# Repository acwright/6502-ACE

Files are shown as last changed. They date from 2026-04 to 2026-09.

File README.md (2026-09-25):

6502-ACE
========

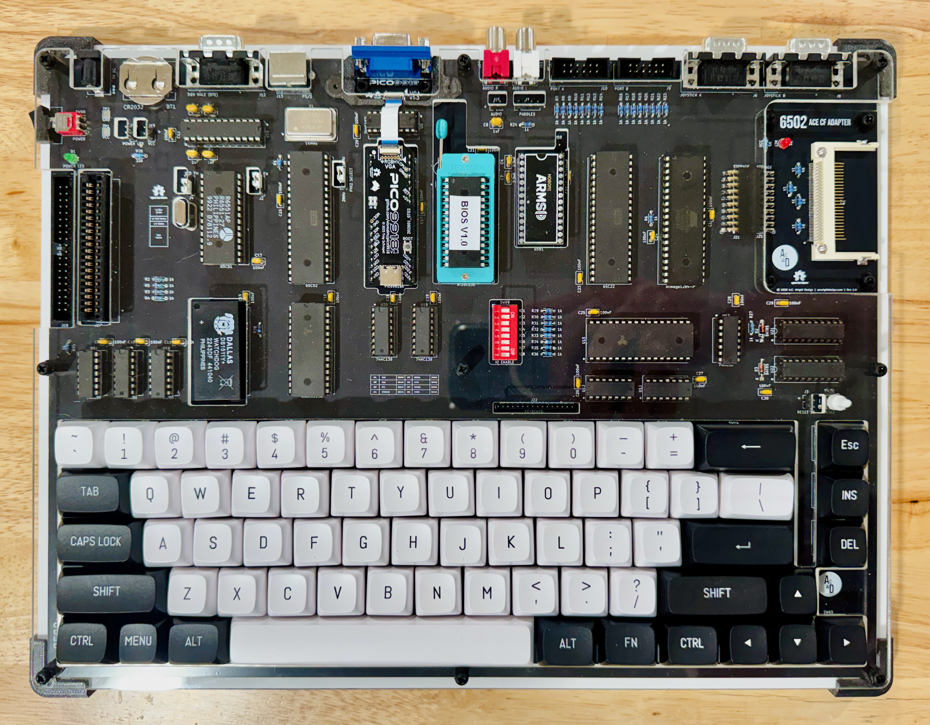
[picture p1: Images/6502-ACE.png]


An **AC6502** retro-style 8-bit computer based on the **65C02** microprocessor.

> 📖 **Guide:** [AC6502 Documentation](https://acwright.github.io/6502-DOCS/) — the user's and programmer's guide for the whole family.
> Start with [Your ACE](https://acwright.github.io/6502-DOCS/your-ace), the tour of this board.

---

## Table of Contents

- [Overview](#overview)
- [Architecture](#architecture)
- [Systems](#systems)
- [Software](#software)
- [Hardware](#hardware)
  - [ACE Board](#ace-board)
    - [Revision History](#revision-history)
  - [ACE CF Adapter](#ace-cf-adapter)
  - [ACE RAM Patch](#ace-ram-patch)
- [Firmware](#firmware)
  - [AB Controller](#ab-controller)
- [CAD](#cad)
- [Production](#production)
- [Schematics](#schematics)
- [Checking the schematics](#checking-the-schematics)
- [Libraries](#libraries)
- [Bill of Materials](#bill-of-materials)
  - [ACE Board](#ace-board-1)
  - [ACE CF Adapter](#ace-cf-adapter-1)
  - [ACE RAM Patch](#ace-ram-patch-1)
- [License](#license)

---

## Overview

The AC6502 ecosystem is a family of open-source, 65C02-based computers sharing a common architecture, memory map, and [BIOS](https://github.com/acwright/6502-BIOS). Each computer in the family is purpose-built for a different use case but runs the same software and firmware.

The **ACE** (All-in-one Computer Experience) is a complete, self-contained 65C02 computer on a single PCB. It integrates everything found across the COB's modular cards — CPU, memory, video, audio, storage, serial, GPIO, RTC, and keyboard controller — onto one board, delivering the full experience without a backplane or expansion cards.

## Architecture

All AC6502 computers share:

- **CPU**: 65C02 (or accurate emulation)
- **Memory**: 32KB RAM + 32KB ROM, with optional banked RAM expansion
- **Memory Map**: Standardized across the ecosystem — zero page, stack, I/O space ($8000–$9FFF), system ROM, and interrupt vectors at $FFFA–$FFFF
- **Bus**: 16-bit address bus, 8-bit bidirectional data bus, standard 65C02 control signals (RW, PHI2, RESET, IRQ, NMI, RDY, SYNC)
- **BIOS**: A common [BIOS](https://github.com/acwright/6502-BIOS) provides the kernel, monitor, and BASIC interpreter across all systems

## Systems

| Project | Description |
|---|---|
| [6502-ACE](https://github.com/acwright/6502-ACE) | All-in-one Computer Experience — A single board computer (YOU ARE HERE) |
| [6502-COB](https://github.com/acwright/6502-COB) | Computer On a Backplane — Modular desktop computer with expandable card slots |
| [6502-DEV](https://github.com/acwright/6502-DEV) | Development Environment Vehicle — Emulation-based dev system |
| [6502-KIM](https://github.com/acwright/6502-KIM) | Keypad Input Monitor - KIM-1 inspired minimal computer |
| [6502-VCS](https://github.com/acwright/6502-VCS) | Video Computer System — Cartridge-based retro gaming console |

## Software

| Project | Description |
|---|---|
| [6502-BIOS](https://github.com/acwright/6502-BIOS) | The shared BIOS (kernel, monitor, BASIC) for all AC6502 computers |
| [6502-EMULATOR](https://github.com/acwright/6502-EMULATOR) | Emulator for the whole family — desktop app, browser build, and a command line for scripted runs |
| [6502-PRG](https://github.com/acwright/6502-PRG) | Template project for writing assembly language programs |
| [6502-CRT](https://github.com/acwright/6502-CRT) | Template project for writing assembly language cartridges |
| [6502-ASM](https://github.com/acwright/6502-ASM) | Assembly language example programs and demos |
| [6502-BAS](https://github.com/acwright/6502-BAS) | BASIC program listings |
| [6502-WOZMON](https://github.com/acwright/6502-WOZMON) | Wozmon as a standalone ROM |
| [6502-NOP](https://github.com/acwright/6502-NOP) | An all-NOP ROM, for probing a board during bring-up |
| [6502-DOCS](https://github.com/acwright/6502-DOCS) | The documentation site — the guide, the printable reference cards, branding and label artwork |
| [cffs](https://github.com/acwright/cffs) | Builds CompactFlash disk images for the BIOS filesystem |
| [bastok](https://github.com/acwright/bastok) | Tokenizes BASIC listings into `.prg` images, and back |
| [bin2woz](https://github.com/acwright/bin2woz) | Converts a binary into a Wozmon serial upload |

## Hardware

This repository contains KiCad 7.0+ PCB designs for the ACE board.

### ACE Board
`Hardware/ACE Board/`

The single integrated board hosting the W65C02S CPU and all peripherals. Provides:

- **CPU**: W65C02S running at 1 MHz
- **RAM**: 32KB SRAM (62256) + Optional 512K banked SRAM (AS6C4008)
- **ROM**: 32KB EEPROM (28C256)
- **Video**: Pico9918 (VGA 640×480)
- **Audio**: ARMSID SID chip emulator (3-voice synthesis, RCA output)
- **Storage**: Storage adapter socket
- **Serial**: 65C51 ACIA with MAX238 level shifter (RS-232 via DB9, 50–19200 baud). Male DB-9 wired
  as **DTE**, like a PC, so reaching a laptop needs a **null-modem** cable. `RTS`, `DTR` and `DSR`
  always reach the cable; the `CTS EN` and `DCD EN` jumpers (J2 and J4 on Rev 1.0, J1 and J3 on Rev 1.1) pick ground or the cable for
  those two inputs — **both default to ground**
- **GPIO**: 65C22 VIA (20 GPIO pins, 2× 16-bit timers, shift register)
- **RTC**: DS1511Y real-time clock with battery-backed NVRAM
- **Keyboard Controller**: ATmega1284P running AB Controller firmware
- **Input**: PS/2 keyboard connector and 8×8 keyboard matrix header
- **Joystick**: Two Atari 2600-compatible joystick ports (JOYSTICK A on VIA PORT A and JOYSTICK B on VIA PORT B — `J6` and `J8` on Rev 1.0, `J5` and `J7` on Rev 1.1), read as `JOY(2)` and `JOY(1)` respectively
- **Clock**: 16 MHz DIP-14 full can oscillator (X1); drives the ATmega1284 at 16 MHz and, through the 74HC163 divider (U5), the 65C02, VIA, ACIA and SID at 1 MHz. Rev 1.0 has a PHI2 SELECT jumper (J1) that offers 2 MHz; keep it on 1 MHz (pins 1 and 2), because at 2 MHz the SID, whose clock is always 1 MHz, answers only every other CPU cycle

**The serial handshake jumpers.** `CTS EN` and `DCD EN` (J2 and J4 on Rev 1.0, J1 and J3 on Rev 1.1) both default to **ground**, and
that is how the boards were built. Ground means the line is permanently asserted, so the ACIA can
always send and always receive. Moved to the cable, they do real work — measured on a real R6551 in
2026: `CTS` high stops the transmitter dead and `DCD` high stops the receiver, losing the byte that
arrives. A board jumpered to the cable and plugged into something that does not assert those lines
shows no banner and no echo at all, and looks broken when it is not.
- **Reset**: Manual reset button (SW17, just above <kbd>Esc</kbd>) connected to the ATmega1284, which also provides power-on reset to the 65C02
- **Power**: 5V DC via barrel jack

#### Revision History

**Rev 1.1**

- Fixes the gating of the `LOADL` and `LOADH` latch-enable signals for the 74HC573 latches (`U21`, `U22`) that drive the AS6C4008 banked SRAM. In Rev 1.0 the final two decode gates (`U13C`/`U13D`) were NANDs, which left the latches pulsing while idle and allowed spurious loads on reads, so the latches never reliably held a bank value.
- The fix replaces the final NAND stage with a NOR function: `LOADL = NOR(SEL_L, WB)` and `LOADH = NOR(SEH_L, WB)`, holding each latch enable low out of window and only pulsing on an in-window write. This makes banked RAM work correctly with no firmware change.
- Implemented with one 74HC02 quad NOR beside the 74HC00 `U12`. Rev 1.0's second 74HC00 in this path is gone, and its designator, `U13`, now belongs to the 74HC02. Every gate of both chips is in use — the same eight gates as the ACE RAM Patch Rev 1.1: `U12A` makes `/(A9·A8)`; `U13C` NORs it with `U17`'s `/(A0–A7)` to select the bank register; `U13D` makes IO1 from `IO1B` and `U12D` makes `B18` from `IO2B`; `U12B` and `U12C` combine the select with IO1 and with `B18`; and `U13A` and `U13B` NOR those with `WB` to make `LOADL` and `LOADH`.
- Fixes the bank register's address decode. `U12B` combined `/(A9·A8)` (`U12A`) and `/(A0–A7)` (`U17`) with a NAND, which ORs the two conditions, so each latch also loaded on every write to `$8300`–`$83FE` and `$80FF`, `$81FF`, `$82FF` (and the same in the `$8400` window). `U13C` now combines them with a NOR, so each latch loads only on a write to `$83FF` or `$87FF`.
- Runs at 1 MHz only. The PHI2 SELECT jumper (Rev 1.0's J1) is removed, and U5's 1 MHz output (Q3) drives PHI2 for the 65C02, VIA, ACIA and SID.
- Adds `D1` (BAT85) between the video card's `/INT` (U3 pin 16) and `IRQB`, cathode toward U3. The Pico9918 drives `/INT` high as well as low, and without the diode it held `IRQB` high against every other interrupt source.
- Adds `R5`, a 10kΩ pull-up on `RESB`. The AB Controller firmware now only ever pulls `RESB` low, so the DS1511Y and cards on `CART` and `BUS` can reset the machine too.
- `Tests/check-schematics.mjs` checks the address decoding of Rev 1.1, and of Rev 1.0 with the ACE RAM Patch Rev 1.1 fitted, in every bus state. See [Checking the schematics](#checking-the-schematics).
- Some pull-up resistors changed from 1kΩ to 10kΩ: `R1`–`R4` and `R26` (Rev 1.0's `R25`) are now 10kΩ.
- Added `C20` (10µF electrolytic) at the power input for bulk decoupling capacitance.
- Re-annotated. Removing J1 and U13, and adding D1 and R5, renumbered the parts after them: in Rev 1.0's terms, the connectors `J2`–`J22` are now `J1`–`J21`, the diodes `D1`–`D3` are `D2`–`D4`, the resistors `R5`–`R34` are `R6`–`R35`, and the capacitors `C20`–`C30` are `C21`–`C31`, with the new bulk capacitor at `C20`. The 74HC02 is `U13`.

**Rev 1.0**

- Initial release.

### ACE CF Adapter
`Hardware/ACE CF Adapter/`

A CompactFlash adapter board that connects to the Storage header on the ACE Board. Provides:

- **Interface**: 8-bit IDE (True IDE) mode
- **Storage**: CompactFlash socket. The BIOS filesystem divides the card into 256 disk banks of 1 MB each, so 256 MB is the usable capacity regardless of the card fitted

### ACE RAM Patch
`Hardware/ACE RAM Patch/`

A patch board for Rev 1.0 of the ACE Board that corrects the extended RAM (banked SRAM) decoding, with the same logic as Rev 1.1. U12 and U13 come off the ACE, chips and sockets, and the patch is soldered underneath in their place. Provides:

- **Fix**: `LOADL` and `LOADH` go high only on a write to the bank register, `$83FF` or `$87FF`, while PHI2 is high. Rev 1.0 pulsed both latches whenever the bus was idle, and the first patch (Rev 1.0) fixed that but still loaded a latch on any write to `$8300`–`$83FE` and `$80FF`–`$82FF` (and the same in the `$8400` window)
- **Interface**: two DIP-14 footprints of pin headers, J1 into U12's holes and J2 into U13's, soldered on both boards. The patch mounts front side up under the ACE, so its layout is not mirrored; U13's pin 1 is 23.00 mm from U12's pin 1 along the row
- **Layout**: U1, J1, J2 and U2 in one row, 92.6 × 13.1 mm. J1 and J2 are on the front, facing the ACE; U1 (74HC00) and U2 (74HC02) are on the back, hanging below, so trim their leads flush on the front. The patch hangs about 8.5 mm below the ACE: the header, the board, and the chips
- **Rev 1.1**: replaces the Rev 1.0 patch, which plugged into U13 alone

## Firmware

This repository contains [PlatformIO](https://platformio.org/)-based firmware for the ACE board.

### AB Controller
`Firmware/AB Controller/`

Firmware for the ATmega1284P keyboard controller on the ACE board. Provides:

- Dual keyboard input: PS/2 and 8×8 matrix keyboard simultaneously
- PS/2 scancode to ASCII conversion
- Matrix keyboard scanning with hardware debouncing
- Modifier key support: Shift (symbols/punctuation) and Ctrl (control codes)
- Buffered output via 65C22 VIA with CA1/CB1 data-ready strobes
- Independent enable/disable for PS/2 and matrix inputs, releasing PORT A / PORT B so the 6502 can read the joysticks that share them
- 6502 reset control: drives `RESB` on PC7, holding the CPU in reset for ~250 ms at power-on, and debounces the reset button on PC0
- Optional jiffy clock: pulses `NMIB` from the DS1511Y SQW input; compiled out unless `ENABLE_SQW` is defined

See [Firmware/AB Controller/README.md](./Firmware/AB%20Controller/README.md) for setup and usage instructions.

## CAD
`CAD/`

3D-printable enclosure bases and laser-cut top panels for the ACE system.

## Production
`Production/`

JLCPCB-ready Gerber files and BOM/CPL for PCB fabrication and assembly.

## Schematics
`Schematics/`

PDF schematics for the ACE board.

## Checking the schematics
`Tests/check-schematics.mjs`

The banked RAM's latch enables were wrong in Rev 1.0, and wrong again in a different way in the first RAM Patch, and both times the gates looked right on paper. This script checks the logic instead of reading it. It asks KiCad for each board's netlist, builds the glue logic from the gates it finds there, and drives every address, as a read and as a write, with PHI2 high and low and with a cartridge in and out. That is 524,288 bus states per board. For each one it compares every chip select, read and write strobe, and bank latch enable against the memory map, and checks that exactly one chip drives the data bus on a read and exactly one takes a write. A net that nothing drives counts as a failure, so a missing wire fails too.

It checks two boards: Rev 1.1, and Rev 1.0 with the ACE RAM Patch Rev 1.1 fitted. The patch's headers name the sockets they plug into (`74HC00 (U12)`), and the script pulls those chips and joins each header pin to its socket's net. For Rev 1.1 it also checks that the CPU, VIA, ACIA and SID all run from U5's 1 MHz output, that the video card's `/INT` reaches `IRQB` only through a diode, and that `RESB` has a pull-up.

Run it after any change to either schematic:

```sh
node Tests/check-schematics.mjs
```

It needs Node.js and KiCad's `kicad-cli`, which it finds on the `PATH`, at the macOS default location, or through a `KICAD_CLI` environment variable. It takes about 15 seconds, prints `ok` or `FAIL` for each check with example bus states for any failure, and exits non-zero on a failure.

## Libraries
`Libraries/`

Shared KiCad symbol and footprint libraries used across all AC6502 hardware projects.

## Bill of Materials

### ACE Board

Rev 1.1's designators. Rev 1.0's are in `Production/ACE Board/Rev 1.0/bom.csv`.

| Reference | Qty | Value | Description | DigiKey | Mouser | Other |
|---|-----|---|---|---|---|---|
| BT1 | 1 | CR2032 | Battery Holder | [BAT-HLD-001-THM-ND](https://www.digikey.com/en/products/filter?keywords=BAT-HLD-001-THM-ND) | [712-BAT-HLD-001-THM](https://www.mouser.com/ProductDetail/712-BAT-HLD-001-THM) | |
| C1, C9–C19, C21–C31 | 23 | 100nF | Disc Capacitor | [478-5732-ND](https://www.digikey.com/en/products/filter?keywords=478-5732-ND) | | [AMAZON](https://www.amazon.com/PANMILED-Multilayer-Monolithic-Capacitors-Assortment/dp/B0CYQ1Z4G5) |
| C2, C3, C5, C6, C8 | 5 | 1µF | Disc Capacitor | [478-7667-ND](https://www.digikey.com/en/products/filter?keywords=478-7667-ND) | | [AMAZON](https://www.amazon.com/PANMILED-Multilayer-Monolithic-Capacitors-Assortment/dp/B0CYQ1Z4G5) |
| C4, C7 | 2 | 2.2nF | Disc Capacitor | [478-SR151C222KAATR1CT-ND](https://www.digikey.com/en/products/filter?keywords=478-SR151C222KAATR1CT-ND) | | [AMAZON](https://www.amazon.com/PANMILED-Multilayer-Monolithic-Capacitors-Assortment/dp/B0CYQ1Z4G5) |
| C20 | 1 | 10uF | Electrolytic Capacitor 16v | [P966-ND](https://www.digikey.com/en/products/filter?keywords=P966-ND) | | [AMAZON](https://www.amazon.com/Tnisesm-Electrolytic-Capacitor-Assortment-Capacitors/dp/B0G5X62C69) |
| D2 | 1 | LED | 3.0mm Power LED | [732-5008-ND](https://www.digikey.com/en/products/filter?keywords=732-5008-ND) | | [AMAZON](https://www.amazon.com/300-Pcs-LED-Diode-Assortment/dp/B0F38LJDJB) |
| D1, D3, D4 | 3 | BAT85 | Schottky Diode | [BAT85SCT-ND](https://www.digikey.com/en/products/filter?keywords=BAT85SCT-ND) | [78-BAT85S](https://www.mouser.com/ProductDetail/78-BAT85S) | [AMAZON](https://www.amazon.com/gp/product/B0CKSNPVH8) |
| J1 | 1 | CTS EN | Pin Header 1×3 2.54mm | | | [AMAZON](https://www.amazon.com/Straight-Breakaway-Connector-Breadboard-Electronic/dp/B0FRZW75VS) |
| J2 | 1 | RESET SW | Pin Header 1×2 2.54mm | | | [AMAZON](https://www.amazon.com/Straight-Breakaway-Connector-Breadboard-Electronic/dp/B0FRZW75VS) |
| J3 | 1 | DCD EN | Pin Header 1×3 2.54mm | | | [AMAZON](https://www.amazon.com/Straight-Breakaway-Connector-Breadboard-Electronic/dp/B0FRZW75VS) |
| J4 | 1 | VDD | Pin Header 1×2 2.54mm | | | [AMAZON](https://www.amazon.com/Straight-Breakaway-Connector-Breadboard-Electronic/dp/B0FRZW75VS) |
| J5 | 1 | JOYSTICK A | DB-9 Male | [609-1481-ND](https://www.digikey.com/en/products/filter?keywords=609-1481-ND) | [649-D09P33E4GX00LF](https://www.mouser.com/ProductDetail/649-D09P33E4GX00LF) | |
| J6 | 1 | PADDLES | Pin Header 1×4 2.54mm | | | [AMAZON](https://www.amazon.com/Straight-Breakaway-Connector-Breadboard-Electronic/dp/B0FRZW75VS) |
| J7 | 1 | JOYSTICK B | DB-9 Male | [609-1481-ND](https://www.digikey.com/en/products/filter?keywords=609-1481-ND) | [649-D09P33E4GX00LF](https://www.mouser.com/ProductDetail/649-D09P33E4GX00LF) | |
| J8 | 1 | PORT B | Box Header 2×6 2.54mm | [2057-BHR-12-VUA-ND](https://www.digikey.com/en/products/filter?keywords=2057-BHR-12-VUA-ND) | | [AMAZON](https://www.amazon.com/uxcell-2-54mm-2x6-Pin-Straight-Connector/dp/B07DJYVZV2) |
| J9 | 1 | PORT A | Box Header 2×6 2.54mm | [2057-BHR-12-VUA-ND](https://www.digikey.com/en/products/filter?keywords=2057-BHR-12-VUA-ND) | | [AMAZON](https://www.amazon.com/uxcell-2-54mm-2x6-Pin-Straight-Connector/dp/B07DJYVZV2) |
| J10 | 1 | AUDIO L | RCA Jack | [PJRAN1X1U02X-ND](https://www.digikey.com/en/products/filter?keywords=PJRAN1X1U02X-ND) | [502-PJRAN1X1U02X](https://www.mouser.com/ProductDetail/502-PJRAN1X1U02X) | |
| J11 | 1 | DB9 MALE (DTE) | DB-9 Male | [609-1481-ND](https://www.digikey.com/en/products/filter?keywords=609-1481-ND) | [649-D09P33E4GX00LF](https://www.mouser.com/ProductDetail/649-D09P33E4GX00LF) | |
| J12 | 1 | PS/2 | 6-pin Mini-DIN | | [806-KMDGX-6S-BS](https://www.mouser.com/ProductDetail/806-KMDGX-6S-BS) | [AMAZON](https://www.amazon.com/dp/B08GS3QL7T) |
| J13 | 1 | KEYBOARD | Pin Header 1×16 2.00mm | | | [AMAZON](https://www.amazon.com/Straight-Breakaway-Connector-Breadboard-Electronic/dp/B0FRZW75VS) |
| J14 | 1 | AUDIO R | RCA Jack | [PJRAN1X1U03X-ND](https://www.digikey.com/en/products/filter?keywords=PJRAN1X1U03X-ND) | [502-PJRAN1X1U03X](https://www.mouser.com/ProductDetail/502-PJRAN1X1U03X) | |
| J15 | 1 | AUDIO | Pin Header 1×2 2.54mm | | | [AMAZON](https://www.amazon.com/Straight-Breakaway-Connector-Breadboard-Electronic/dp/B0FRZW75VS) |
| J16 | 1 | 5V DC | DC Barrel Jack | [2073-DCJ200-10-A-K1-K-ND](https://www.digikey.com/en/products/filter?keywords=2073-DCJ200-10-A-K1-K-ND) | [640-DCJ200-10-A-K1-K](https://www.mouser.com/ProductDetail/640-DCJ200-10-A-K1-K) | |
| J17 | 1 | CART | Card Edge 2×20 2.54mm | [A31723-ND](https://www.digikey.com/en/products/filter?keywords=A31723-ND) | [571-5-5530843-4](https://www.mouser.com/ProductDetail/571-5-5530843-4) | |
| J18 | 1 | BUS | Box Header 2×20 2.54mm | | | [AMAZON](https://www.amazon.com/Female-Headers-Connector-Header-Raspberry/dp/B07DNHS2SJ) |
| J19 | 1 | VCC | Pin Header 1×2 2.54mm | | | [AMAZON](https://www.amazon.com/Straight-Breakaway-Connector-Breadboard-Electronic/dp/B0FRZW75VS) |
| J20 | 1 | POWER LED | Pin Header 1×2 2.54mm | | | [AMAZON](https://www.amazon.com/Straight-Breakaway-Connector-Breadboard-Electronic/dp/B0FRZW75VS) |
| J21 | 1 | STORAGE | Pin Socket 2×10 2.54mm Horiz | [S5563-ND](https://www.digikey.com/en/products/filter?keywords=S5563-ND) | | |
| R1–R5, R26 | 6 | 10kΩ | 1/8W Resistor | [RNF18FTD10K0CT-ND](https://www.digikey.com/en/products/filter?keywords=RNF18FTD10K0CT-ND) | | [AMAZON](https://www.amazon.com/ALLECIN-8W-Metal-Film-Resistor/dp/B0C77TM3NR) |
| R6–R24, R27–R35 | 28 | 1kΩ | 1/8W Resistor | [RNF18FTD1K00CT-ND](https://www.digikey.com/en/products/filter?keywords=RNF18FTD1K00CT-ND) | | [AMAZON](https://www.amazon.com/ALLECIN-8W-Metal-Film-Resistor/dp/B0C77TM3NR) |
| R25 | 1 | 330Ω | 1/8W Resistor | | | [AMAZON](https://www.amazon.com/ALLECIN-8W-Metal-Film-Resistor/dp/B0C77TM3NR) |
| SW1–SW13, SW15, SW18–SW29, SW31, SW33–SW41, SW43, SW44, SW46–SW49, SW51–SW58, SW61, SW64–SW66 | 54 | Various | Cherry MX Switch 1.00u | [CH196-ND](https://www.digikey.com/en/products/filter?keywords=CH196-ND) | | [AMAZON](https://www.amazon.com/dp/B0FYR5TV3X) |
| SW59, SW60, SW63, SW67, SW68 | 5 | CTRL / ALT / FN | Cherry MX Switch 1.25u | [CH196-ND](https://www.digikey.com/en/products/filter?keywords=CH196-ND) | | [AMAZON](https://www.amazon.com/dp/B0FYR5TV3X) |
| SW16, SW30 | 2 | TAB / Backslash | Cherry MX Switch 1.50u | [CH196-ND](https://www.digikey.com/en/products/filter?keywords=CH196-ND) | | [AMAZON](https://www.amazon.com/dp/B0FYR5TV3X) |
| SW32 | 1 | CAPS LOCK | Cherry MX Switch 1.75u | [CH196-ND](https://www.digikey.com/en/products/filter?keywords=CH196-ND) | | [AMAZON](https://www.amazon.com/dp/B0FYR5TV3X) |
| SW14 | 1 | BACKSPACE | Cherry MX Switch 2.00u | [CH196-ND](https://www.digikey.com/en/products/filter?keywords=CH196-ND) | | [AMAZON](https://www.amazon.com/dp/B0FYR5TV3X) |
| SW42, SW45, SW50 | 3 | SHIFT / ENTER | Cherry MX Switch 2.25u | [CH196-ND](https://www.digikey.com/en/products/filter?keywords=CH196-ND) | | [AMAZON](https://www.amazon.com/dp/B0FYR5TV3X) |
| SW62 | 1 | SPACE | Cherry MX Switch 6.25u | [CH196-ND](https://www.digikey.com/en/products/filter?keywords=CH196-ND) | | [AMAZON](https://www.amazon.com/dp/B0FYR5TV3X) |
| SW17 | 1 | RESET | Tact Push Button 6mm | | | [AMAZON](https://www.amazon.com/QTEATAK-Momentary-Tactile-Button-Switch/dp/B07VSNN9S2) |
| SW69 | 1 | POWER | SPDT Switch | [EG4326-ND](https://www.digikey.com/en/products/filter?keywords=EG4326-ND) | [612-400MSP1R6BLKM6QE](https://www.mouser.com/ProductDetail/612-400MSP1R6BLKM6QE) | |
| SW70 | 1 | IO ENABLE | 8× DIP Switch SPST | | | [AMAZON](https://www.amazon.com/Yohii-2-54mm-Positions-Double-Assorted/dp/B07DSBX4BK/) |
| U1 | 1 | W65C02S | 65C02 CPU | | [955-W65C02S6TPG-14](https://www.mouser.com/ProductDetail/955-W65C02S6TPG-14) | |
| U2 | 1 | W65C22 | 65C22 VIA | | [955-W65C22N6TPG-14](https://www.mouser.com/ProductDetail/955-W65C22N6TPG-14) | |
| U3 | 1 | Pico9918A | VDP (VGA) | | | [TINDIE](https://www.tindie.com/products/visrealm/pico9918-pro/) |
| U4 | 1 | 65C51 | ACIA | | | [JAMECO](https://www.jameco.com/z/R6551AP-Rockwell-IC-6551-Asynchronous-Communication-Interface-Adapter-DIP-28-pin_43318.html) |
| U5 | 1 | 74HC163 | 4-bit Counter | [296-8246-5-ND](https://www.digikey.com/en/products/filter?keywords=296-8246-5-ND) | [595-SN74HC163N](https://www.mouser.com/ProductDetail/595-SN74HC163N) | |
| U6 | 1 | ATmega1284-P | Keyboard Controller MCU | [ATMEGA1284-PU-ND](https://www.digikey.com/en/products/filter?keywords=ATMEGA1284-PU-ND) | [556-ATMEGA1284-PU](https://www.mouser.com/ProductDetail/556-ATMEGA1284-PU) | |
| U7 | 1 | AS6C62256 | 32KB SRAM | [1450-1033-ND](https://www.digikey.com/en/products/filter?keywords=1450-1033-ND) | [913-AS6C62256-55PCN](https://www.mouser.com/ProductDetail/913-AS6C62256-55PCN) | |
| U8 | 1 | AT28C256 | 32KB EEPROM | [AT28C256-15PU-ND](https://www.digikey.com/en/products/filter?keywords=AT28C256-15PU-ND) | [556-AT28C25615PU](https://www.mouser.com/ProductDetail/556-AT28C25615PU) | |
| U9 | 1 | 6581 | SID Chip | | | [LINK](https://retrocomp.cz/produkt?id=2) |
| U10 | 1 | MAX238xNG+ | RS-232 Transceiver | [MAX238CNG+-ND](https://www.digikey.com/en/products/filter?keywords=MAX238CNG+-ND) | [700-MAX238CNG](https://www.mouser.com/ProductDetail/700-MAX238CNG) | |
| U11, U12, U14, U16 | 4 | 74HC00 | Quad NAND | [296-1563-5-ND](https://www.digikey.com/en/products/filter?keywords=296-1563-5-ND) | [595-SN74HC00N](https://www.mouser.com/ProductDetail/595-SN74HC00N) | |
| U13 | 1 | 74HC02 | Quad NOR | [296-1565-5-ND](https://www.digikey.com/en/products/filter?keywords=296-1565-5-ND) | [595-SN74HC02N](https://www.mouser.com/ProductDetail/595-SN74HC02N) | |
| U15 | 1 | AS6C4008 | 512KB SRAM | [1450-1027-ND](https://www.digikey.com/en/products/filter?keywords=1450-1027-ND) | [913-AS6C4008-55PCN](https://www.mouser.com/ProductDetail/913-AS6C4008-55PCN) | |
| U17 | 1 | 74HC30 | 8-input NAND | [296-9196-5-ND](https://www.digikey.com/en/products/filter?keywords=296-9196-5-ND) | [595-CD74HC30E](https://www.mouser.com/ProductDetail/595-CD74HC30E) | |
| U18 | 1 | DS1511Y | RTC + NVRAM | [DS1511Y+-ND](https://www.digikey.com/en/products/filter?keywords=DS1511Y+-ND) | [700-DS1511Y](https://www.mouser.com/ProductDetail/700-DS1511Y) | |
| U19, U20 | 2 | 74HC138 | 3-to-8 Decoder | [296-1575-5-ND](https://www.digikey.com/en/products/filter?keywords=296-1575-5-ND) | [595-SN74HC138N](https://www.mouser.com/ProductDetail/595-SN74HC138N) | |
| U21, U22 | 2 | 74HC573 | Octal Latch | [296-12815-5-ND](https://www.digikey.com/en/products/filter?keywords=296-12815-5-ND) | [595-CD74HC573EE4](https://www.mouser.com/ProductDetail/595-CD74HC573EE4) | |
| X1 | 1 | 16MHz | DIP-14 Oscillator | [X947-ND](https://www.digikey.com/en/products/filter?keywords=X947-ND) | [815-ACO-16-EK](https://www.mouser.com/ProductDetail/815-ACO-16-EK) | |
| Y1 | 1 | 1.8432MHz | Crystal | [3155-1.8432M20P2/49U-ND](https://www.digikey.com/en/products/filter?keywords=3155-1.8432M20P2%2F49U-ND) | [815-AB-1.8432-B2](https://www.mouser.com/ProductDetail/815-AB-1.8432-B2) | |

### ACE CF Adapter

| Reference | Qty | Value | Description | DigiKey | Mouser | Other |
|---|-----|---|---|---|---|---|
| D1 | 1 | ACT LED | 3.0mm LED | [732-5008-ND](https://www.digikey.com/en/products/filter?keywords=732-5008-ND) | | [AMAZON](https://www.amazon.com/300-Pcs-LED-Diode-Assortment/dp/B0F38LJDJB) |
| J1 | 1 | STORAGE | Pin Header 2×10 2.54mm Horiz | | | [AMAZON](https://www.amazon.com/dp/B00W8TSWXS) |
| J2 | 1 | Compact Flash | CF Socket | [4827-101D-TAAB-R01-ND](https://www.digikey.com/en/products/filter?keywords=4827-101D-TAAB-R01-ND) | | |
| R1–R4 | 4 | 1kΩ | 1/8W Resistor | [RNF18FTD1K00CT-ND](https://www.digikey.com/en/products/filter?keywords=RNF18FTD1K00CT-ND) | | [AMAZON](https://www.amazon.com/ALLECIN-8W-Metal-Film-Resistor/dp/B0C77TM3NR) |
| R5 | 1 | 330Ω | 1/8W Resistor | | | [AMAZON](https://www.amazon.com/ALLECIN-8W-Metal-Film-Resistor/dp/B0C77TM3NR) |

### ACE RAM Patch

| Reference | Qty | Value | Description | DigiKey | Mouser | Other |
|---|-----|---|---|---|---|---|
| J1 | 1 | 74HC00 (U12) | Pin Header 1×7 2.54mm ×2, soldered between the boards | | | |
| J2 | 1 | 74HC00 (U13) | Pin Header 1×7 2.54mm ×2, soldered between the boards | | | |
| U1 | 1 | 74HC00 | Quad NAND | [296-1563-5-ND](https://www.digikey.com/en/products/filter?keywords=296-1563-5-ND) | [595-SN74HC00N](https://www.mouser.com/ProductDetail/595-SN74HC00N) | |
| U2 | 1 | 74HC02 | Quad NOR | [296-1565-5-ND](https://www.digikey.com/en/products/filter?keywords=296-1565-5-ND) | [595-SN74HC02N](https://www.mouser.com/ProductDetail/595-SN74HC02N) | |

## License

Hardware designs are released under the [CERN Open Hardware Licence Version 2 – Permissive](https://ohwr.org/cern_ohl_p_v2.txt).  
Firmware is released under the [MIT License](./Firmware/AB%20Controller/LICENSE).

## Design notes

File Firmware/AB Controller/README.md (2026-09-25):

# AB Controller

## Overview

The AB Controller is firmware for the ATMega1284P microcontroller that provides dual keyboard input support for 6502-based computer systems. It can simultaneously handle both PS/2 keyboard input and custom keyboard matrix input, converting keypresses to ASCII codes and outputting them through a 6522 VIA (Versatile Interface Adapter) interface.

## Features

- **Dual Input Support**: Handles both PS/2 keyboards and 8x8 keyboard matrix simultaneously
- **ASCII Conversion**: Converts PS/2 scancodes and matrix keypresses to ASCII characters
- **Always Uppercase Letters**: Letters are always output as uppercase ASCII regardless of modifiers
- **Modifier Keys**: Shift (symbols/numbers only) and Ctrl (control codes)
- **Buffered Input**: Uses circular buffers to prevent data loss during rapid typing
- **Debounced Matrix Scanning**: Hardware debouncing for reliable matrix keyboard operation
- **Enable/Disable Control**: Independent enable signals for PS/2 and matrix inputs
- **Shared Joystick Ports**: Releases PORT A / PORT B when disabled so the 6502 can read the two Atari 2600-compatible joysticks that share those ports
- **6502 Reset Control**: Drives the 6502 RESB line, providing power-on reset and a debounced reset button
- **Jiffy Clock (optional)**: Can generate periodic 6502 NMIs from a DS1511Y RTC square-wave input. Disabled by default; enabled at build time via the `ENABLE_SQW` define

## Hardware Connections

### ATMega1284P Pin Assignments

#### VIA PORT A (Pins 24-31)
Used for row scanning (matrix mode) or ASCII output (PS/2 mode):
- PA0 (Pin 24) - VIA_PA0 / Row 0 / Data Bit 0
- PA1 (Pin 25) - VIA_PA1 / Row 1 / Data Bit 1
- PA2 (Pin 26) - VIA_PA2 / Row 2 / Data Bit 2
- PA3 (Pin 27) - VIA_PA3 / Row 3 / Data Bit 3
- PA4 (Pin 28) - VIA_PA4 / Row 4 / Data Bit 4
- PA5 (Pin 29) - VIA_PA5 / Row 5 / Data Bit 5
- PA6 (Pin 30) - VIA_PA6 / Row 6 / Data Bit 6
- PA7 (Pin 31) - VIA_PA7 / Row 7 / Data Bit 7

#### VIA PORT B (Pins 0-7)
Used for column scanning (matrix mode) or ASCII output (matrix output):
- PB0 (Pin 0) - VIA_PB0 / Column 0 / Data Bit 0
- PB1 (Pin 1) - VIA_PB1 / Column 1 / Data Bit 1
- PB2 (Pin 2) - VIA_PB2 / Column 2 / Data Bit 2
- PB3 (Pin 3) - VIA_PB3 / Column 3 / Data Bit 3
- PB4 (Pin 4) - VIA_PB4 / Column 4 / Data Bit 4
- PB5 (Pin 5) - VIA_PB5 / Column 5 / Data Bit 5
- PB6 (Pin 6) - VIA_PB6 / Column 6 / Data Bit 6
- PB7 (Pin 7) - VIA_PB7 / Column 7 / Data Bit 7

#### Control Signals
- Pin 8 (VIA_CA1) - PS/2 Data Ready strobe (output)
- Pin 9 (VIA_CA2) - PS/2 Enable (input, active low)
- Pin 10 (PS2CLK) - PS/2 Clock input
- Pin 11 (PS2DATA) - PS/2 Data input
- Pin 12 (VIA_CB1) - Matrix Data Ready strobe (output)
- Pin 13 (VIA_CB2) - Matrix Enable (input, active low)

#### 6502 System Control
- PC0 (Pin 16) - RESET_BTN / Reset button (input, N.O., active low, internal pull-up)
- PC7 (Pin 23) - RESB / 6502 reset output (active low)
- PD6 (Pin 14) - RTC_SQW / DS1511Y square-wave input (jiffy clock source)
- PD7 (Pin 15) - NMIB / 6502 non-maskable interrupt output (active low)

#### Clock
- XTAL1 - 16 MHz full-can oscillator module (external clock source)

### PS/2 Keyboard Interface

Connect a PS/2 keyboard to:
- **CLK**: Pin 10 (PS2CLK)
- **DATA**: Pin 11 (PS2DATA)
- **VCC**: +5V
- **GND**: Ground

### Keyboard Matrix Interface

The firmware supports an 8x8 keyboard matrix (64 keys maximum):
- **Rows**: Connected to PA0-PA7 (Pins 24-31)
- **Columns**: Connected to PB0-PB7 (Pins 0-7)

Each key connects a row to a column when pressed. The matrix is scanned with rows driven low and columns read with pull-ups.

### Joystick Interface

PORT A and PORT B are shared between this encoder and two Atari 2600-compatible
joysticks. Unlike COB's Keyboard Encoder Helper and VCS's Input Board, which
reach a stick through a helper board, the ACE Board carries its own DB-9s —
`J6` JOYSTICK A and `J8` JOYSTICK B — with the 1kΩ pull-ups fitted on board
(`R6`–`R13` on PORT A, `R14`–`R21` on PORT B). The same port lines are also
brought out on the `J9` PORT B / `J10` PORT A 2×6 box headers. Those are Rev 1.0's
designators, which this section uses throughout; on Rev 1.1 the joysticks are `J5`
and `J7`, the box headers `J8` PORT B and `J9` PORT A, and the pull-ups `R7`–`R14`
and `R15`–`R22`.

The BIOS reads the two sticks through those same ports:

| BIOS routine | BASIC | VIA port | ACE connector | Encoder released by |
|---|---|---|---|---|
| `ReadJoystick1` (`$A048`) | `JOY(1)` | PORT B | `J8` JOYSTICK B | `CB2` high — matrix encoder off |
| `ReadJoystick2` (`$A04B`) | `JOY(2)` | PORT A | `J6` JOYSTICK A | `CA2` high — PS/2 encoder off |

> Note the naming trap: `J6` *JOYSTICK A* is PORT A, which is `JOY(2)`, and `J8`
> *JOYSTICK B* is PORT B, which is `JOY(1)`.

Each read returns the port raw, as a bitmask:

```
Bit:  7   6   5   4   3   2   1   0
      R   L   D   U   Y   X   B   A
```

The ports are **active low** — every line is pulled high and grounded by the
stick's switch — so a held button reads `0` and an untouched stick reads `$FF`.

Both DB-9s are wired the same way:

| DB-9 pin | Function | `J6` (PORT A) | `J8` (PORT B) |
|---|---|---|---|
| 1 | Up | PA4 | PB4 |
| 2 | Down | PA5 | PB5 |
| 3 | Left | PA6 | PB6 |
| 4 | Right | PA7 | PB7 |
| 5 | Y | PA3 | PB3 |
| 6 | A (fire) | PA0 | PB0 |
| 7 | B | PA1 | PB1 |
| 8 | GND | GND | GND |
| 9 | X | PA2 | PB2 |

Pins 1–4, 6 and 8 match a standard Atari 2600 stick. Pins 5, 7 and 9 carry the
extra Y, B and X buttons rather than the 2600's paddle pots and +5V, so a
2600 stick works with A/fire only, and nothing on the connector sources power.

This is the firmware's obligation in the joystick path: when `CA2` or `CB2`
goes high, it releases the corresponding port within 100 µs so the 6502 can
read the stick directly — the same arrangement a C64 has with a CIA port.
`disablePS2()` releases PORT A and `disableMatrix()` releases PORT B, both by
returning the pins to `INPUT_PULLUP` rather than bare `INPUT`, so an untouched
stick reads `$FF` even on a board relying on the pull-up alone.

The BIOS reads a stick as `KBDisable` → settle → read the port directly →
`KBEnable`. Nothing is transmitted over the shared lines, so there is nothing
for one stick to corrupt on the other's behalf — **both sticks read correctly
even when held at the same time.** An earlier design had the encoder push
joystick state to the 6502 as control bytes over the keyboard channel instead;
that could not report a held button on the port it was reporting over, and was
abandoned. See the BIOS commit that made the change,
[`d0cec53`](https://github.com/acwright/6502-BIOS/commit/d0cec53e557c0937f50ea427d2a50a2d57b4f720),
for the full account.

**Measured release latency: to be measured later.** This is the figure the
BIOS's `KBDisable` settle wait is sized against. Cycle-counting the compiled
firmware puts the worst-case code path at ~17 µs against a 100 µs budget, but
that excludes a PS/2 interrupt landing in the window and says nothing about how
long the bus takes to charge through a pull-up, so the published number comes
from a scope. See [PLAN.md](../../PLAN.md).

## Keyboard Matrix Layout

```
       PB0    PB1    PB2    PB3    PB4    PB5    PB6    PB7
PA0:    `      1      2      3      4      5      6      7
PA1:    8      9      0      -      =      BS     ESC    TAB
PA2:    Q      W      E      R      T      Y      U      I
PA3:    O      P      [      ]      \      INS    CAPS   A
PA4:    S      D      F      G      H      J      K      L
PA5:    ;      '    ENTER   DEL   SHIFT    Z      X      C
PA6:    V      B      N      M      ,      .      /      UP
PA7:  CTRL   MENU    ALT   SPACE   FN    LEFT   DOWN  RIGHT
```

**Special Keys:**
- BS = Backspace (0x08)
- ESC = Escape (0x1B)
- TAB = Tab (0x09)
- INS = Insert (0x1A)
- DEL = Delete (0x7F)
- ENTER = Enter (0x0D)
- Arrow keys: UP (0x1E), LEFT (0x1C), DOWN (0x1F), RIGHT (0x1D)

**Ignored Keys:**
- Caps Lock, Menu/GUI, Alt, Fn — produce no output and track no state

## Operation Modes

### PS/2 Mode
When VIA_CA2 (Pin 9) is pulled LOW:
- PS/2 keyboard is enabled
- Scancodes are converted to ASCII
- Output appears on PORT A (PA0-PA7)
- VIA_CA1 pulses low when data is ready

### Matrix Mode
When VIA_CB2 (Pin 13) is pulled LOW:
- Matrix keyboard is enabled
- Matrix is scanned every 10ms
- Keys are debounced (stable for 2 scans)
- Output appears on PORT B (PB0-PB7)
- VIA_CB1 pulses low when data is ready

### Dual Mode
Both keyboards can operate simultaneously if both enable signals are active.

### Joystick Reads
When an enable signal goes HIGH the firmware releases that port so the joystick
sharing it can be read by the 6502 — see [Joystick Interface](#joystick-interface).

## 6502 System Control

In addition to keyboard input, the controller manages reset and interrupt timing
for the host 6502.

### Reset Control (RESB)

The controller drives the 6502 RESB line on PC7 (active low):

- **Power-on reset**: At startup RESB is asserted immediately and held low for
  ~250 ms (`POR_HOLD_MS`) so the supply rails and 16 MHz oscillator stabilize
  before the 6502 begins executing.
- **Reset button**: A normally-open, active-low button on PC0 (internal pull-up)
  is polled and debounced (`RESET_DEBOUNCE_MS`, ~20 ms). While the button is
  held, RESB is asserted; releasing it brings the 6502 out of reset.

PC7 drives RESB open-drain. To assert reset, the firmware makes PC7 an output
and drives it low. To release reset, it makes PC7 an input with the ATmega's
internal pull-up on, and never drives it high. RESB is shared with the DS1511Y's
open-drain RST output and with the CART and BUS connectors, and each of those
must be able to pull RESB low while the controller is not asserting reset. The
internal pull-up raises RESB on its own; Rev 1.1 adds a 10 kΩ pull-up on the
board as well.

### Jiffy Clock (NMIB)

> **Disabled by default.** SQW-driven NMI behavior is only compiled in when the
> `ENABLE_SQW` define is enabled (see [Enabling the Jiffy Clock](#enabling-the-jiffy-clock)).
> When it is disabled, NMIB (PD7) is configured as a high-impedance input and is
> held high by the physical pull-up resistor on the PCB, so the 6502 never
> receives an NMI from this board.

When enabled, a DS1511Y RTC drives a square wave into PD6 (RTC_SQW). A pin-change
interrupt counts the rising edges and, every `JIFFY_DIVIDER` edges (default 1),
pulses the 6502 NMIB line on PD7 low for ~5 µs. The NMI is generated directly in
the ISR so its timing is independent of keyboard-scanning load. PD7 drives NMIB
open-drain, like RESB: a pulse switches PD7 to an output driving low and back to
an input, and the PCB's pull-up raises the line. PD7 never drives NMIB high, so a
card on the CART or BUS connector can still raise its own NMI between pulses. Set the DS1511Y
SQW output rate (and `JIFFY_DIVIDER`) to obtain the desired jiffy tick frequency.

To protect the 6502 BIOS boot window from a power-up SQW burst (the DS1511Y
powers up with SQW in an undefined, battery-backed state that can default to
32.768 kHz), the interrupt is not armed immediately. Arming is deferred until
`SQW_BOOT_GRACE_MS` (~500 ms) after RESB is released, and is re-deferred each
time the reset button asserts reset.

#### Enabling the Jiffy Clock

The jiffy clock is off unless you opt in at build time. In
[src/main.cpp](src/main.cpp), uncomment the define near the top of the file:

```c
#define ENABLE_SQW
```

Then rebuild and re-flash the firmware. Leaving it commented out keeps NMIB as a
high-impedance input and compiles out all SQW-related code.

## ASCII Character Mapping

### Modifier Priority

1. **Ctrl** — If held, produce control code. Shift is ignored.
2. **Shift** — If held (no Ctrl), produce shifted symbol. Letters unaffected.
3. **Base** — No modifier: produce base ASCII (letters always uppercase).

### Control Characters (Ctrl+Key)

- Ctrl+2 = 0x00 (NUL)
- Ctrl+A-Z = 0x01-0x1A
- Ctrl+[ = 0x1B (ESC)
- Ctrl+\ = 0x1C (FS)
- Ctrl+] = 0x1D (GS)
- Ctrl+6 = 0x1E (RS)
- Ctrl+- = 0x1F (US)

### Shifted Symbols

Shift only affects number and symbol keys (not letters):

| Base | Shifted | | Base | Shifted |
|---|---|-|---|---|
| 1 → ! | 2 → @ | | 3 → # | 4 → $ |
| 5 → % | 6 → ^ | | 7 → & | 8 → * |
| 9 → ( | 0 → ) | | - → _ | = → + |
| [ → { | ] → } | | \ → \| | ; → : |
| ' → " | , → < | | . → > | / → ? |
| ` → ~ | | | | |

### Printable Characters

Letters are always uppercase (A-Z). Numbers, symbols, space, and navigation keys follow standard ASCII.

## Build Instructions

### Prerequisites

1. **Install PlatformIO**
   ```bash
   # Using pip
   pip install platformio
   
   # Or install PlatformIO IDE extension for VS Code
   ```

2. **Install MiniPro Programmer Software** (for uploading)
   ```bash
   # macOS (using Homebrew)
   brew install minipro
   
   # Linux
   sudo apt-get install minipro
   
   # Or build from source: https://gitlab.com/DavidGriffith/minipro
   ```

### Building the Firmware

1. **Navigate to the project directory:**
   ```bash
   cd "Firmware/AB Controller"
   ```

2. **Build the firmware:**
   ```bash
   # Build for ATMega1284P (default)
   pio run -e atmega1284p
   
   # Or build for ATMega1284
   pio run -e atmega1284
   ```

3. **Build output:**
   The compiled firmware will be located at:
   ```
   .pio/build/atmega1284p/firmware.hex
   ```

### Uploading the Firmware

The project uses a MiniPro TL866 programmer for uploading.

1. **Connect the MiniPro programmer** to your ATMega1284P chip

2. **Upload firmware and fuses:**
   ```bash
   # Upload to ATMega1284P
   pio run -e atmega1284p -t upload
   
   # Or upload to ATMega1284
   pio run -e atmega1284 -t upload
   ```

3. **Manual upload (if needed):**
   ```bash
   # Flash the program
   minipro -p "ATMEGA1284P@DIP40" -c code -w .pio/build/atmega1284p/firmware.hex
   
   # Flash the fuses
   minipro -p "ATMEGA1284P@DIP40" -c config -w fuses.cfg --fuses
   ```

## Fuse Configuration

The `fuses.cfg` file contains the ATMega1284P fuse settings:

```properties
lfuse = 0xe0   # Low fuse
hfuse = 0xff   # High fuse  
efuse = 0xff   # Extended fuse
lock = 0xff    # Lock bits (unprogrammed, not written)
```

**Fuse Settings:**
- **Low Fuse (0xE0)**: External clock source (16 MHz full-can oscillator on
  XTAL1), slowly-rising-power start-up, no clock divide (CKDIV8 off), clock
  output disabled
- **High Fuse (0xFF)**: Default settings
- **Extended Fuse (0xFF)**: Default settings
- **Lock Bits (0xFF)**: No memory lock protection

> **Note**: The low fuse selects the *external clock* source, which is required
> for a full-can oscillator module driving XTAL1. Do not use a crystal-oscillator
> fuse setting with this hardware. The sibling boards — COB's `KEH Controller`
> and VCS's `IB Controller` — carry an HC49-U crystal across XTAL1/XTAL2 instead
> and therefore use the low power crystal setting (`lfuse = 0xFF`); the two are
> not interchangeable.

> **Note**: Lock bits are left unprogrammed on all of these boards. The upload
> command writes fuses only (`--fuses`, no `--lock`), so the `lock` line above is
> recorded for reference and never programmed.

⚠️ **Warning**: Incorrect fuse settings can brick your microcontroller. Verify fuse values are appropriate for your hardware configuration before programming.

## Dependencies

The firmware requires the following library (automatically installed by PlatformIO):

- **CircularBuffer** (v1.4.0+) by Roberto Lo Giacco
  - Provides interrupt-safe circular buffers for keyboard data

## Project Structure

```
AB Controller/
├── platformio.ini          # PlatformIO configuration
├── fuses.cfg              # AVR fuse configuration
├── src/
│   └── main.cpp           # Main firmware source code
├── include/               # Header files (if any)
├── lib/                   # Local libraries
└── test/                  # Unit tests
```

## Troubleshooting

### Build Issues

**Problem**: PlatformIO not found
```bash
# Solution: Install or update PlatformIO
pip install -U platformio
```

**Problem**: Library dependency errors
```bash
# Solution: Clean and rebuild
pio run -t clean
pio run
```

### Upload Issues

**Problem**: MiniPro not found
```bash
# Solution: Ensure minipro is installed and in PATH
which minipro
```

**Problem**: Chip not detected
- Check that the chip is properly seated in the programmer
- Verify you're using the correct chip model (ATMEGA1284P vs ATMEGA1284)
- Check for proper power supply to the programmer

### Runtime Issues

**Problem**: No keyboard response
- Verify enable signals (CA2/CB2) are at correct logic levels
- Check PS/2 clock and data connections
- Verify matrix keyboard connections
- Ensure VIA interface connections are correct

**Problem**: `JOY(1)`/`JOY(2)` return keystrokes or a stuck value
- Confirm the BIOS is v1.5 or later — older BIOS reads the port before the
  encoder has released it (see [Joystick Interface](#joystick-interface))
- Verify the on-board 1kΩ pull-ups are fitted (`R6`–`R13` for PORT A / `J6`,
  `R14`–`R21` for PORT B / `J8` on Rev 1.0; `R7`–`R14` / `J5` and `R15`–`R22` / `J7`
  on Rev 1.1)

**Problem**: Incorrect characters output
- Check for proper pull-up resistors on PS/2 lines
- Verify keyboard matrix wiring matches the defined layout
- Test with a known-good PS/2 keyboard

## License

See the main repository LICENSE file for licensing information.

## Contributing

This firmware is part of the 6502 computer project. Contributions and improvements are welcome through the main repository.

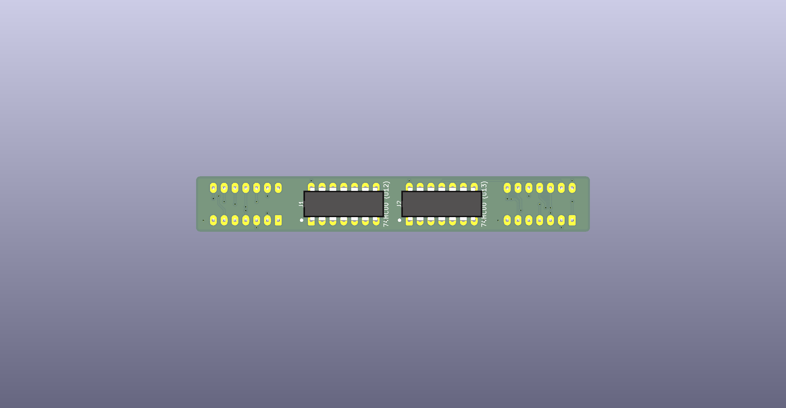
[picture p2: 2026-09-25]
CAD/Images/ACE RAM Patch/Rev 1.1/Front.png

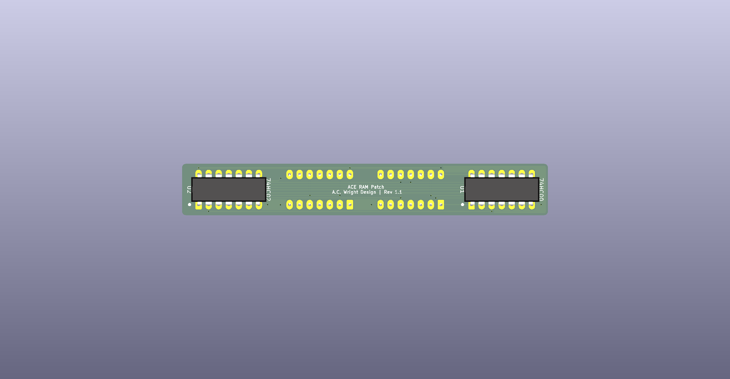
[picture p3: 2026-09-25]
CAD/Images/ACE RAM Patch/Rev 1.1/Back.png

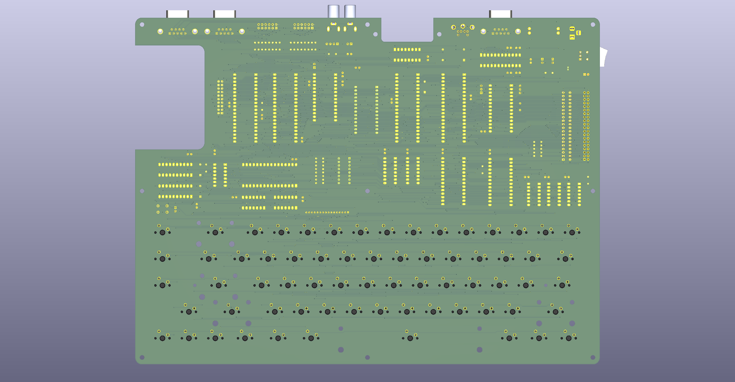
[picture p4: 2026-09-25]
CAD/Images/ACE Board/Rev 1.1/Back.png

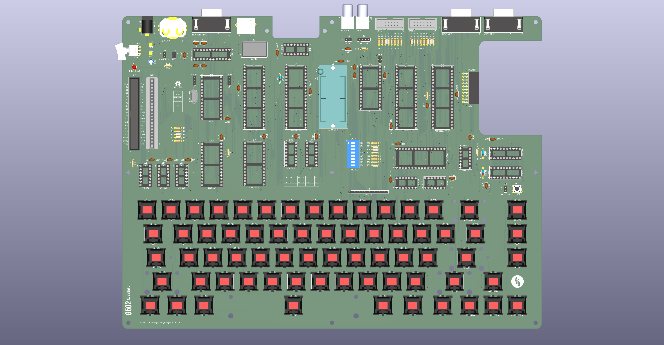
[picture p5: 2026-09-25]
CAD/Images/ACE Board/Rev 1.1/Front.png

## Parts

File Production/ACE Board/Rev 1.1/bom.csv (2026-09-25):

Designator | Footprint | Quantity | Value | LCSC Part #
BT1 | BAT_BAT-HLD-001-THM | 1 | CR2032 | BAT-HLD-001-THM
C1, C10, C11, C12, C13, C14, C15, C16, C17, C18, C19, C21, C22, C23, C24, C25, C26, C27, C28, C29, C30, C31, C9 | C_Disc_D5.0mm_W2.5mm_P2.50mm | 23 | 100nF
C2, C3, C5, C6, C8 | C_Disc_D5.0mm_W2.5mm_P2.50mm | 5 | 1uF
C20 | CP_Radial_D4.0mm_P1.50mm | 1 | 10uF
C4, C7 | C_Disc_D5.0mm_W2.5mm_P2.50mm | 2 | 2.2nF
D1, D3, D4 | D_DO-35_SOD27_P7.62mm_Horizontal | 3 | BAT85
D2 | LED_D3.0mm | 1 | POWER LED
J1 | PinHeader_1x03_P2.54mm_Vertical | 1 | CTS EN
J10 | SWITCHCRAFT_PJRAN1X1U0XX | 1 | AUDIO L
J11 | DSUB-9_Pins_Horizontal_P2.77x2.84mm_EdgePinOffset7.70mm_Housed_MountingHolesOffset9.12mm | 1 | DB9 MALE (DTE) | D09P33E4GX00LF
J12 | KMDGX-6S-BS | 1 | PS/2
J13 | PinHeader_1x16_P2.00mm_Vertical | 1 | KEYBOARD
J14 | SWITCHCRAFT_PJRAN1X1U0XX | 1 | AUDIO R
J15 | PinHeader_1x02_P2.54mm_Vertical | 1 | AUDIO
J16 | BarrelJack_Horizontal | 1 | 5V DC
J17 | RHDR40W82P485X254_2X20_5740X93 | 1 | CART
J18 | 6502 Bus Connector | 1 | BUS
J19 | PinHeader_1x02_P2.54mm_Vertical | 1 | VCC
J2 | PinHeader_1x02_P2.54mm_Vertical | 1 | RESET SW
J20 | PinHeader_1x02_P2.54mm_Vertical | 1 | POWER LED
J21 | PinSocket_2x10_P2.54mm_Horizontal | 1 | STORAGE | PPPC102LJBN-RC
J3 | PinHeader_1x03_P2.54mm_Vertical | 1 | DCD EN
J4 | PinHeader_1x02_P2.54mm_Vertical | 1 | VDD
J5 | DSUB-9_Pins_Horizontal_P2.77x2.84mm_EdgePinOffset7.70mm_Housed_MountingHolesOffset9.12mm | 1 | JOYSTICK A | D09P33E4GX00LF
J6 | PinHeader_1x04_P2.54mm_Vertical | 1 | PADDLES
J7 | DSUB-9_Pins_Horizontal_P2.77x2.84mm_EdgePinOffset7.70mm_Housed_MountingHolesOffset9.12mm | 1 | JOYSTICK B | D09P33E4GX00LF
J8 | 6502 GPIO Connector | 1 | PORT B
J9 | 6502 GPIO Connector | 1 | PORT A
R1, R2, R26, R3, R4, R5 | R_Axial_DIN0204_L3.6mm_D1.6mm_P5.08mm_Horizontal | 6 | 10k
R10, R11, R12, R13, R14, R15, R16, R17, R18, R19, R20, R21, R22, R23, R24, R27, R28, R29, R30, R31, R32, R33, R34, R35, R6, R7, R8, R9 | R_Axial_DIN0204_L3.6mm_D1.6mm_P5.08mm_Horizontal | 28 | 1k
R25 | R_Axial_DIN0204_L3.6mm_D1.6mm_P5.08mm_Horizontal | 1 | 330
SW1 | SW_Cherry_MX_1.00u_PCB | 1 | `
SW10 | SW_Cherry_MX_1.00u_PCB | 1 | 9
SW11 | SW_Cherry_MX_1.00u_PCB | 1 | 0
SW12 | SW_Cherry_MX_1.00u_PCB | 1 | -
SW13 | SW_Cherry_MX_1.00u_PCB | 1 | =
SW14 | SW_Cherry_MX_2.00u_PCB | 1 | BACKSPACE
SW15 | SW_Cherry_MX_1.00u_PCB | 1 | ESCAPE
SW16 | SW_Cherry_MX_1.50u_PCB | 1 | TAB
SW17 | SW_PUSH_6mm | 1 | RESET
SW18 | SW_Cherry_MX_1.00u_PCB | 1 | Q
SW19 | SW_Cherry_MX_1.00u_PCB | 1 | W
SW2 | SW_Cherry_MX_1.00u_PCB | 1 | 1
SW20 | SW_Cherry_MX_1.00u_PCB | 1 | E
SW21 | SW_Cherry_MX_1.00u_PCB | 1 | R
SW22 | SW_Cherry_MX_1.00u_PCB | 1 | T
SW23 | SW_Cherry_MX_1.00u_PCB | 1 | Y
SW24 | SW_Cherry_MX_1.00u_PCB | 1 | U
SW25 | SW_Cherry_MX_1.00u_PCB | 1 | I
SW26 | SW_Cherry_MX_1.00u_PCB | 1 | O
SW27 | SW_Cherry_MX_1.00u_PCB | 1 | P
SW28 | SW_Cherry_MX_1.00u_PCB | 1 | [
SW29 | SW_Cherry_MX_1.00u_PCB | 1 | ]
SW3 | SW_Cherry_MX_1.00u_PCB | 1 | 2
SW30 | SW_Cherry_MX_1.50u_PCB | 1 | \
SW31 | SW_Cherry_MX_1.00u_PCB | 1 | INSERT
SW32 | SW_Cherry_MX_1.75u_PCB | 1 | CAPS LOCK
SW33 | SW_Cherry_MX_1.00u_PCB | 1 | A
SW34 | SW_Cherry_MX_1.00u_PCB | 1 | S
SW35 | SW_Cherry_MX_1.00u_PCB | 1 | D
SW36 | SW_Cherry_MX_1.00u_PCB | 1 | F
SW37 | SW_Cherry_MX_1.00u_PCB | 1 | G
SW38 | SW_Cherry_MX_1.00u_PCB | 1 | H
SW39 | SW_Cherry_MX_1.00u_PCB | 1 | J
SW4 | SW_Cherry_MX_1.00u_PCB | 1 | 3
SW40 | SW_Cherry_MX_1.00u_PCB | 1 | K
SW41 | SW_Cherry_MX_1.00u_PCB | 1 | L
SW42, SW50 | SW_Cherry_MX_2.25u_PCB | 2 | SHIFT
SW43 | SW_Cherry_MX_1.00u_PCB | 1 | ;
SW44 | SW_Cherry_MX_1.00u_PCB | 1 | '
SW45 | SW_Cherry_MX_2.25u_PCB | 1 | ENTER
SW46 | SW_Cherry_MX_1.00u_PCB | 1 | DELETE
SW47 | SW_Cherry_MX_1.00u_PCB | 1 | Z
SW48 | SW_Cherry_MX_1.00u_PCB | 1 | X
SW49 | SW_Cherry_MX_1.00u_PCB | 1 | C
SW5 | SW_Cherry_MX_1.00u_PCB | 1 | 4
SW51 | SW_Cherry_MX_1.00u_PCB | 1 | V
SW52 | SW_Cherry_MX_1.00u_PCB | 1 | B
SW53 | SW_Cherry_MX_1.00u_PCB | 1 | N
SW54 | SW_Cherry_MX_1.00u_PCB | 1 | M
SW55 | SW_Cherry_MX_1.00u_PCB | 1 | ,
SW56 | SW_Cherry_MX_1.00u_PCB | 1 | .
SW57 | SW_Cherry_MX_1.00u_PCB | 1 | /
SW58 | SW_Cherry_MX_1.00u_PCB | 1 | UP ARROW
SW59, SW67 | SW_Cherry_MX_1.25u_PCB | 2 | CTRL
SW6 | SW_Cherry_MX_1.00u_PCB | 1 | 5
SW60, SW68 | SW_Cherry_MX_1.25u_PCB | 2 | ALT
SW61 | SW_Cherry_MX_1.00u_PCB | 1 | MENU
SW62 | SW_Cherry_MX_6.25u_PCB | 1 | SPACE
SW63 | SW_Cherry_MX_1.25u_PCB | 1 | FN
SW64 | SW_Cherry_MX_1.00u_PCB | 1 | LEFT ARROW
SW65 | SW_Cherry_MX_1.00u_PCB | 1 | DOWN ARROW
SW66 | SW_Cherry_MX_1.00u_PCB | 1 | RIGHT ARROW
SW69 | SW_400MSP1R6BLKM6QE | 1 | POWER
SW7 | SW_Cherry_MX_1.00u_PCB | 1 | 6
SW70 | SW_DIP_SPSTx08_Slide_9.78x22.5mm_W7.62mm_P2.54mm | 1 | IO ENABLE
SW8 | SW_Cherry_MX_1.00u_PCB | 1 | 7
SW9 | SW_Cherry_MX_1.00u_PCB | 1 | 8
U1 | DIP-40_W15.24mm_Socket_LongPads | 1 | 65C02
U10 | DIP-24_W7.62mm_Socket_LongPads | 1 | MAX238xNG+
U11, U12, U14, U16 | DIP-14_W7.62mm_Socket_LongPads | 4 | 74HC00
U13 | DIP-14_W7.62mm_Socket_LongPads | 1 | 74HC02
U15 | DIP-32_W15.24mm_Socket_LongPads | 1 | AS6C4008
U17 | DIP-14_W7.62mm_Socket_LongPads | 1 | 74HC30
U18 | DIP-28_W15.24mm_Socket_LongPads | 1 | DS1511Y
U19, U20 | DIP-16_W7.62mm_Socket_LongPads | 2 | 74HC138
U2 | DIP-40_W15.24mm_Socket_LongPads | 1 | 65C22
U21, U22 | DIP-20_W7.62mm_Socket_LongPads | 2 | 74HC573
U3 | DIP-40_W15.24mm_Socket_LongPads | 1 | Pico9918A
U4 | DIP-28_W15.24mm_Socket_LongPads | 1 | 65C51
U5 | DIP-16_W7.62mm_Socket_LongPads | 1 | 74HC163
U6 | DIP-40_W15.24mm_Socket_LongPads | 1 | ATmega1284-P
U7 | DIP-28_W15.24mm_Socket_LongPads | 1 | AS6C62256
U8 | DIP_Socket-28_W11.9mm_W12.7mm_W15.24mm_W17.78mm_W18.5mm_3M_228-1277-00-0602J | 1 | AT28C256
U9 | DIP-28_W15.24mm_Socket_LongPads | 1 | 6581
X1 | Oscillator_DIP-14 | 1 | 16MHz
Y1 | Crystal_HC49-U_Vertical | 1 | 1.8432 Mhz

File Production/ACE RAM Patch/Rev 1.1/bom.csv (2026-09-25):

Designator | Footprint | Quantity | Value | LCSC Part #
J1 | DIP-14_W7.62mm_LongPads | 1 | 74HC00 (U12)
J2 | DIP-14_W7.62mm_LongPads | 1 | 74HC00 (U13)
U1 | DIP-14_W7.62mm_LongPads | 1 | 74HC00
U2 | DIP-14_W7.62mm_LongPads | 1 | 74HC02

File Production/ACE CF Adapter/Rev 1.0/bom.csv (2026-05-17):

Designator | Footprint | Quantity | Value | LCSC Part #
D1 | LED_D3.0mm | 1 | ACT
J1 | PinHeader_2x10_P2.54mm_Horizontal | 1 | STORAGE
R1, R2, R3, R4 | R_Axial_DIN0204_L3.6mm_D1.6mm_P5.08mm_Horizontal | 4 | 1k
R5 | R_Axial_DIN0204_L3.6mm_D1.6mm_P5.08mm_Horizontal | 1 | 330

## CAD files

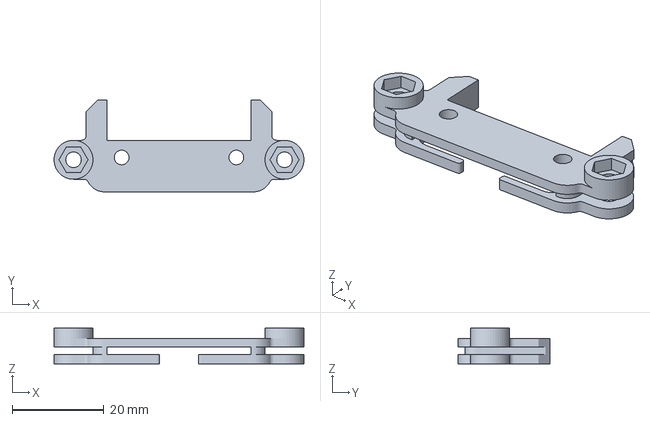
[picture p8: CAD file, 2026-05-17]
CAD/Bases/VGA Adapter.3mf
54.5 x 20.0 x 7.76 mm

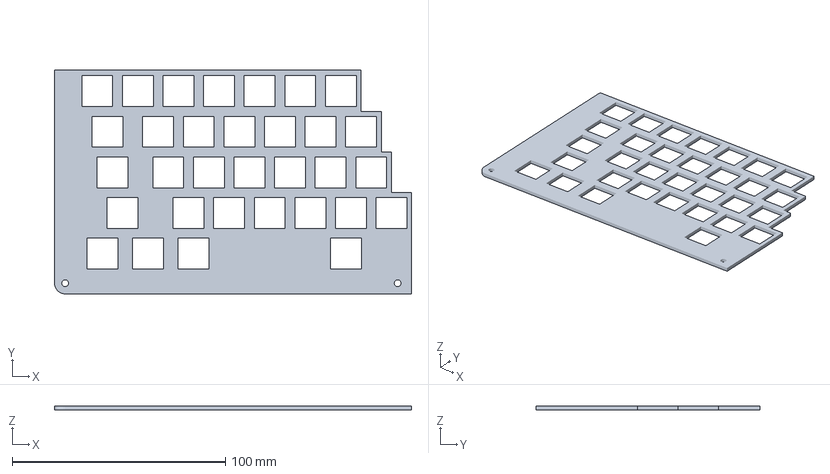
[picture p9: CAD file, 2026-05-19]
CAD/Jigs/Keyboard Helper Jig Left.3mf
167.5 x 105.0 x 2.00 mm

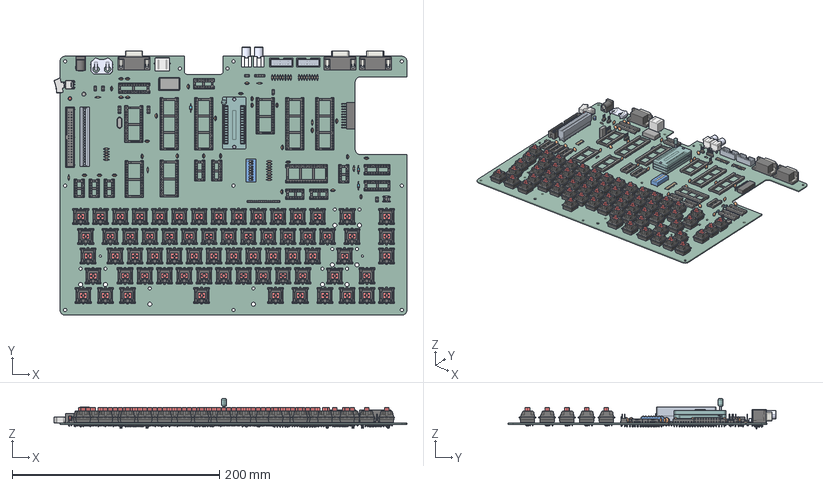
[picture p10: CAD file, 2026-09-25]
CAD/Models/ACE Board/Rev 1.1/ACE Board.step
340.8 x 259.0 x 29.0 mm
C_Disc_D50mm_W25mm_P250mm x 30
DSUB-9_Pins_Horizontal_P2.77x2.84mm_EdgePinOffset7.70mm_Housed_ MountingHolesOffset9.12mm x 3
R_Axial_DIN0204_L36mm_D16mm_P508mm_Horizontal x 35
P:\E-Switch Secure\3D_MODELS_STP_FORMAT\400MSPxR6xxxM6xE.stp
PinHeader_1x02_P254mm_Vertical x 5
SW_PUSH_6mm
DIP_28_W1524mm_Socket x 4
228-1277-00-0602J
PinHeader_1x03_P254mm_Vertical x 2
PinHeader_1x04_P254mm_Vertical
DIP_20_W762mm_Socket x 2
DIP_14_W762mm_Socket x 6
Oscillator_DIP-14
DIP_24_W762mm_Socket
DIP_40_W1524mm_Socket x 4
6120xx21621_PIN x 40
SW_DIP_SPSTx08_Slide_978x225mm_W762mm_P254mm
C-5-5530843-4
PJRAN1X1U04X-edit x 2
Crystal_HC49-U_Vertical
DIP_32_W1524mm_Socket
KMDGX-6S-BS
D_DO-35_SOD27_P7.62mm_Horizontal x 3
PinHeader_1x16_P200mm_Vertical
PinSocket_2x10_P2.54mm_Horizontal
LED_D3.0mm
DIP_16_W762mm_Socket x 3
BarrelJack_Horizontal
CP_Radial_D40mm_P150mm
BAT-HLD-001-THM
ACE Board_PCB

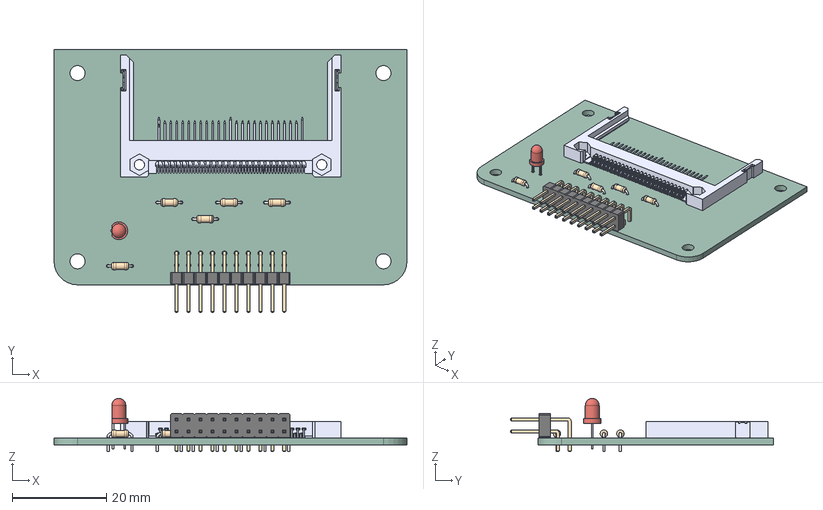
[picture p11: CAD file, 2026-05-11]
CAD/Models/ACE CF Adapter/Rev 1.0/ACE CF Adapter.step
75.0 x 55.9 x 11.3 mm
LED_D3.0mm
101D-TAAB-R01
R_Axial_DIN0204_L3.6mm_D1.6mm_P5.08mm_Horizontal x 5
PinHeader_2x10_P2.54mm_Horizontal
ACE CF Adapter_PCB

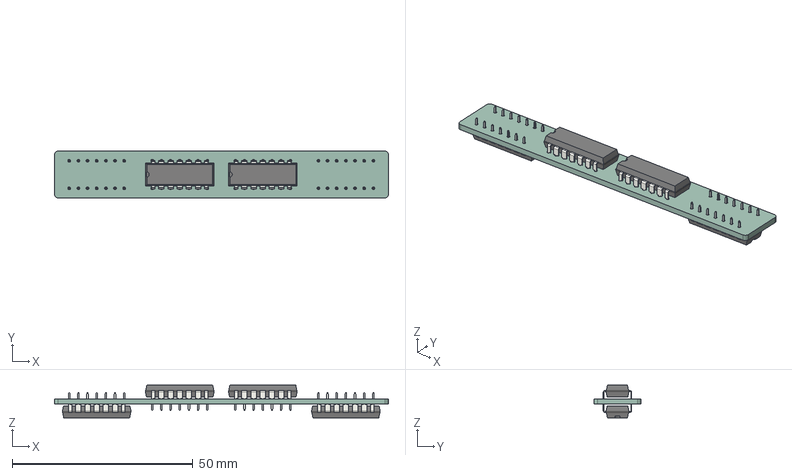
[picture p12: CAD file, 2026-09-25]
CAD/Models/ACE RAM Patch/Rev 1.1/ACE RAM Patch.step
92.5 x 13.0 x 9.04 mm
DIP-14_W7.62mm x 4
ACE RAM Patch_PCB

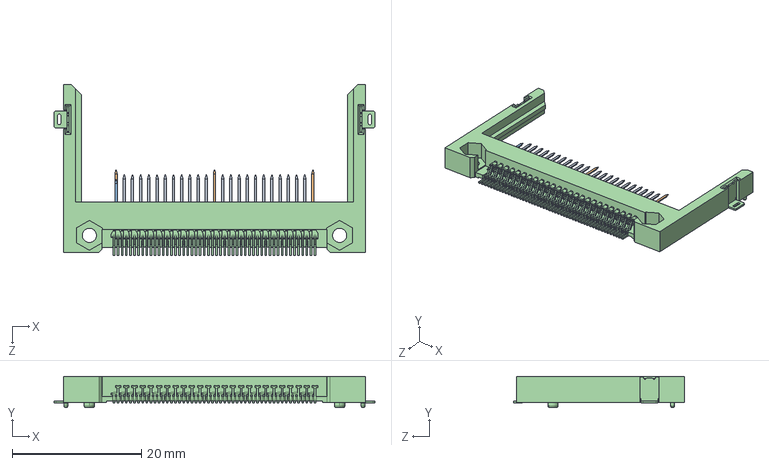
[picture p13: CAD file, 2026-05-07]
Models/101D-TAAB-R01.step
49.7 x 4.80 x 26.5 mm

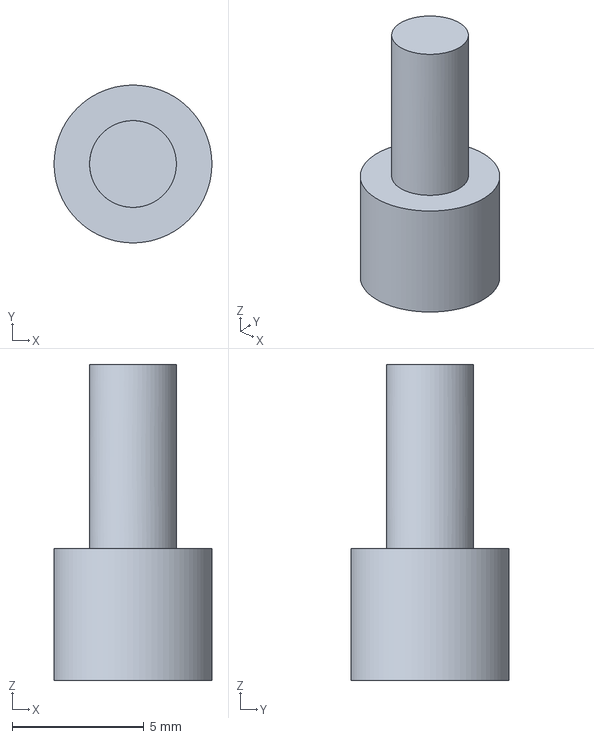
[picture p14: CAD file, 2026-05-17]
CAD/Bases/Reset Button.3mf
6.00 x 6.00 x 12.0 mm

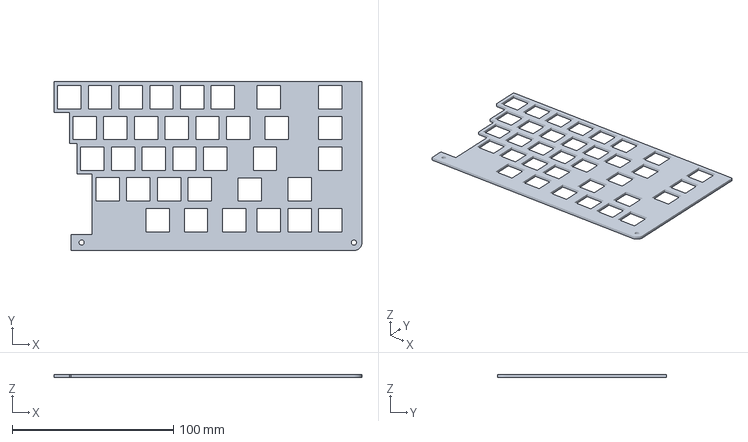
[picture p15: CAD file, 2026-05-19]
CAD/Jigs/Keyboard Helper Jig Right.3mf
191.1 x 105.0 x 2.00 mm

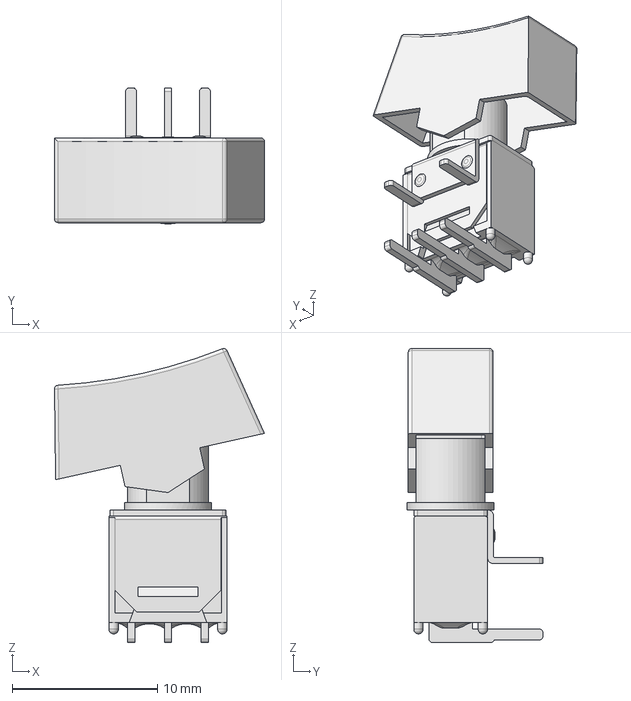
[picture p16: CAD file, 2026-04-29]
Models/400MSP1R6BLKM6QE.step
14.5 x 9.35 x 20.2 mm

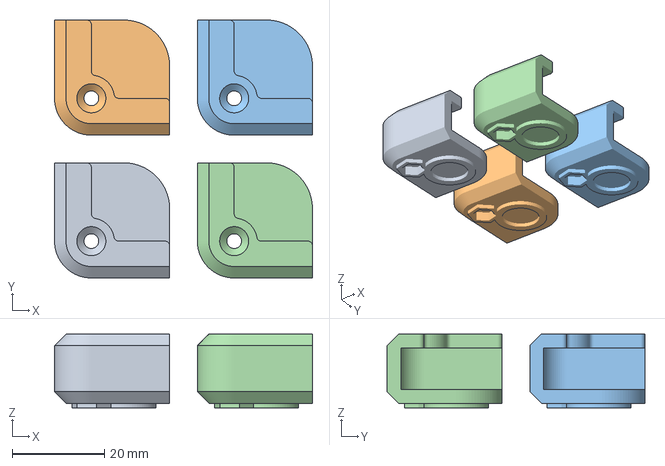
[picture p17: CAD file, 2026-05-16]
CAD/Bases/Corner.3mf
56.0 x 56.0 x 16.0 mm

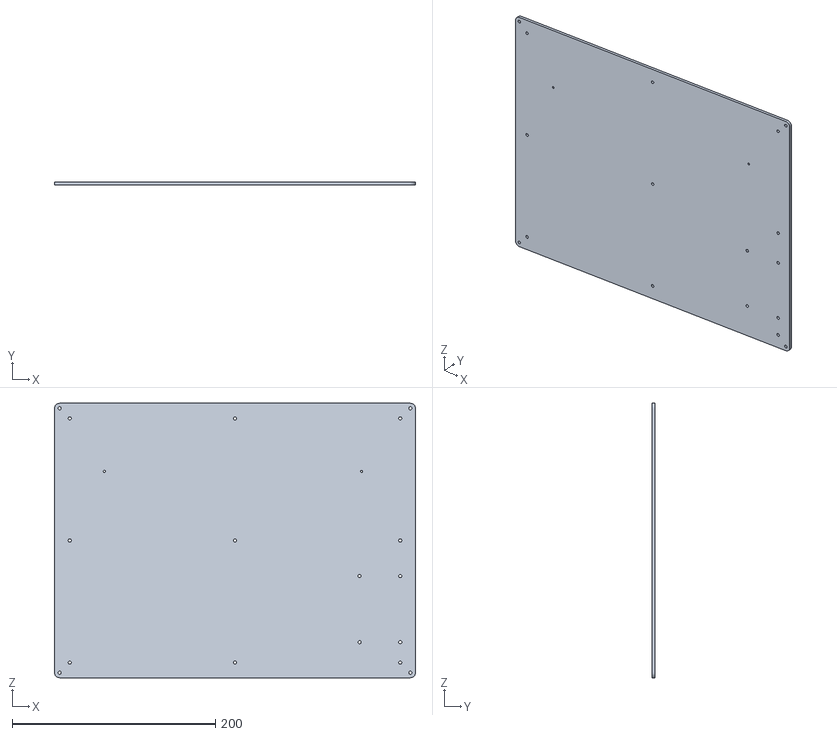
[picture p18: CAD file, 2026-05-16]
CAD/Bases/Plate.stl
355.0 x 3.00 x 270.0

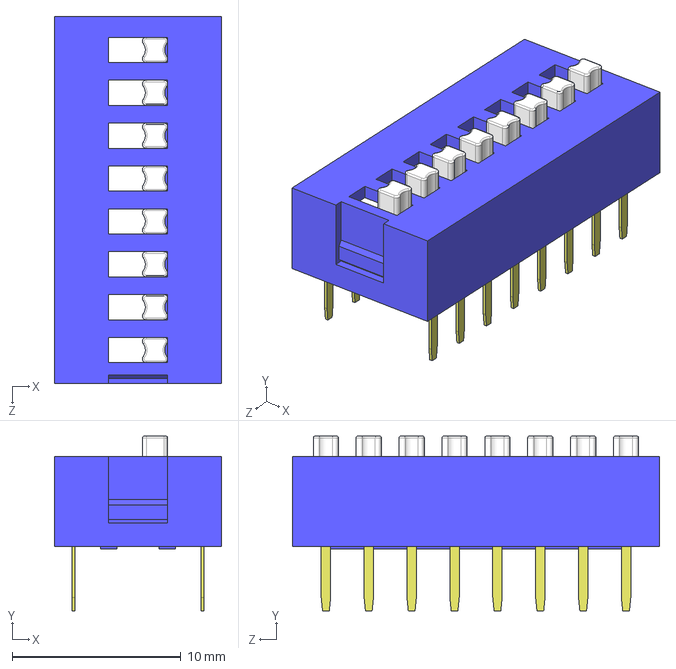
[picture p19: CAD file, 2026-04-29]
Models/DS01C-254-L-08BE.step
9.90 x 10.4 x 21.7 mm

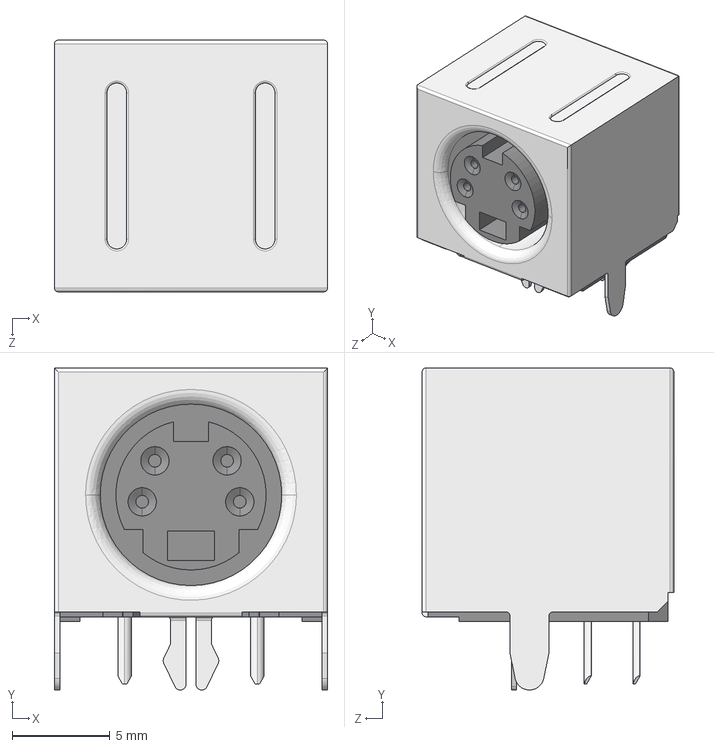
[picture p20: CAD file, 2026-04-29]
Models/KMDGX-6S-BS.step
14.0 x 16.5 x 12.9 mm

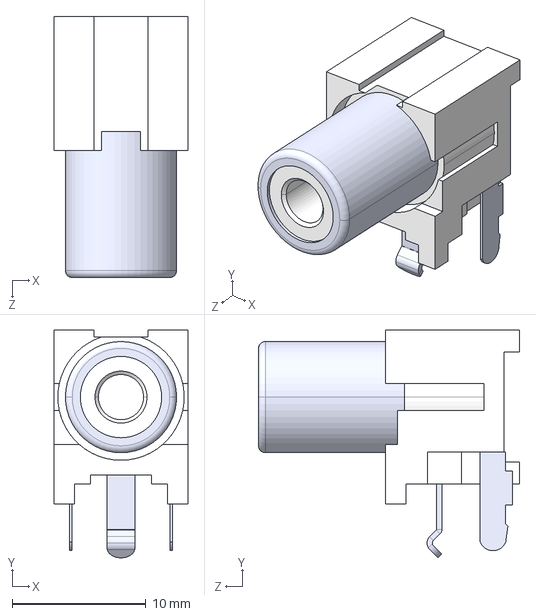
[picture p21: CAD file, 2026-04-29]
Models/PJRAN1X1U0XX.step
10.0 x 17.0 x 19.5 mm

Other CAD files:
Models/CherryMX.step
Models/228-1277-00-0602J.step
Models/5-5530843-4.step
Models/BAT-HLD-001-THM.step
CAD/Bases/Corner.stl
CAD/Bases/Reset Button.stl
CAD/Bases/VGA Adapter.stl
CAD/Jigs/Keyboard Helper Jig Left.stl
CAD/Jigs/Keyboard Helper Jig Right.stl
CAD/Models/ACE Board/Rev 1.0/ACE Board.step
CAD/Models/ACE RAM Patch/Rev 1.0/ACE RAM Patch.step
Models/0702461201.step
Models/61204021621.step

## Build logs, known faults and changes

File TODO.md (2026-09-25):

# TODO

## Rev 1.1: shared lines that a push-pull output can hold high

The 65C02's `IRQB`, `NMIB` and `RESB` lines are each shared by several devices,
and each device may only pull its line low. A device that also drives its line
high fights every other device on that line. When one of the others pulls low,
the line settles at a voltage the 65C02 still reads as high, so the signal never
arrives.

### 1. Pico9918 `/INT` to `IRQB`: add a diode (required)

**In the Rev 1.1 schematic, 2026-09-24:** D1, a BAT85, from U3 pin 16 to
`IRQB`, cathode on U3. `Tests/check-schematics.mjs` fails if `/INT` ever
reaches `IRQB` another way. On the Rev 1.1 PCB too, beside U3 (2026-09-24).

**Change:** fit a Schottky diode (BAT85) between U3 pin 16 (`/INT`) and the
`IRQB` net, with the cathode toward U3 and the anode on `IRQB`.

**Why:** the Pico9918 drives `/INT` push-pull at 5 V, both high and low. On the
v1.3 and the PRO v2.0, the RP2040/RP2350's GPIO 22 feeds a 74AHC126 buffer (U9 on
the card), and the buffer's output enable is tied to the card's `RST` input. The
buffer therefore drives `/INT` whenever the 6502 is out of reset, and no firmware
can make it open-drain. The stock firmware and PICOVDP both hold `/INT` high when
no interrupt is pending.

The VIA (U2, W65C22N), the ACIA (U4, R6551) and the clock (U18, DS1511Y) all pull
`IRQB` low with open-drain outputs, so each one fights the Pico9918's buffer.
With a pico9918 PRO fitted, `IRQB` measured 3.8 V while the VIA was asserting.
That is above the W65C02S's input-high threshold of 0.7 × VDD (about 3.5 V), so
the 65C02 never took the interrupt and the VIA's flag was never cleared. The
keyboard and serial input were both dead, even with video disabled by the DIP
switch. A pico9918 v1.3 has the same circuit and happened to work, so the v1.3
was only ever working by luck.

**Tested:** on Rev 1.0, 2026-09-24. A socket stack under the PRO with pin 16
routed through a BAT85 fixed the keyboard and serial input on BIOS 1.6 and
BIOS 2.0.

**What the diode costs:** the Pico9918 can still pull `IRQB` low, to about
0.4 V through the diode, which is well below the 65C02's input-low threshold.
Neither BIOS 1.x nor BIOS 2.x uses the VDP's interrupt: BIOS 1.x leaves it
disabled, and BIOS 2.x's `WaitVBlank` polls the status register instead. A
program that does enable VDP interrupts would also need an IRQ handler that
reads the VDP's status register, because the Kernal's `Irq` does not.

### 2. ATmega `RESB` output: add a pull-up, and drive PC7 open-drain (decided)

**In the Rev 1.1 schematic, 2026-09-24:** R5, 10 k from `RESB` to VCC,
beside R1–R4. `Tests/check-schematics.mjs` fails if `RESB` loses its pull-up.
On the Rev 1.1 PCB too (2026-09-24).

**Board change:** add a 10 k pull-up from the `RESB` net to 5 V. No diode.
Rev 1.1 gets it on the board; the Rev 1.0 on the bench gets it as a bodge on
the underside.

**Firmware change (done 2026-09-24, `assertRESB` and `releaseRESB` in
`Firmware/AB Controller/src/main.cpp`):** in the AB Controller, drive PC7
(U6 pin 29) open-drain.
To assert reset, make PC7 an output and write it low. To release reset, make
PC7 an input with its internal pull-up on (`INPUT_PULLUP`). Nothing in the
firmware may write PC7 high while it is an output. This applies to power-on
(`setup()`) and to the reset button (`loop()`).

The internal pull-up (20–50 k) raises `RESB` on its own, so the new firmware
also works on a Rev 1.0 board without the bodge, and the firmware and the
resistor can go in in either order. The external 10 k is a stiffer pull-up than
the internal one, which is worth having on a reset line that runs out to the
`CART` and `BUS` connectors. It is recommended on Rev 1.1 and optional as a
bodge on Rev 1.0. (The ATmega is never programmed in circuit on this board.
During its own start-up, before `setup()` runs, `RESB` has no pull-up unless
the 10 k is fitted, but `setup()` then holds `RESB` low for 250 ms, so the 6502
still gets a clean reset either way.)

**Why:** today the firmware drives `RESB` push-pull. It sets PC7 as an output,
writes it low to hold the 6502 in reset, and writes it high to release it. The
DS1511Y's `RST` output (U18 pin 4) is open-drain on the same net, as is
anything on the `CART` and `BUS` connectors (J18 and J19 on Rev 1.0, J17 and
J18 on Rev 1.1) that pulls reset. While
the ATmega holds `RESB` high, none of them can reset the machine. The DS1511Y
asserts `RST` on a power failure and when its watchdog times out.

**Why the pull-up:** `RESB` has no pull-up today; the ATmega is the only thing
holding it high. Once PC7 only ever pulls low, something else has to raise the
line: the ATmega's internal pull-up, and on Rev 1.1 the 10 k as well.

**Why not a diode:** a diode on PC7 would also work, but the firmware change
does the same job with one part fewer.

### 3. ATmega `NMIB` output: firmware only, no board change

**Done 2026-09-24.** `NMIB` already has a pull-up (R2). In the default firmware
build, PD7 is left as an input and never drives `NMIB`. With `ENABLE_SQW`
defined, the firmware used to make PD7 an output and hold it high between
jiffy-clock pulses, which would stop a cartridge or bus card from ever raising
an NMI. The pulse is now open-drain: the jiffy ISR switches PD7 to an output
driven low to assert, and back to an input to release. PD7's output latch stays
low throughout.

The default build is byte-for-byte unchanged by this fix, so a board flashed
with the RESB change needs no reflash. The `ENABLE_SQW` build compiles, and its
disassembly shows the pulse as `sbi`/`cbi` on DDRD bit 7 with no write to PORTD,
but the jiffy clock has not been run on hardware.

### 4. Cards on the `CART` and `BUS` connectors

`CART` and `BUS` (J18 and J19 on Rev 1.0, J17 and J18 on Rev 1.1) carry
`IRQB`, `NMIB` and `RESB`. Anything plugged into them must
only pull those lines low. In particular, a video card built around a pico9918
has the same `/INT` problem as U3, and needs the same diode on the card.

## The ACE runs at 1 MHz only (decided 2026-09-24)

At 2 MHz, 6502-PICOVDP's Phase 14 found the SID and the CompactFlash card
missing on some boots, and serial input under BIOS 1.6 replaying old lines
(`docs/results/phase-14.md` in that repository, "Found on the way"). The first
two are explained below. The third is not, and a fault that cannot be found
cannot be patched on the Rev 1.0 boards, so the ACE runs at 1 MHz only.

- **Rev 1.1:** Rev 1.0's J1 (PHI2 SELECT) is gone from the schematic, and U5's 1 MHz
  output (Q3, pin 11) drives PHI2 for the 65C02, VIA, ACIA, SID and the
  `CART` and `BUS` connectors. Q2 is unconnected. `Tests/check-schematics.mjs`
  fails if any of the four chips is clocked from anything else.
- **Rev 1.0:** J1 stays on its 1 MHz pins, 1 and 2.

### 5. The SID at 2 MHz (explained)

The SID's clock (U9 pin 6) was always U5's 1 MHz output, not the jumper, and
its chip select (IO7B) is decoded from the address alone. At 2 MHz the SID's
clock is high for all of one CPU cycle and low for all of the next, so only
every other CPU cycle can reach it: a write in the other cycle is lost, and a
read there returns whatever the bus last held. The Kernal's `ProbeSID` makes its
three setup writes and its read of `SID_OSC3` 1,285 cycles apart, an odd number,
so at 2 MHz either the writes or the read miss. Which one depends on where reset
lands against the 1 MHz clock, which changes from boot to boot. A boot that
"found" the SID found it by accident: the read missed and returned `$98`, the
high byte of `SID_OSC3`'s address still on the bus, which is neither `$00` nor
`$FF`. Reproduced with the emulator's CPU and this clocking added to it: BIOS
1.6 and 2.0.2 both boot with `HW_PRESENT` `$FF` on one parity and `$BF` on the
other. It was never only the probe: at 2 MHz half of every program's SID
accesses miss.

**Still open:** at 1 MHz the SID (an ARMSID) was missed once in about a dozen
boots. The 2 MHz fault does not explain that.

### 6. The CompactFlash card at 2 MHz (explained)

`StWaitReadyPoll` waits for the card to leave `BSY` with a loop counted in CPU
cycles: about 851 ms after reset at 1 MHz and 425 ms at 2 MHz, the same in BIOS
1.6 and 2.0.2. The card's `/RESET` is `RESB`, so it starts initialising at the
same moment the 65C02 does. A card that needs between 425 and 851 ms is found at
1 MHz and missed at 2 MHz. The bus timing itself is within PIO mode 0 at both
speeds.

**At 1 MHz:** every boot in Phase 14 found the card, but the loop is still
counted in cycles, and on the boots missed at 2 MHz the card needed more than
425 ms, so the margin at 1 MHz is not known. A slower card could still be
missed. The BIOS fix, a probe that waits a fixed time, is written up in
6502-BIOS `TODO.md` item 1 for the next BIOS update. So is a fault in the SID
probe that item 5 turned up: an empty SID socket reads as a SID (item 2 there).

### 7. Serial input replayed old lines under BIOS 1.6 at 2 MHz (not explained, dropped)

After an XMODEM `LOAD`, or after a program had run, BASIC ran again lines typed
seconds or minutes before. The replayed bytes were the oldest in the input ring,
the ones just ahead of the write pointer, so a pointer jumped forward. The boot
text sent over serial was also garbled at 2 MHz. What was ruled out:

- **A race in BIOS 1.6's serial code:** `Irq`, `ReadBuffer`, `WriteBuffer`,
  `ScRts`, `ScRxPoll` and `SerialChrout` are the same in 1.6 and 2.0.2, and both
  keep the ring's pointers at `$00` and `$01`.
- **The ACIA holding the data bus after a read:** the nearest read of a pointer
  after any `lda SC_DATA` is at least 12 cycles later, and the cycles between are
  instruction fetches, which would crash the machine first.
- **The board's timing:** RAM `/OE` and `/WE` are qualified by PHI2, and every
  setup and hold time on the bus is measured from a PHI2 edge, so none of them
  change with the clock rate.
- **The test programs:** `bus.asm`, `probe.asm` and `graphics-1.asm` do not
  touch `$00` or `$01`.

Two things were left: the R6551AP runs at exactly its 500 ns minimum cycle time
at 2 MHz, and reseating it stopped the replays for a while. The runs also were
not matched (`graphics-1.asm` ran only under 1.6, and 1.6 at 1 MHz got 64
bus-test passes against 500 elsewhere), so "only under 1.6" is weaker evidence
than it looks. None of this matters at 1 MHz.

### 8. The emulator's 2 MHz setting (done)

6502-EMULATOR 3.5.0, released 2026-09-24, runs at 1 MHz only: the toolbar
button and the saved setting are gone, and `--freq 2` is refused. 6502-DOCS
pins 3.5.0 and no longer offers 2 MHz, in either edition (its ACCURACY A77).

## The bank register's address decode (third revision, 2026-09-24)

**The fault:** in Rev 1.0, in Rev 1.1 as drawn, and with the first ACE RAM Patch
fitted, U12B combined `/(A9·A8)` from U12A and `/(A0–A7)` from U17 with a NAND.
A NAND of two active-low signals is the OR of the two conditions, so each bank
latch loaded on 259 addresses instead of one: every write to `$8300`–`$83FF`,
`$80FF`, `$81FF` and `$82FF` for the low latch, and the same in the `$8400`
window for the high one. A write to the top 255 bytes of a bank's window
changed the bank. The BIOS's RAM probe uses offset 0, so it never noticed. The
first patch fixed a different fault in the same path (the latches pulsed
whenever the bus was idle) and took U12B's output as given.

**Rev 1.1 (done in the schematic):** the same eight gates as the patch, on two
chips, U12 (74HC00) and U13 (74HC02). Rev 1.0's second 74HC00 is gone; the
re-annotation gave its designator to the 74HC02, which was U23 until then. U13C
NORs U12A's `/(A9·A8)` with U17's output to select the bank register. U13D makes
IO1 from IO1B, so that inverter no longer needs a NAND, and U12D makes B18. U12B
and U12C combine the select with IO1 and B18, and U13A and U13B NOR those with WB.
Every gate of both chips is in use. The removed 74HC00 had no decoupling capacitor
of its own on the PCB (C28, C27 before the re-annotation, sits by the 74HC02), so
none goes with it.

**ACE RAM Patch Rev 1.1 (done):** a correct latch needs A8, A9 and U17's
output, and none of them reach U13's footprint. The new patch therefore connects
to both, J1 to U12's holes and J2 to U13's, and replaces both 74HC00s with the
same logic as the Rev 1.1 board (a 74HC00 and a 74HC02). It mounts underneath
the ACE, front side up, on pin headers soldered into U12's and U13's holes once
their chips and sockets are off; U1 and U2 are on its back, hanging below. On the
Rev 1.0 board U13's pin 1 is 23.00 mm from U12's along the row, and on the patch
all 28 header pins land on U12's and U13's pads to 0.0000 mm.

**The check:** `Tests/check-schematics.mjs` evaluates both boards' decode from
their netlists, in all 524,288 bus states, against the memory map (README,
"Checking the schematics"). It fails on the Rev 1.0 board alone, on Rev 1.0
with the first patch, and on Rev 1.1 as it was, and passes on both boards now.

**Still to do:**

- ~~Lay out the patch's PCB.~~ Done 2026-09-24: U1, J1, J2 and U2 in one row,
  92.6 × 13.1 mm, routed, with no DRC errors, nothing unconnected and no
  schematic parity issues. `Production/ACE RAM Patch/Rev 1.1` is generated.
- Order the patch.
- ~~Update the Rev 1.1 PCB from the schematic.~~ Done 2026-09-24. The PCB took
  the re-annotation with every placed part where it was, lost the PHI2 SELECT
  jumper and the second 74HC00, and gained D1 and R5; the 74HC02 (U13) sits
  where that 74HC00 was, beside U12. DRC with schematic parity reports no errors
  and nothing unconnected. `Production/ACE Board/Rev 1.1` is regenerated, and its
  gerbers and drill files match the PCB shape for shape.
- On the bench board: remove the hand bodge, take U12 and U13 off (chips and
  sockets), and solder the new patch underneath on pin headers.
- Then check the high window. Phase 14's boots read `HW_PRESENT` as `$FD` even at
  1 MHz, which means the Kernal's probe did not find the `$8400` window (bit 1).
  With the new patch fitted and SW70 switch 2 on, a boot should read `$FF`.

## README: the video card and BIOS 2.0

The README still describes a Pico9918 running TMS9918A firmware and BIOS 1.x.
Everything it needs is now proven (6502-PICOVDP `docs/results/phase-14.md`,
"For 6502-ACE"):

- **Software table:** add [6502-PICOVDP](https://github.com/acwright/6502-PICOVDP),
  "Firmware for the ACE's video card, on a PICO9918 PRO v2.0". The BIOS is the
  Kernal, BASIC and Wozmon; BIOS 2.x has no Monitor.
- **Specs line and BOM U3:** PICO9918 PRO v2.0 (RP2354A) running 6502-PICOVDP,
  with one 0.1″ header pin soldered into its `MDE1` pad; RP2040 PICO9918 boards
  (v1.x) cannot run it. The silkscreen and `Production/…/bom.csv` still read
  `Pico9918A`, and stay that way until a new revision.
- **A Firmware section, video card first:**
  - Flash the PRO with `picovdp-v1.0.0.uf2` from
    https://github.com/acwright/6502-PICOVDP/releases/tag/v1.0.0 (SHA-256
    `0b74cd9875cbffc46de7ec48a9bb6e0d4a76a3e796d2563615e17e6bed94afd5`): hold BOOT,
    connect USB-C, `picotool load -v -x -f picovdp-v1.0.0.uf2`. The release
    build has no USB of its own, so every update needs BOOT again. It may be
    flashed in the ACE's socket with the ACE switched off; that is how the
    tested card was flashed.
  - Optionally, back up the stock firmware first, from BOOTSEL:
    `picotool save -a stock.bin`. To restore it, `picotool load -v -x stock.bin`.
    The backup was made; the restore is picotool's ordinary load and has not
    been tried on a PRO.
  - Burn BIOS 2.0 to U8. The ACE tested ran `v2.0.2` (SHA-256 `7a71252d…`).
  - The first boot shows the AC6502 logo, then `AC6502 BIOS v2.0`,
    `BASIC v2.0 30718 BYTES FREE` and `RAM RTC CF SER VIA SID VDP`, at
    power-on and after the reset button (SW17). `VDP` missing from that line
    means the card isn't running 6502-PICOVDP.
  - The builder's check for the `MDE1` pin, from BASIC 2.0:
    `POKE 39939,4:POKE 39939,142:PRINT PEEK(39939):POKE 39939,0:POKE 39939,142`
    prints 172.
- **The /INT diode** (item 1 above) belongs in the assembly notes as well.

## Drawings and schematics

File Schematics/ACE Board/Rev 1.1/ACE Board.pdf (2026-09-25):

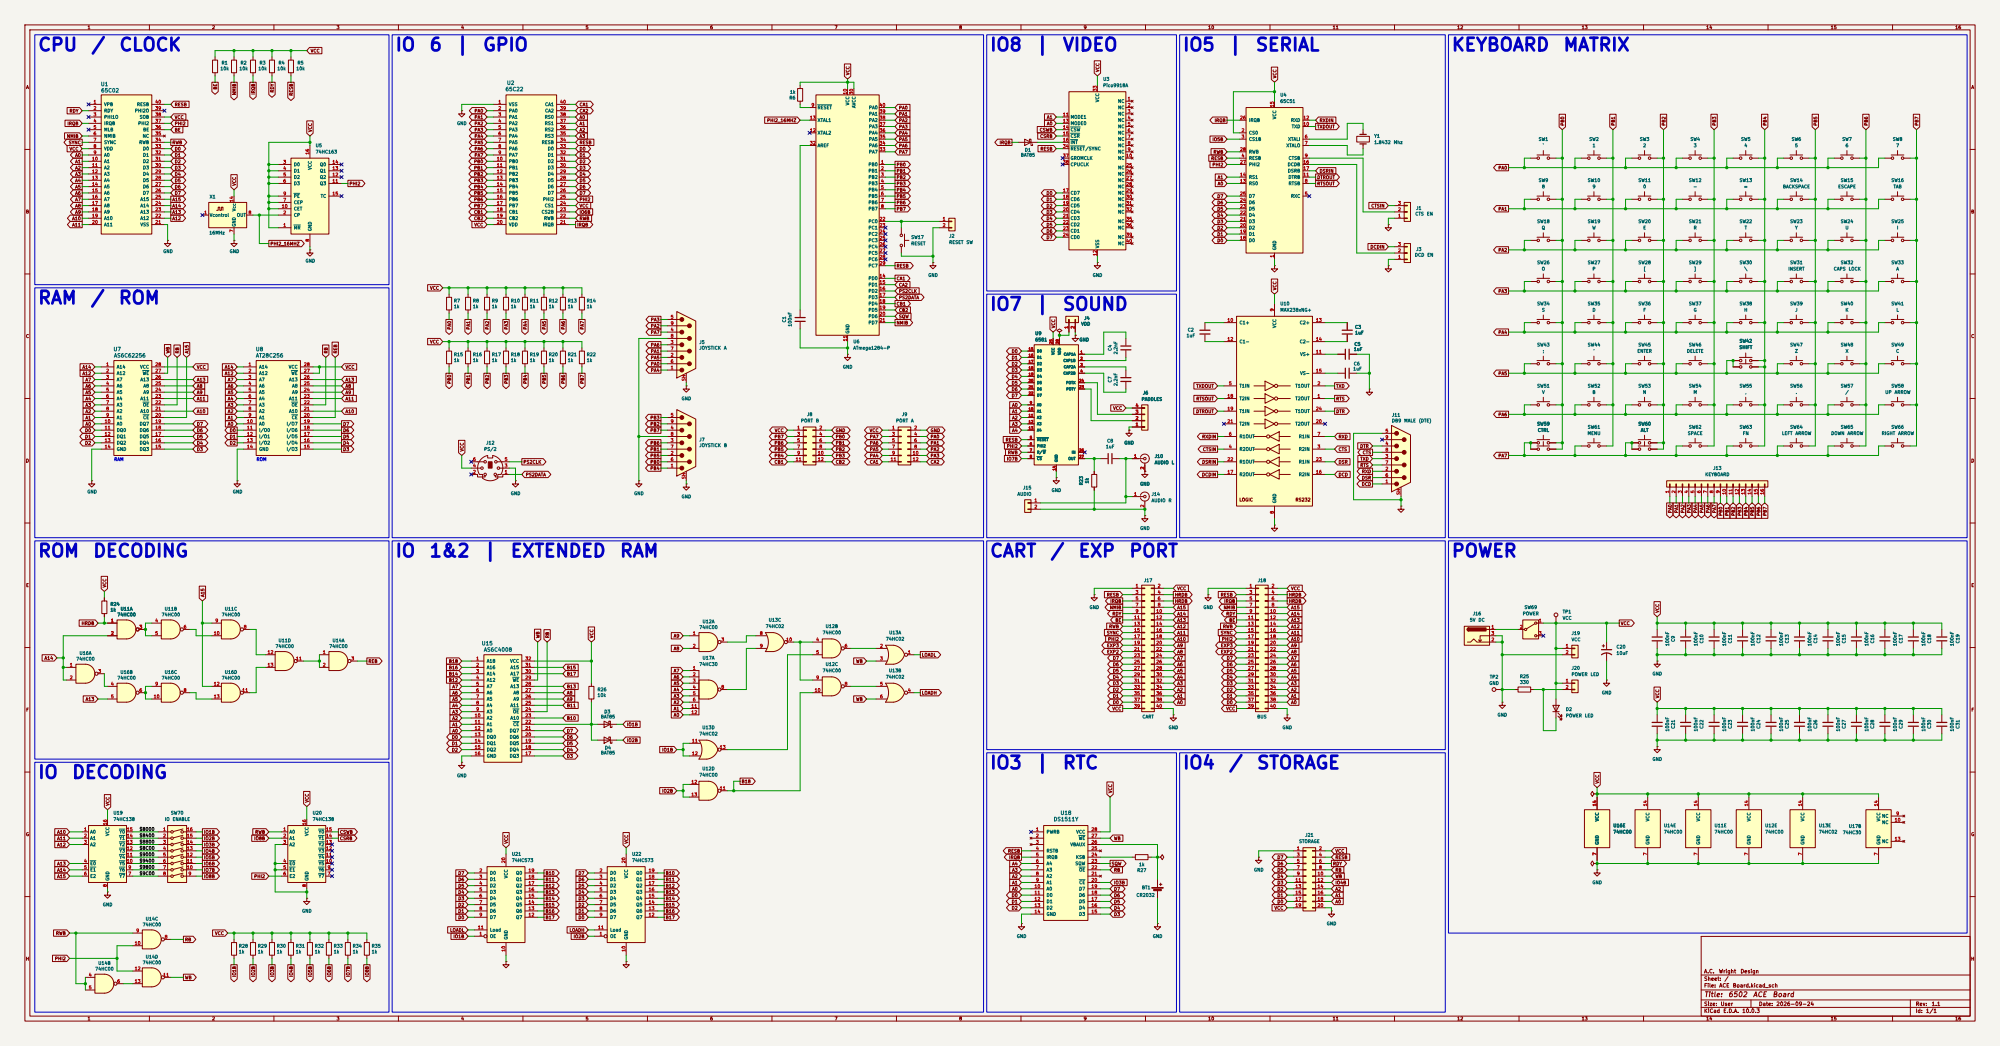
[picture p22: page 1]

Size: User | Rev: 1.1
KiCad E.D.A. 10.0.3 | Id: 1/1

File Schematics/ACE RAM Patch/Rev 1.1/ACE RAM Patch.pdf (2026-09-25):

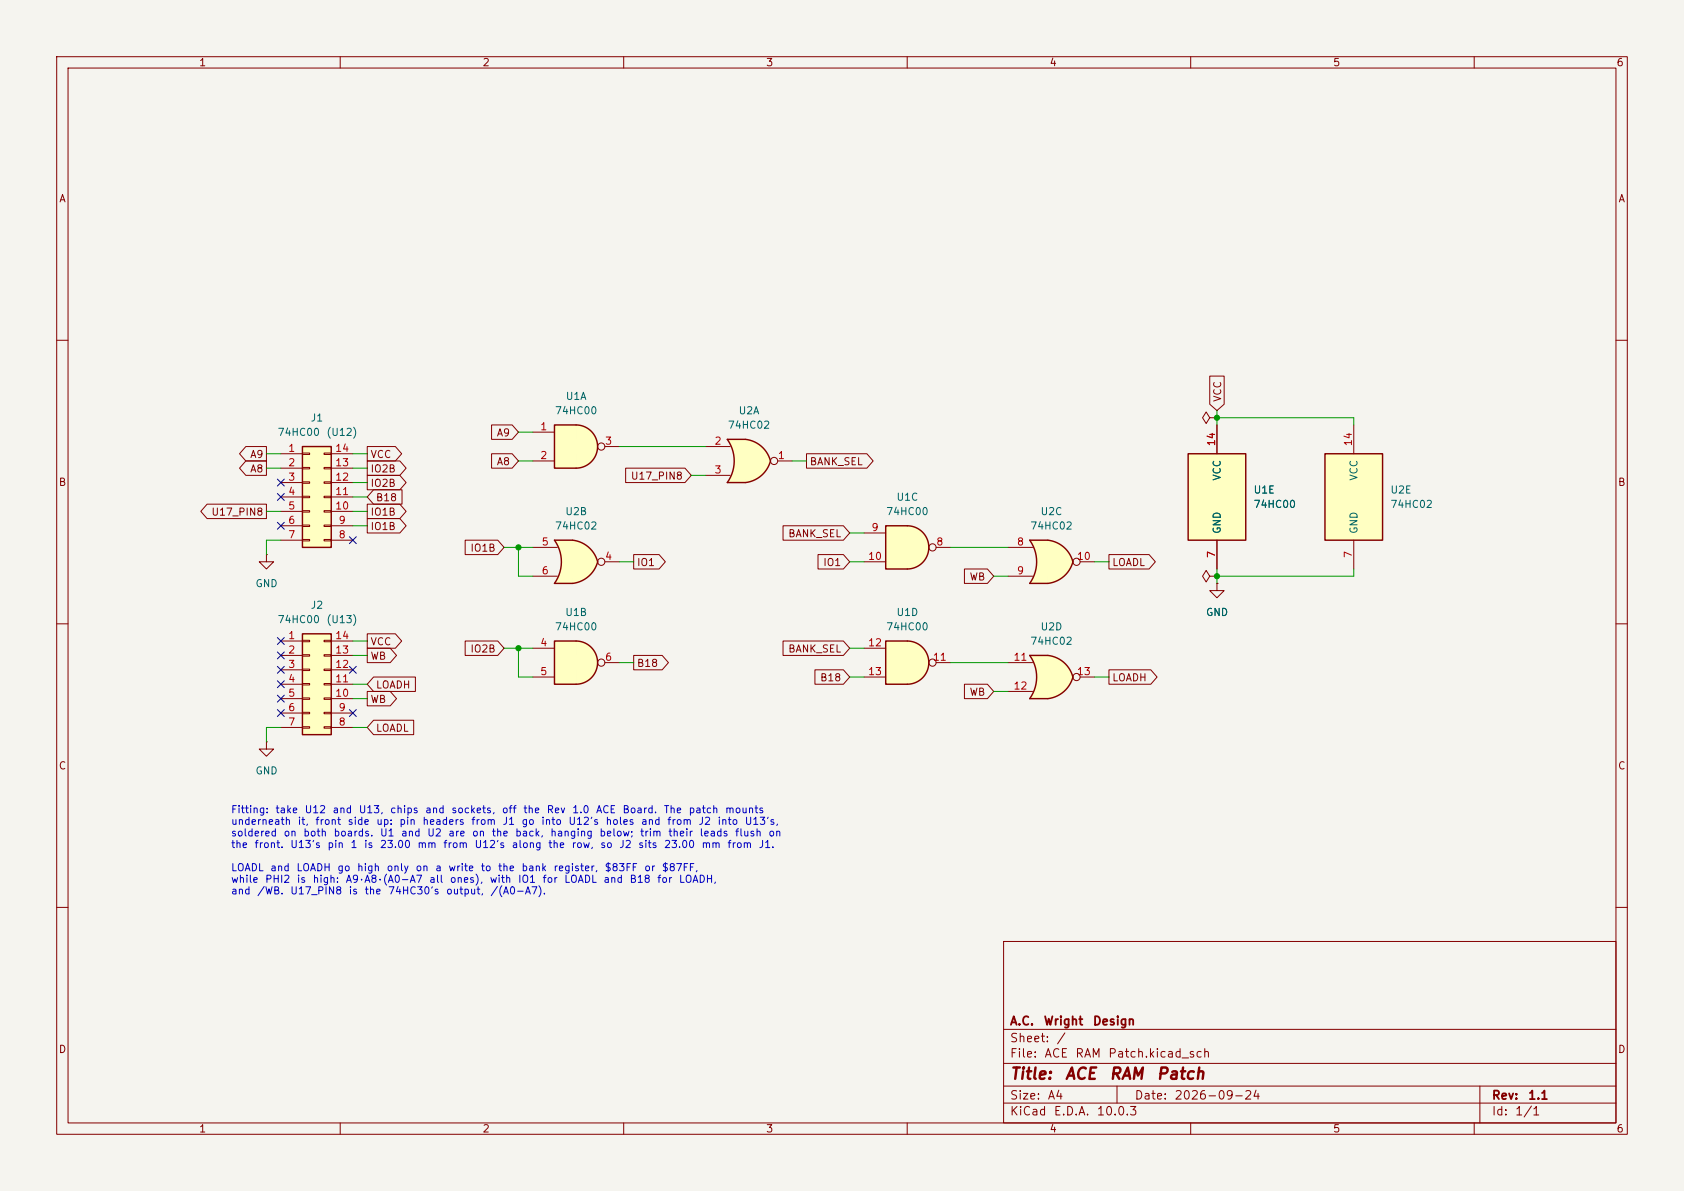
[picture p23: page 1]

Fitting: take U12 and U13, chips and sockets, off the Rev 1.0 ACE Board. The patch mounts underneath it, front side up: pin headers from J1 go into U12's holes and from J2 into U13's, soldered on both boards. U1 and U2 are on the back, hanging below; trim their leads flush on

A.C. Wright Design
Sheet: /
File: ACE RAM Patch.kicad_sch
Title: ACE RAM Patch

Size: A4 | Rev: 1.1
KiCad E.D.A. 10.0.3 | Id: 1/1

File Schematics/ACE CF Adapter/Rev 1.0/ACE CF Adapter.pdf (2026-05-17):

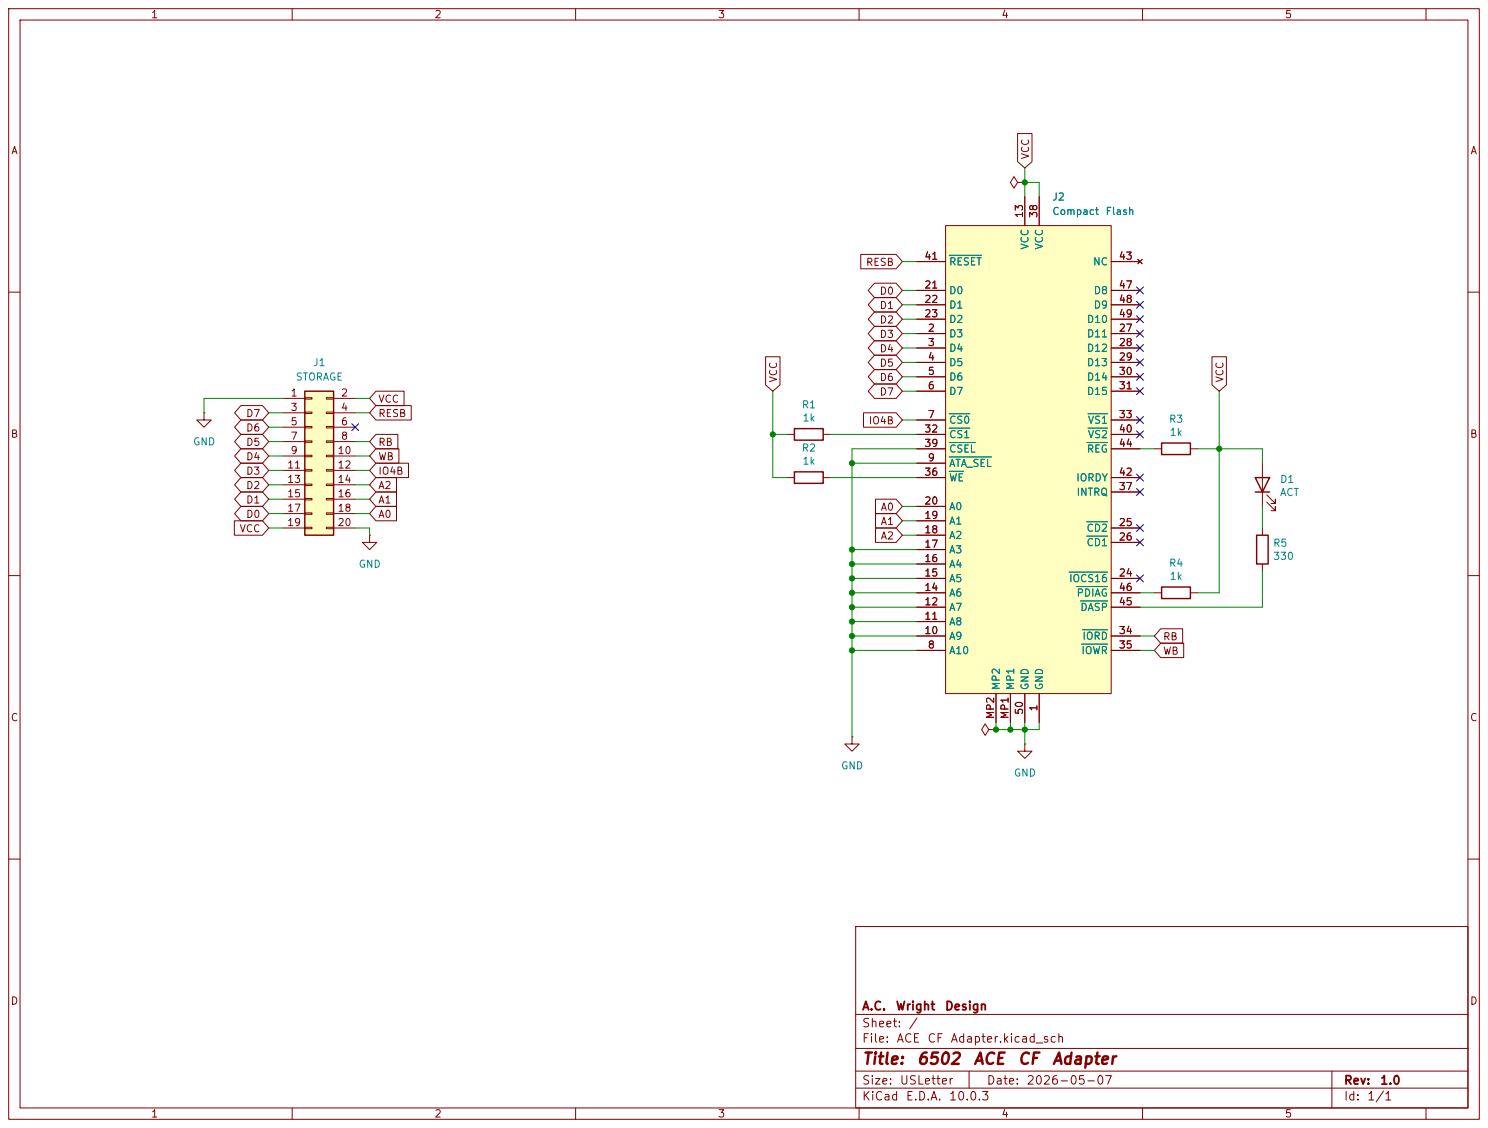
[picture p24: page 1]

A.C. Wright Design
Sheet: /
File: ACE CF Adapter.kicad_sch
Title: 6502 ACE CF Adapter

Size: USLetter | Rev: 1.0
KiCad E.D.A. 10.0.3 | Id: 1/1

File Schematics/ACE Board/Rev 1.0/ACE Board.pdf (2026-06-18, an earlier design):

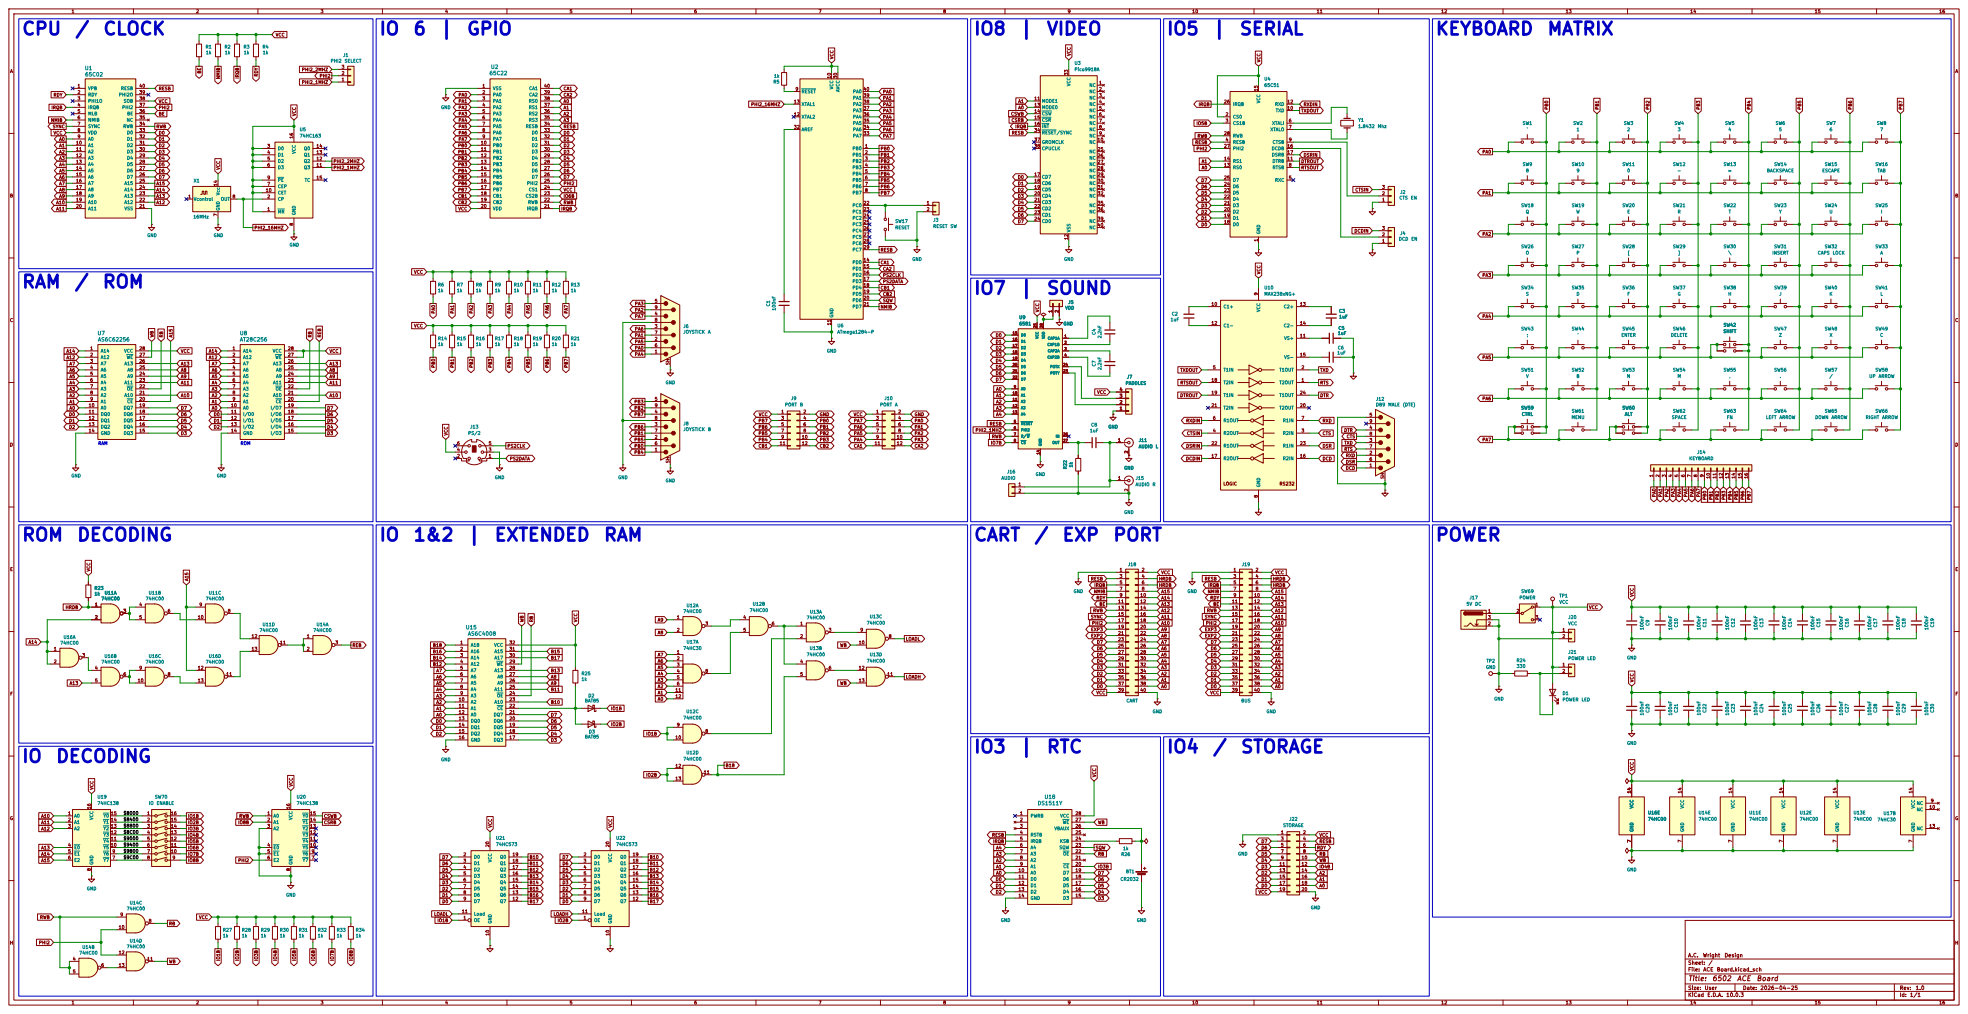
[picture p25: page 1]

Size: User | Rev: 1.0
KiCad E.D.A. 10.0.3 | Id: 1/1

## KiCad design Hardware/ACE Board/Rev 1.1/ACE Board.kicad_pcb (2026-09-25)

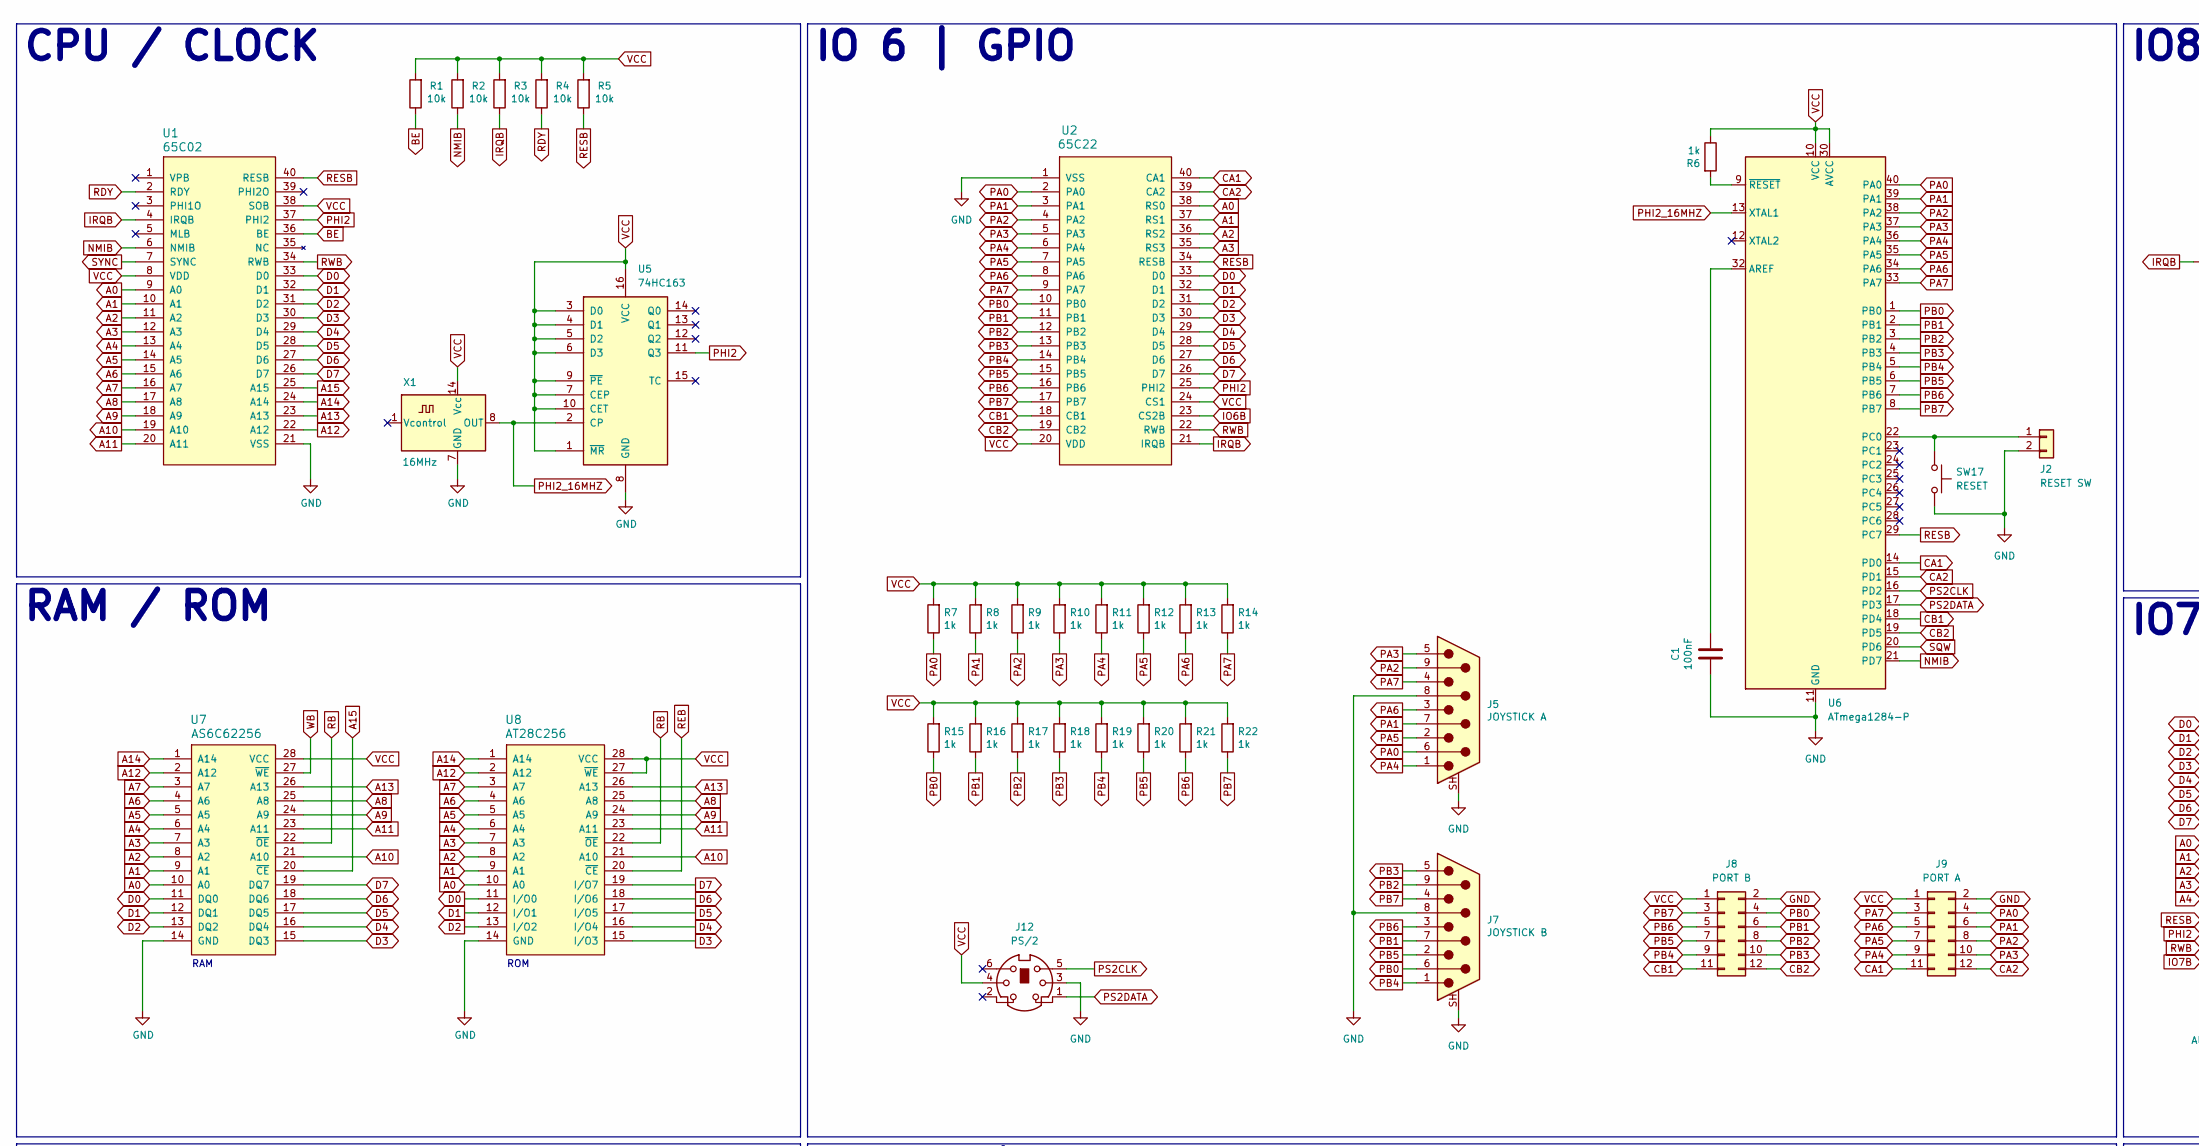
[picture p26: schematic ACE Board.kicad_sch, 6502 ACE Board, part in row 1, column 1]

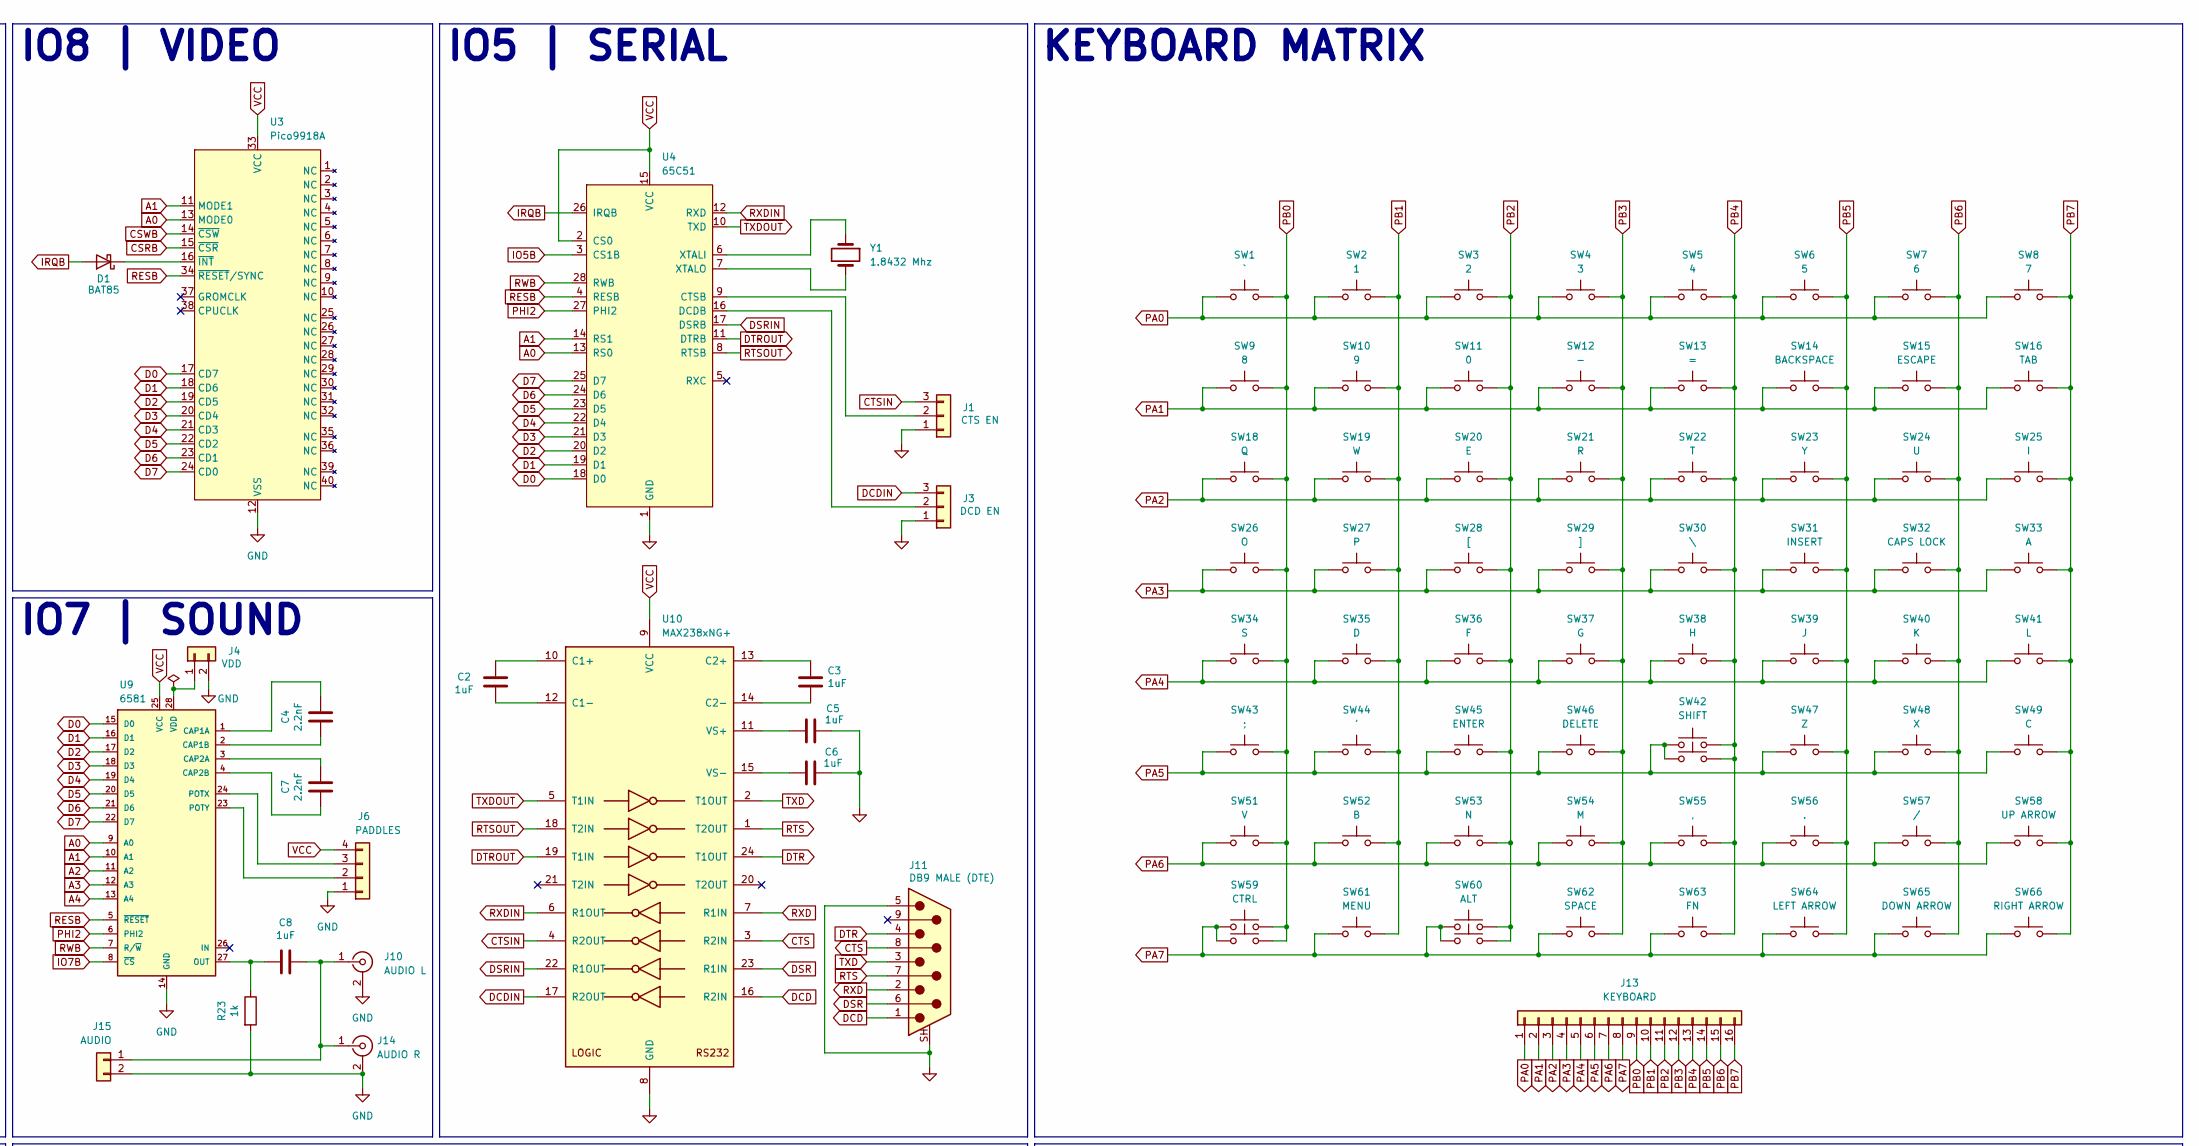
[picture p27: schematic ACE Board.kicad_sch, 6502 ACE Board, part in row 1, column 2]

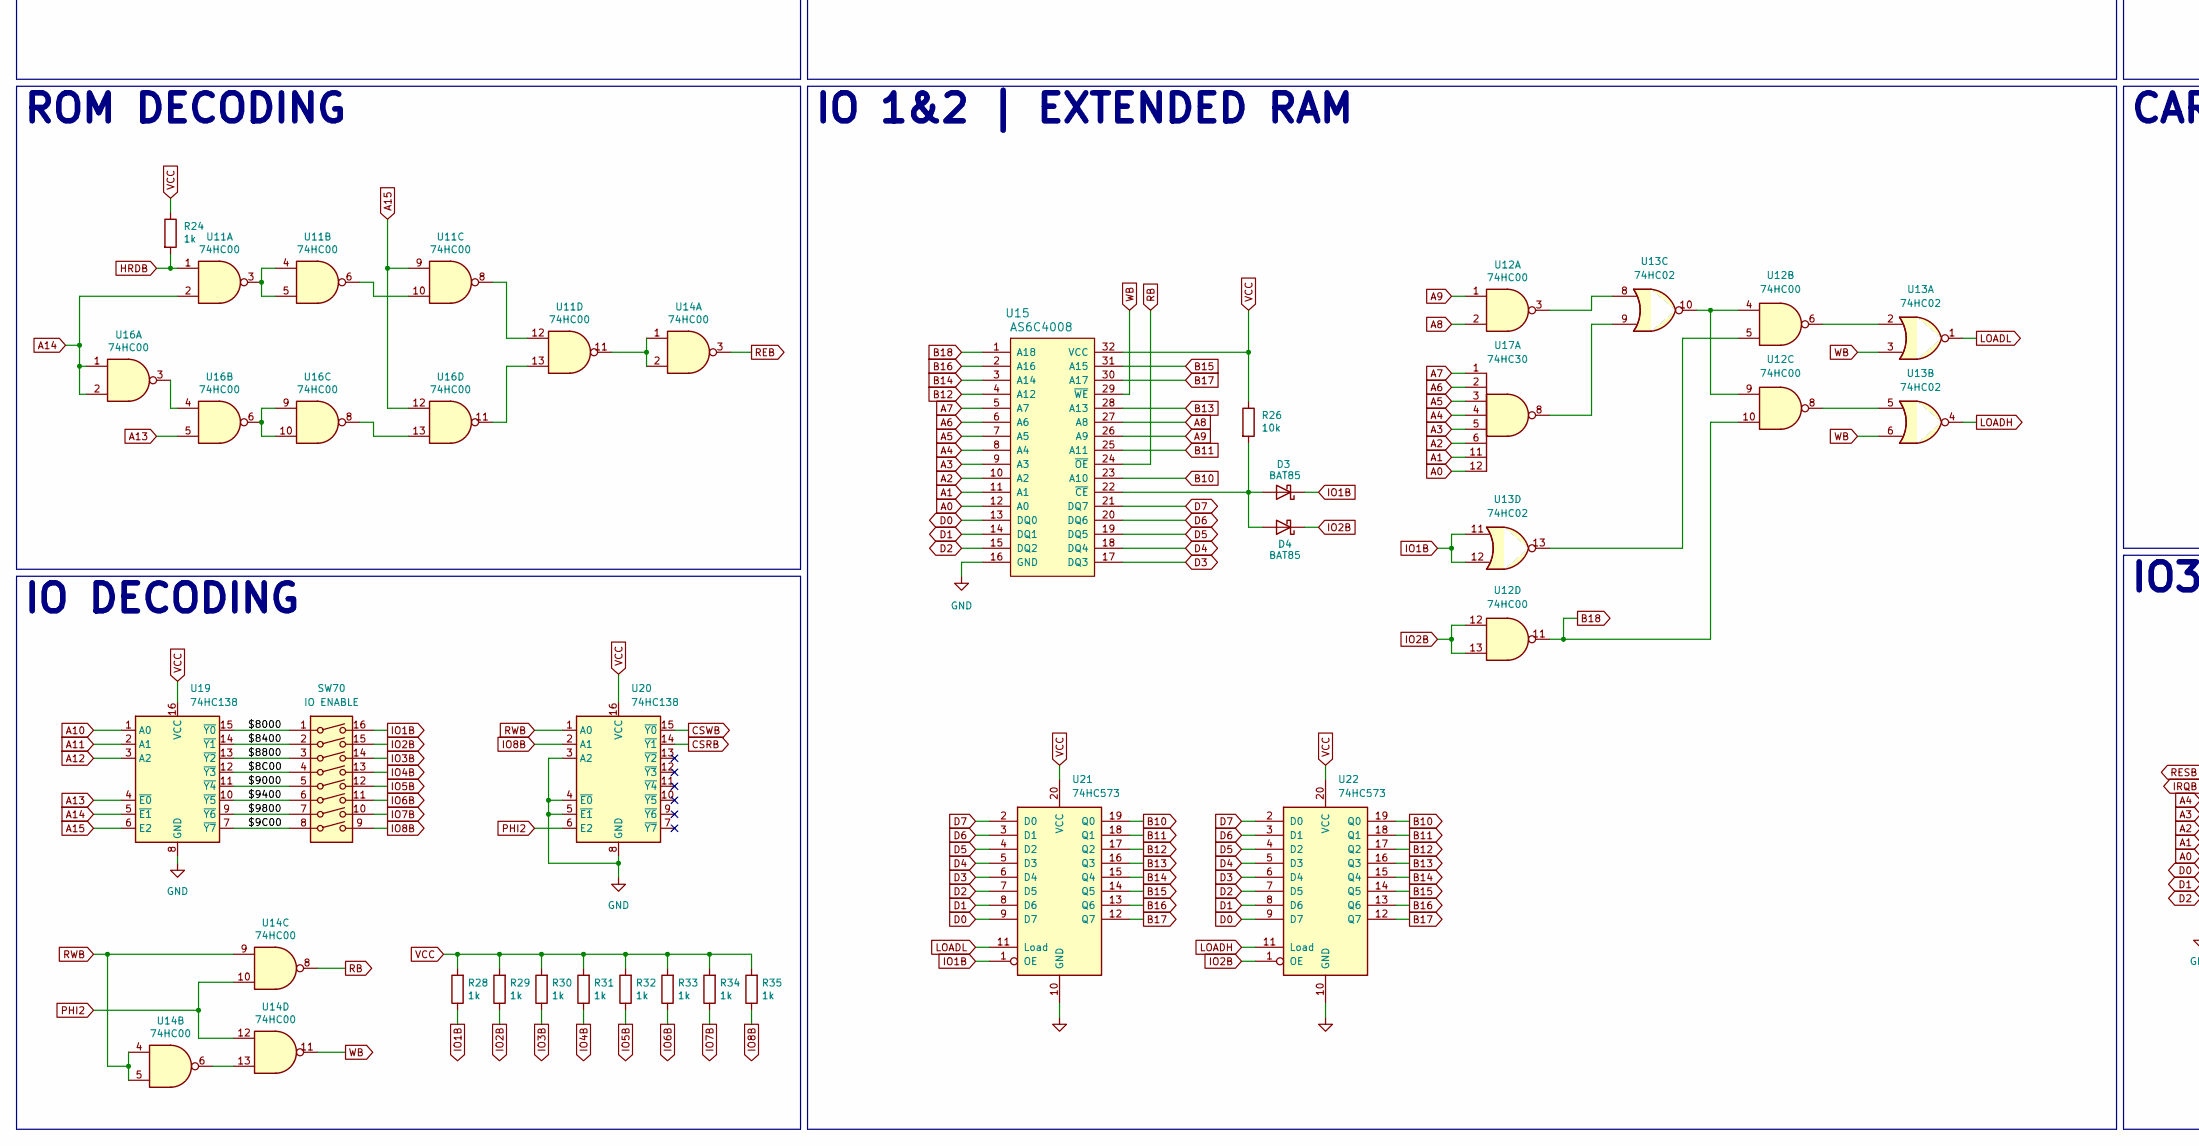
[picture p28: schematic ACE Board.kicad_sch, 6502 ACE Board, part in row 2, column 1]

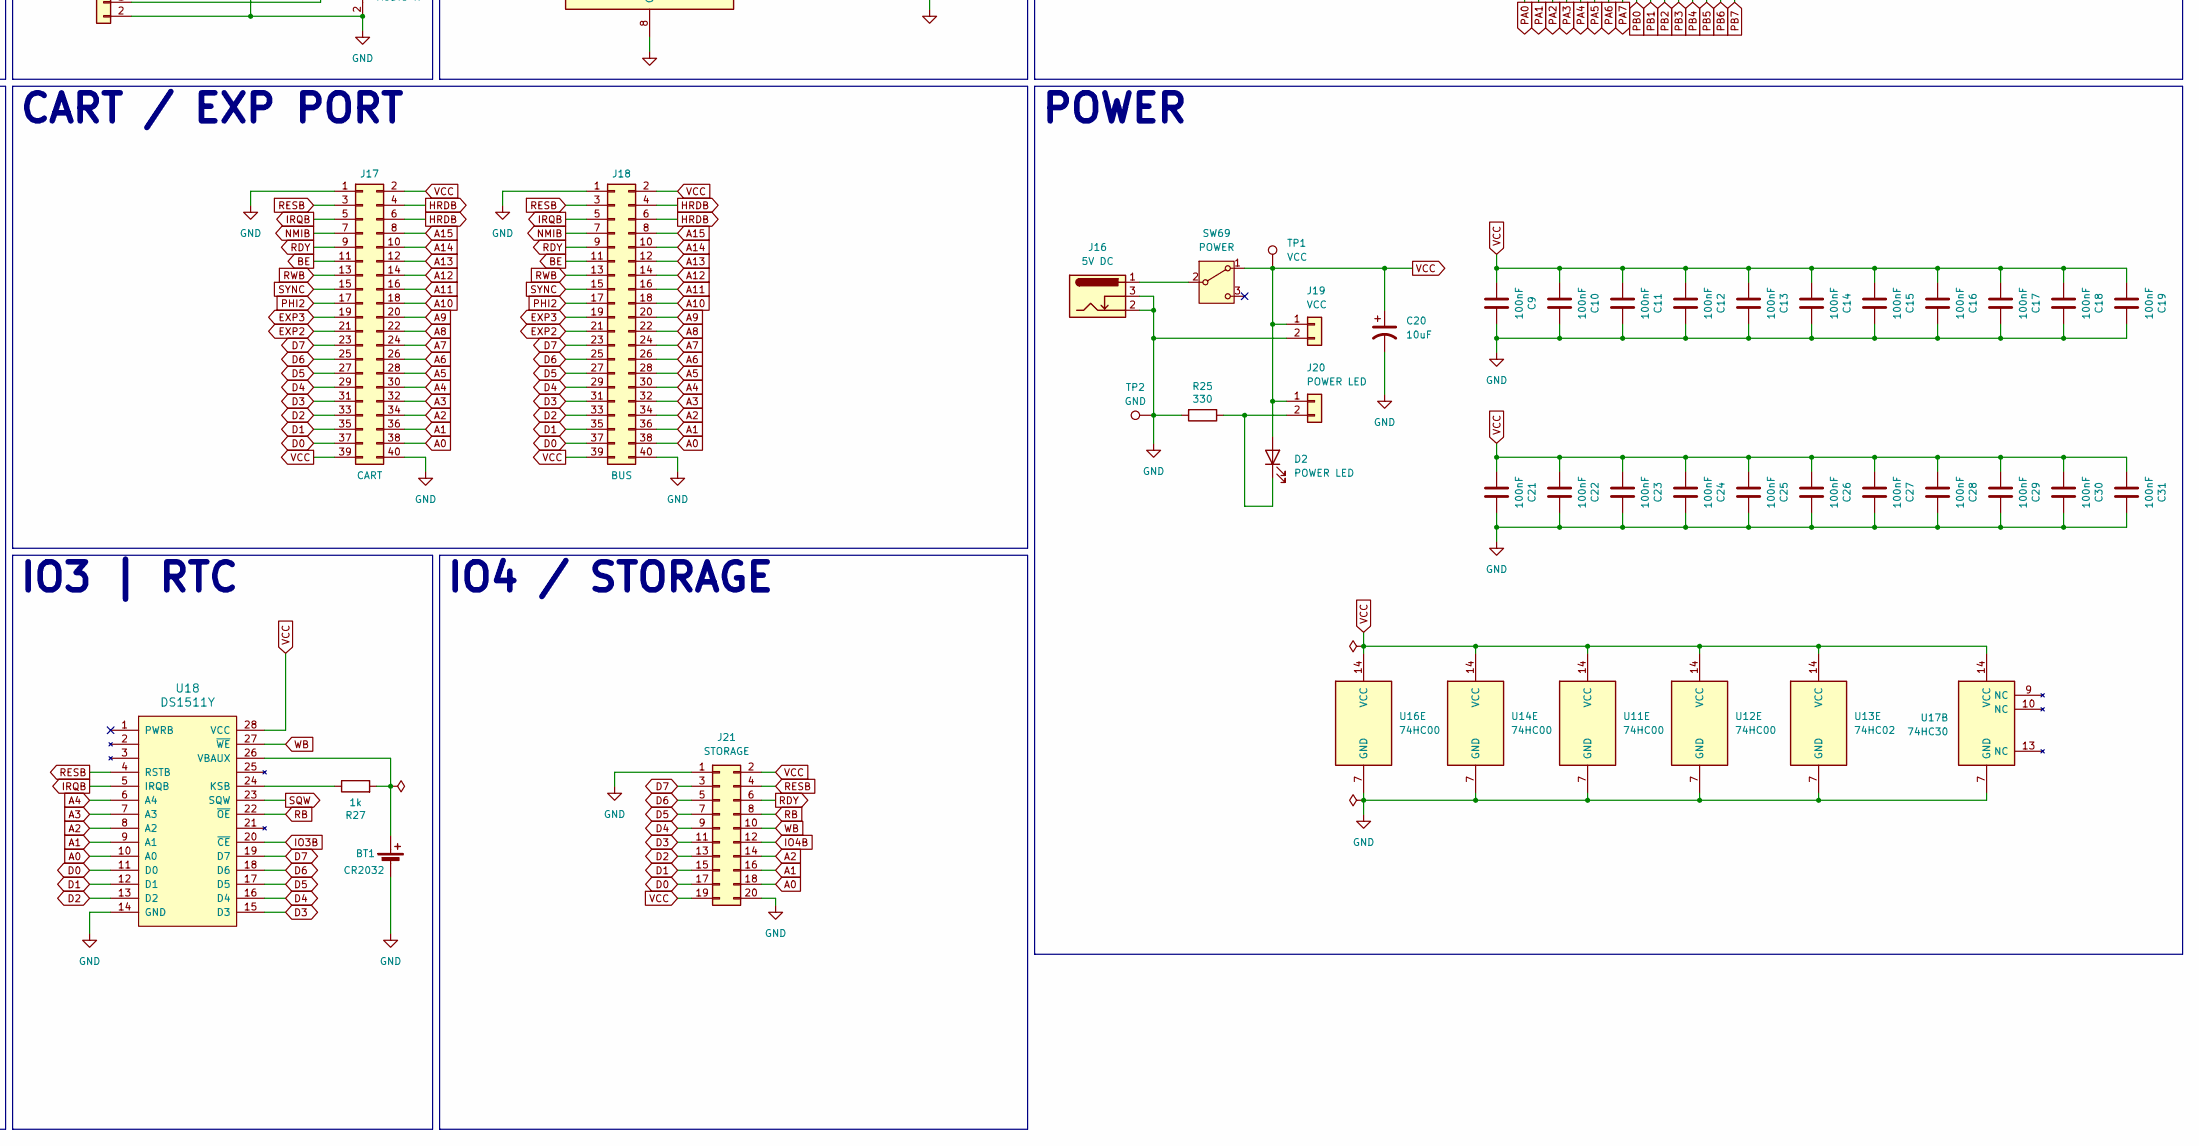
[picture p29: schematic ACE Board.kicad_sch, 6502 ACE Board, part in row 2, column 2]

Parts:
BT1: CR2032; BAT_BAT-HLD-001-THM; MPN BAT-HLD-001-THM; Digikey BAT-HLD-001-THM-ND
C1, C9, C10, C11, C12, C13, C14, C15, C16, C17, C18, C19, C21, C22, C23, C24, C25, C26, C27, C28, C29, C30, C31: 100nF; C_Disc_D5.0mm_W2.5mm_P2.50mm; Digikey 478-5732-ND
C2, C3, C5, C6, C8: 1uF; C_Disc_D5.0mm_W2.5mm_P2.50mm; Digikey 478-7667-ND
C4, C7: 2.2nF; C_Disc_D5.0mm_W2.5mm_P2.50mm; Digikey 478-SR151C222KAATR1CT-ND
C20: 10uF; CP_Radial_D4.0mm_P1.50mm
D1, D3, D4: BAT85; D_DO-35_SOD27_P7.62mm_Horizontal; Digikey BAT85SCT-ND
D2: POWER LED; LED_D3.0mm; Digikey 732-5008-ND
J1: CTS EN; PinHeader_1x03_P2.54mm_Vertical
J2: RESET SW; PinHeader_1x02_P2.54mm_Vertical
J3: DCD EN; PinHeader_1x03_P2.54mm_Vertical
J4: VDD; PinHeader_1x02_P2.54mm_Vertical
J5: JOYSTICK A; DSUB-9_Pins_Horizontal_P2.77x2.84mm_EdgePinOffset7.70mm_Hou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; MPN D09P33E4GX00LF; Digikey 609-1481-ND
J6: PADDLES; PinHeader_1x04_P2.54mm_Vertical
J7: JOYSTICK B; DSUB-9_Pins_Horizontal_P2.77x2.84mm_EdgePinOffset7.70mm_Hou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; MPN D09P33E4GX00LF; Digikey 609-1481-ND
J8: PORT B; 6502 GPIO Connector; Digikey 2057-BHR-12-VUA-ND
J9: PORT A; 6502 GPIO Connector; Digikey 2057-BHR-12-VUA-ND
J10: AUDIO L; SWITCHCRAFT_PJRAN1X1U0XX; Digikey PJRAN1X1U02X-ND
J11: DB9 MALE (DTE); DSUB-9_Pins_Horizontal_P2.77x2.84mm_EdgePinOffset7.70mm_Hou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; MPN D09P33E4GX00LF; Digikey 609-1481-ND
J12: PS/2; KMDGX-6S-BS; Mouser 806-KMDGX-6S-BS
J13: KEYBOARD; PinHeader_1x16_P2.00mm_Vertical
J14: AUDIO R; SWITCHCRAFT_PJRAN1X1U0XX; Digikey PJRAN1X1U03X-ND
J15: AUDIO; PinHeader_1x02_P2.54mm_Vertical
J16: 5V DC; BarrelJack_Horizontal; Digikey 2073-DCJ200-10-A-K1-K-ND
J17: CART; RHDR40W82P485X254_2X20_5740X93; Digikey A31723-ND
J18: BUS; 6502 Bus Connector
J19: VCC; PinHeader_1x02_P2.54mm_Vertical
J20: POWER LED; PinHeader_1x02_P2.54mm_Vertical
J21: STORAGE; PinSocket_2x10_P2.54mm_Horizontal; MPN PPPC102LJBN-RC; Digikey S5563-ND
R1, R2, R3, R4, R26: 10k; R_Axial_DIN0204_L3.6mm_D1.6mm_P5.08mm_Horizontal; Digikey RNF18FTD1K00CT-ND
R5: 10k; R_Axial_DIN0204_L3.6mm_D1.6mm_P5.08mm_Horizontal; Digikey RNF18FTD10K0CT-ND
R6, R7, R8, R9, R10, R11, R12, R13, R14, R15, R16, R17, R18, R19, R20, R21, R22, R23, R24, R27, R28, R29, R30, R31, R32, R33, R34, R35: 1k; R_Axial_DIN0204_L3.6mm_D1.6mm_P5.08mm_Horizontal; Digikey RNF18FTD1K00CT-ND
R25: 330; R_Axial_DIN0204_L3.6mm_D1.6mm_P5.08mm_Horizontal
SW1: `; SW_Cherry_MX_1.00u_PCB; Digikey CH196-ND
SW2: 1; SW_Cherry_MX_1.00u_PCB; Digikey CH196-ND
SW3: 2; SW_Cherry_MX_1.00u_PCB; Digikey CH196-ND
SW4: 3; SW_Cherry_MX_1.00u_PCB; Digikey CH196-ND
SW5: 4; SW_Cherry_MX_1.00u_PCB; Digikey CH196-ND
SW6: 5; SW_Cherry_MX_1.00u_PCB; Digikey CH196-ND
SW7: 6; SW_Cherry_MX_1.00u_PCB; Digikey CH196-ND
SW8: 7; SW_Cherry_MX_1.00u_PCB; Digikey CH196-ND
SW9: 8; SW_Cherry_MX_1.00u_PCB; Digikey CH196-ND
SW10: 9; SW_Cherry_MX_1.00u_PCB; Digikey CH196-ND
SW11: 0; SW_Cherry_MX_1.00u_PCB; Digikey CH196-ND
SW12: -; SW_Cherry_MX_1.00u_PCB; Digikey CH196-ND
SW13: =; SW_Cherry_MX_1.00u_PCB; Digikey CH196-ND
SW14: BACKSPACE; SW_Cherry_MX_2.00u_PCB; Digikey CH196-ND
SW15: ESCAPE; SW_Cherry_MX_1.00u_PCB; Digikey CH196-ND
SW16: TAB; SW_Cherry_MX_1.50u_PCB; Digikey CH196-ND
SW17: RESET; SW_PUSH_6mm
SW18: Q; SW_Cherry_MX_1.00u_PCB; Digikey CH196-ND
SW19: W; SW_Cherry_MX_1.00u_PCB; Digikey CH196-ND
SW20: E; SW_Cherry_MX_1.00u_PCB; Digikey CH196-ND
SW21: R; SW_Cherry_MX_1.00u_PCB; Digikey CH196-ND
SW22: T; SW_Cherry_MX_1.00u_PCB; Digikey CH196-ND
SW23: Y; SW_Cherry_MX_1.00u_PCB; Digikey CH196-ND
SW24: U; SW_Cherry_MX_1.00u_PCB; Digikey CH196-ND
SW25: I; SW_Cherry_MX_1.00u_PCB; Digikey CH196-ND
SW26: O; SW_Cherry_MX_1.00u_PCB; Digikey CH196-ND
SW27: P; SW_Cherry_MX_1.00u_PCB; Digikey CH196-ND
SW28: [; SW_Cherry_MX_1.00u_PCB; Digikey CH196-ND
SW29: ]; SW_Cherry_MX_1.00u_PCB; Digikey CH196-ND
SW30: \; SW_Cherry_MX_1.50u_PCB; Digikey CH196-ND
SW31: INSERT; SW_Cherry_MX_1.00u_PCB; Digikey CH196-ND
SW32: CAPS LOCK; SW_Cherry_MX_1.75u_PCB; Digikey CH196-ND
SW33: A; SW_Cherry_MX_1.00u_PCB; Digikey CH196-ND
SW34: S; SW_Cherry_MX_1.00u_PCB; Digikey CH196-ND
SW35: D; SW_Cherry_MX_1.00u_PCB; Digikey CH196-ND
SW36: F; SW_Cherry_MX_1.00u_PCB; Digikey CH196-ND
SW37: G; SW_Cherry_MX_1.00u_PCB; Digikey CH196-ND
SW38: H; SW_Cherry_MX_1.00u_PCB; Digikey CH196-ND
SW39: J; SW_Cherry_MX_1.00u_PCB; Digikey CH196-ND
SW40: K; SW_Cherry_MX_1.00u_PCB; Digikey CH196-ND
SW41: L; SW_Cherry_MX_1.00u_PCB; Digikey CH196-ND
SW42, SW50: SHIFT; SW_Cherry_MX_2.25u_PCB; Digikey CH196-ND
SW43: ;; SW_Cherry_MX_1.00u_PCB; Digikey CH196-ND
SW44: '; SW_Cherry_MX_1.00u_PCB; Digikey CH196-ND
SW45: ENTER; SW_Cherry_MX_2.25u_PCB; Digikey CH196-ND
SW46: DELETE; SW_Cherry_MX_1.00u_PCB; Digikey CH196-ND
SW47: Z; SW_Cherry_MX_1.00u_PCB; Digikey CH196-ND
SW48: X; SW_Cherry_MX_1.00u_PCB; Digikey CH196-ND
SW49: C; SW_Cherry_MX_1.00u_PCB; Digikey CH196-ND
SW51: V; SW_Cherry_MX_1.00u_PCB; Digikey CH196-ND
SW52: B; SW_Cherry_MX_1.00u_PCB; Digikey CH196-ND
SW53: N; SW_Cherry_MX_1.00u_PCB; Digikey CH196-ND
SW54: M; SW_Cherry_MX_1.00u_PCB; Digikey CH196-ND
SW55: ,; SW_Cherry_MX_1.00u_PCB; Digikey CH196-ND
SW56: .; SW_Cherry_MX_1.00u_PCB; Digikey CH196-ND
SW57: /; SW_Cherry_MX_1.00u_PCB; Digikey CH196-ND
SW58: UP ARROW; SW_Cherry_MX_1.00u_PCB; Digikey CH196-ND
SW59, SW67: CTRL; SW_Cherry_MX_1.25u_PCB; Digikey CH196-ND
SW60, SW68: ALT; SW_Cherry_MX_1.25u_PCB; Digikey CH196-ND
SW61: MENU; SW_Cherry_MX_1.00u_PCB; Digikey CH196-ND
SW62: SPACE; SW_Cherry_MX_6.25u_PCB; Digikey CH196-ND
SW63: FN; SW_Cherry_MX_1.25u_PCB; Digikey CH196-ND
SW64: LEFT ARROW; SW_Cherry_MX_1.00u_PCB; Digikey CH196-ND
SW65: DOWN ARROW; SW_Cherry_MX_1.00u_PCB; Digikey CH196-ND
SW66: RIGHT ARROW; SW_Cherry_MX_1.00u_PCB; Digikey CH196-ND
SW69: POWER; SW_400MSP1R6BLKM6QE; Digikey EG4326-ND
SW70: IO ENABLE; SW_DIP_SPSTx08_Slide_9.78x22.5mm_W7.62mm_P2.54mm
TP1: VCC; TestPoint_Pad_2.5x2.5mm
TP2: GND; TestPoint_Pad_2.5x2.5mm
U1: 65C02; DIP-40_W15.24mm_Socket_LongPads; Mouser 955-W65C02S6TPG-14
U2: 65C22; DIP-40_W15.24mm_Socket_LongPads; Mouser 955-W65C22N6TPG-14
U3: Pico9918A; DIP-40_W15.24mm_Socket_LongPads
U4: 65C51; DIP-28_W15.24mm_Socket_LongPads
U5: 74HC163; DIP-16_W7.62mm_Socket_LongPads; Digikey 296-8246-5-ND
U6: ATmega1284-P; DIP-40_W15.24mm_Socket_LongPads; Digikey ATMEGA1284-PU-ND
U7: AS6C62256; DIP-28_W15.24mm_Socket_LongPads; Digikey 1450-1033-ND
U8: AT28C256; DIP_Socket-28_W11.9mm_W12.7mm_W15.24mm_W17.78mm_W18.5mm_3M_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; Digikey AT28C256-15PU-ND
U9: 6581; DIP-28_W15.24mm_Socket_LongPads
U10: MAX238xNG+; DIP-24_W7.62mm_Socket_LongPads; Digikey MAX238CNG+-ND
U11, U12, U14, U16: 74HC00; DIP-14_W7.62mm_Socket_LongPads; Digikey 296-1563-5-ND
U13: 74HC02; DIP-14_W7.62mm_Socket_LongPads
U15: AS6C4008; DIP-32_W15.24mm_Socket_LongPads; Digikey 1450-1027-ND
U17: 74HC30; DIP-14_W7.62mm_Socket_LongPads; Digikey 296-9196-5-ND
U18: DS1511Y; DIP-28_W15.24mm_Socket_LongPads; Digikey DS1511Y+-ND
U19, U20: 74HC138; DIP-16_W7.62mm_Socket_LongPads; Digikey 296-1575-5-ND
U21, U22: 74HC573; DIP-20_W7.62mm_Socket_LongPads; Digikey 296-12815-5-ND
X1: 16MHz; Oscillator_DIP-14; Digikey X947-ND
Y1: 1.8432 Mhz; Crystal_HC49-U_Vertical; Digikey 3155-1.8432M20P2/49U-ND

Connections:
/$8C00: SW70.4, U19.12 (~Y3)
/$9C00: SW70.8, U19.7 (~Y7)
/$8000: SW70.1, U19.15 (~Y0)
/$8400: SW70.2, U19.14 (~Y1)
/$8800: SW70.3, U19.13 (~Y2)
/$9000: SW70.5, U19.11 (~Y4)
/$9400: SW70.6, U19.10 (~Y5)
/$9800: SW70.7, U19.9 (~Y6)
A0: J17.38, J18.38, J21.18, U1.9 (A0), U2.38 (RS0), U3.13 (MODE0), U4.13 (RS0), U7.10 (A0), U8.10 (A0), U9.9 (A0), U15.12 (A0), U17.12, U18.10 (A0)
A1: J17.36, J18.36, J21.16, U1.10 (A1), U2.37 (RS1), U3.11 (MODE1), U4.14 (RS1), U7.9 (A1), U8.9 (A1), U9.10 (A1), U15.11 (A1), U17.11, U18.9 (A1)
A2: J17.34, J18.34, J21.14, U1.11 (A2), U2.36 (RS2), U7.8 (A2), U8.8 (A2), U9.11 (A2), U15.10 (A2), U17.6, U18.8 (A2)
A3: J17.32, J18.32, U1.12 (A3), U2.35 (RS3), U7.7 (A3), U8.7 (A3), U9.12 (A3), U15.9 (A3), U17.5, U18.7 (A3)
A4: J17.30, J18.30, U1.13 (A4), U7.6 (A4), U8.6 (A4), U9.13 (A4), U15.8 (A4), U17.4, U18.6 (A4)
A5: J17.28, J18.28, U1.14 (A5), U7.5 (A5), U8.5 (A5), U15.7 (A5), U17.3
A6: J17.26, J18.26, U1.15 (A6), U7.4 (A6), U8.4 (A6), U15.6 (A6), U17.2
A7: J17.24, J18.24, U1.16 (A7), U7.3 (A7), U8.3 (A7), U15.5 (A7), U17.1
A8: J17.22, J18.22, U1.17 (A8), U7.25 (A8), U8.25 (A8), U12.2, U15.27 (A8)
A9: J17.20, J18.20, U1.18 (A9), U7.24 (A9), U8.24 (A9), U12.1, U15.26 (A9)
A10: J17.18, J18.18, U1.19 (A10), U7.21 (A10), U8.21 (A10), U19.1 (A0)
A11: J17.16, J18.16, U1.20 (A11), U7.23 (A11), U8.23 (A11), U19.2 (A1)
A12: J17.14, J18.14, U1.22 (A12), U7.2 (A12), U8.2 (A12), U19.3 (A2)
A13: J17.12, J18.12, U1.23 (A13), U7.26 (A13), U8.26 (A13), U16.5, U19.4 (~E0)
A14: J17.10, J18.10, U1.24 (A14), U7.1 (A14), U8.1 (A14), U11.2, U16.1, U16.2, U19.5 (~E1)
A15: J17.8, J18.8, U1.25 (A15), U7.20 (~CE), U11.9, U16.12, U19.6 (E2)
B10: U15.23 (A10), U21.19 (Q0), U22.19 (Q0)
B11: U15.25 (A11), U21.18 (Q1), U22.18 (Q1)
B12: U15.4 (A12), U21.17 (Q2), U22.17 (Q2)
B13: U15.28 (A13), U21.16 (Q3), U22.16 (Q3)
B14: U15.3 (A14), U21.15 (Q4), U22.15 (Q4)
B15: U15.31 (A15), U21.14 (Q5), U22.14 (Q5)
B16: U15.2 (A16), U21.13 (Q6), U22.13 (Q6)
B17: U15.30 (A17), U21.12 (Q7), U22.12 (Q7)
B18: U12.10, U12.11, U15.1 (A18)
BE: J17.11, J18.11, R1.1, U1.36 (BE)
CA1: J9.11, U2.40 (CA1), U6.14 (PD0)
CA2: J9.12, U2.39 (CA2), U6.15 (PD1)
CB1: J8.11, U2.18 (CB1), U6.18 (PD4)
CB2: J8.12, U2.19 (CB2), U6.19 (PD5)
CSRB: U3.15 (~CSR), U20.14 (~Y1)
CSWB: U3.14 (~CSW), U20.15 (~Y0)
CTS: J11.8, U10.3 (R2IN)
CTSIN: J1.3, U10.4 (R2OUT)
D0: J17.37, J18.37, J21.17, U1.33 (D0), U2.33 (D0), U3.17 (CD7), U4.18 (D0), U7.11 (DQ0), U8.11 (I/O0), U9.15 (D0), U15.13 (DQ0), U18.11 (D0), U21.9 (D7), U22.9 (D7)
D1: J17.35, J18.35, J21.15, U1.32 (D1), U2.32 (D1), U3.18 (CD6), U4.19 (D1), U7.12 (DQ1), U8.12 (I/O1), U9.16 (D1), U15.14 (DQ1), U18.12 (D1), U21.8 (D6), U22.8 (D6)
D2: J17.33, J18.33, J21.13, U1.31 (D2), U2.31 (D2), U3.19 (CD5), U4.20 (D2), U7.13 (DQ2), U8.13 (I/O2), U9.17 (D2), U15.15 (DQ2), U18.13 (D2), U21.7 (D5), U22.7 (D5)
D3: J17.31, J18.31, J21.11, U1.30 (D3), U2.30 (D3), U3.20 (CD4), U4.21 (D3), U7.15 (DQ3), U8.15 (I/O3), U9.18 (D3), U15.17 (DQ3), U18.15 (D3), U21.6 (D4), U22.6 (D4)
D4: J17.29, J18.29, J21.9, U1.29 (D4), U2.29 (D4), U3.21 (CD3), U4.22 (D4), U7.16 (DQ4), U8.16 (I/O4), U9.19 (D4), U15.18 (DQ4), U18.16 (D4), U21.5 (D3), U22.5 (D3)
D5: J17.27, J18.27, J21.7, U1.28 (D5), U2.28 (D5), U3.22 (CD2), U4.23 (D5), U7.17 (DQ5), U8.17 (I/O5), U9.20 (D5), U15.19 (DQ5), U18.17 (D5), U21.4 (D2), U22.4 (D2)
D6: J17.25, J18.25, J21.5, U1.27 (D6), U2.27 (D6), U3.23 (CD1), U4.24 (D6), U7.18 (DQ6), U8.18 (I/O6), U9.21 (D6), U15.20 (DQ6), U18.18 (D6), U21.3 (D1), U22.3 (D1)
D7: J17.23, J18.23, J21.3, U1.26 (D7), U2.26 (D7), U3.24 (CD0), U4.25 (D7), U7.19 (DQ7), U8.19 (I/O7), U9.22 (D7), U15.21 (DQ7), U18.19 (D7), U21.2 (D0), U22.2 (D0)
DCD: J11.1, U10.16 (R2IN)
DCDIN: J3.3, U10.17 (R2OUT)
DSR: J11.6, U10.23 (R1IN)
DSRIN: U4.17 (DSRB), U10.22 (R1OUT)
DTR: J11.4, U10.24 (T1OUT)
DTROUT: U4.11 (DTRB), U10.19 (T1IN)
EXP2: J17.21, J18.21
EXP3: J17.19, J18.19
GND: BT1.2 (-), C1.1, C5.2, C6.2, C9.2, C10.2, C11.2, C12.2, C13.2, C14.2, C15.2, C16.2, C17.2, C18.2, C19.2, C20.2, C21.2, C22.2, C23.2, C24.2, C25.2, C26.2, C27.2, C28.2, C29.2, C30.2, C31.2, J1.1, J2.2, J3.1, J4.2, J5.8, J5.SH (PAD), J6.1, J7.8, J7.SH (PAD), J8.2, J9.2, J10.2 (Ext), J11.5, J11.SH (PAD), J12.3, J14.2 (Ext), J15.2, J16.2, J16.3, J17.1, J17.40, J18.1, J18.40, J19.2, J21.1, J21.20, R23.2, R25.2, SW17.2, TP2.1 (1_1), U1.21 (VSS), U2.1 (VSS), U3.12 (VSS), U4.1 (GND), U5.8 (GND), U6.11 (GND), U6.31 (GND), U7.14 (GND), U8.14 (GND), U9.14 (GND), U10.8 (GND), U11.7 (GND), U12.7 (GND), U13.7 (GND), U14.7 (GND), U15.16 (GND), U16.7 (GND), U17.7 (GND), U18.14 (GND), U19.8 (GND), U20.3 (A2), U20.4 (~E0), U20.5 (~E1), U20.8 (GND), U21.10 (GND), U22.10 (GND), X1.7 (GND)
HRDB: J17.4, J17.6, J18.4, J18.6, R24.2, U11.1
IO1B: D3.1 (K), R28.1, SW70.16, U13.11, U13.12, U21.1 (OE)
IO2B: D4.1 (K), R29.1, SW70.15, U12.12, U12.13, U22.1 (OE)
IO3B: R30.1, SW70.14, U18.20 (~CE)
IO4B: J21.12, R31.1, SW70.13
IO5B: R32.1, SW70.12, U4.3 (CS1B)
IO6B: R33.1, SW70.11, U2.23 (CS2B)
IO7B: R34.1, SW70.10, U9.8 (~CS)
IO8B: R35.1, SW70.9, U20.2 (A1)
IRQB: D1.2 (A), J17.5, J18.5, R3.1, U1.4 (IRQB), U2.21 (IRQB), U4.26 (IRQB), U18.5 (IRQB)
LOADH: U13.4, U22.11 (Load)
LOADL: U13.1, U21.11 (Load)
NMIB: J17.7, J18.7, R2.1, U1.6 (NMIB), U6.21 (PD7)
unnamed: BT1.1 (+), R27.2, U18.26 (VBAUX)
unnamed: D1.1 (K), U3.16 (~INT)
unnamed: D2.1 (K), J20.2, R25.1
unnamed: D3.2 (A), D4.2 (A), R26.2, U15.22 (~CE)
unnamed: J1.2, U4.9 (CTSB)
unnamed: J2.1, SW17.1, U6.22 (PC0)
unnamed: J3.2, U4.16 (DCDB)
unnamed: J4.1, U9.28 (VDD)
unnamed: J6.2, U9.23 (POTY)
unnamed: J6.3, U9.24 (POTX)
unnamed: C8.2, J10.1 (In), J14.1 (In), J15.1
unnamed: J16.1, SW69.2 (B)
unnamed: U4.6 (XTALI), Y1.1
unnamed: U4.7 (XTALO), Y1.2
unnamed: C1.2, U6.32 (AREF)
unnamed: R6.2, U6.9 (~RESET)
unnamed: C4.2, U9.1 (CAP1A)
unnamed: C4.1, U9.2 (CAP1B)
unnamed: C7.2, U9.3 (CAP2A)
unnamed: C7.1, U9.4 (CAP2B)
unnamed: C8.1, R23.1, U9.27 (OUT)
unnamed: C2.1, U10.10 (C1+)
unnamed: C2.2, U10.12 (C1-)
unnamed: C3.1, U10.13 (C2+)
unnamed: C3.2, U10.14 (C2-)
unnamed: C5.1, U10.11 (VS+)
unnamed: C6.1, U10.15 (VS-)
unnamed: U11.3, U11.4, U11.5
unnamed: U11.6, U11.10
unnamed: U11.11, U14.1, U14.2
unnamed: U11.8, U11.12
unnamed: U11.13, U16.11
unnamed: U12.3, U13.8
unnamed: U12.4, U12.9, U13.10
unnamed: U12.5, U13.13
unnamed: U12.6, U13.2
unnamed: U12.8, U13.5
unnamed: U13.9, U17.8
unnamed: U14.6, U14.13
unnamed: U16.3, U16.4
unnamed: U16.6, U16.9, U16.10
unnamed: U16.8, U16.13
unnamed: R27.1, U18.24 (KSB)
PA0: J5.6, J9.4, J13.1, R7.1, SW1.1, SW2.1, SW3.1, SW4.1, SW5.1, SW6.1, SW7.1, SW8.1, U2.2 (PA0), U6.40 (PA0)
PA1: J5.7, J9.6, J13.2, R8.1, SW9.1, SW10.1, SW11.1, SW12.1, SW13.1, SW14.1, SW15.1, SW16.1, U2.3 (PA1), U6.39 (PA1)
PA2: J5.9, J9.8, J13.3, R9.1, SW18.1, SW19.1, SW20.1, SW21.1, SW22.1, SW23.1, SW24.1, SW25.1, U2.4 (PA2), U6.38 (PA2)
PA3: J5.5, J9.10, J13.4, R10.1, SW26.1, SW27.1, SW28.1, SW29.1, SW30.1, SW31.1, SW32.1, SW33.1, U2.5 (PA3), U6.37 (PA3)
PA4: J5.1, J9.9, J13.5, R11.1, SW34.1, SW35.1, SW36.1, SW37.1, SW38.1, SW39.1, SW40.1, SW41.1, U2.6 (PA4), U6.36 (PA4)
PA5: J5.2, J9.7, J13.6, R12.1, SW42.1, SW43.1, SW44.1, SW45.1, SW46.1, SW47.1, SW48.1, SW49.1, SW50.1, U2.7 (PA5), U6.35 (PA5)
PA6: J5.3, J9.5, J13.7, R13.1, SW51.1, SW52.1, SW53.1, SW54.1, SW55.1, SW56.1, SW57.1, SW58.1, U2.8 (PA6), U6.34 (PA6)
PA7: J5.4, J9.3, J13.8, R14.1, SW59.1, SW60.1, SW61.1, SW62.1, SW63.1, SW64.1, SW65.1, SW66.1, SW67.1, SW68.1, U2.9 (PA7), U6.33 (PA7)
PB0: J7.6, J8.4, J13.9, R15.1, SW1.2, SW9.2, SW18.2, SW26.2, SW34.2, SW43.2, SW51.2, SW59.2, SW67.2, U2.10 (PB0), U6.1 (PB0)
PB1: J7.7, J8.6, J13.10, R16.1, SW2.2, SW10.2, SW19.2, SW27.2, SW35.2, SW44.2, SW52.2, SW61.2, U2.11 (PB1), U6.2 (PB1)
PB2: J7.9, J8.8, J13.11, R17.1, SW3.2, SW11.2, SW20.2, SW28.2, SW36.2, SW45.2, SW53.2, SW60.2, SW68.2, U2.12 (PB2), U6.3 (PB2)
PB3: J7.5, J8.10, J13.12, R18.1, SW4.2, SW12.2, SW21.2, SW29.2, SW37.2, SW46.2, SW54.2, SW62.2, U2.13 (PB3), U6.4 (PB3)
PB4: J7.1, J8.9, J13.13, R19.1, SW5.2, SW13.2, SW22.2, SW30.2, SW38.2, SW42.2, SW50.2, SW55.2, SW63.2, U2.14 (PB4), U6.5 (PB4)
PB5: J7.2, J8.7, J13.14, R20.1, SW6.2, SW14.2, SW23.2, SW31.2, SW39.2, SW47.2, SW56.2, SW64.2, U2.15 (PB5), U6.6 (PB5)
PB6: J7.3, J8.5, J13.15, R21.1, SW7.2, SW15.2, SW24.2, SW32.2, SW40.2, SW48.2, SW57.2, SW65.2, U2.16 (PB6), U6.7 (PB6)
PB7: J7.4, J8.3, J13.16, R22.1, SW8.2, SW16.2, SW25.2, SW33.2, SW41.2, SW49.2, SW58.2, SW66.2, U2.17 (PB7), U6.8 (PB7)
PHI2: J17.17, J18.17, U1.37 (PHI2), U2.25 (PHI2), U4.27 (PHI2), U5.11 (Q3), U9.6 (PHI2), U14.10, U14.12, U20.6 (E2)
PHI2_16MHZ: U5.2 (CP), U6.13 (XTAL1), X1.8 (OUT)
PS2CLK: J12.5, U6.16 (PD2)
PS2DATA: J12.1, U6.17 (PD3)
RB: J21.8, U7.22 (~OE), U8.22 (~OE), U14.8, U15.24 (~OE), U18.22 (~OE)
RDY: J17.9, J18.9, J21.6, R4.1, U1.2 (RDY)
REB: U8.20 (~CE), U14.3
RESB: J17.3, J18.3, J21.4, R5.1, U1.40 (RESB), U2.34 (RESB), U3.34 (~RESET/SYNC), U4.4 (RESB), U6.29 (PC7), U9.5 (~RESET), U18.4 (RSTB)
RTS: J11.7, U10.1 (T2OUT)
RTSOUT: U4.8 (RTSB), U10.18 (T2IN)
RWB: J17.13, J18.13, U1.34 (RWB), U2.22 (RWB), U4.28 (RWB), U9.7 (R/~W), U14.4, U14.5, U14.9, U20.1 (A0)
RXD: J11.2, U10.7 (R1IN)
RXDIN: U4.12 (RXD), U10.6 (R1OUT)
SQW: U6.20 (PD6), U18.23 (SQW)
SYNC: J17.15, J18.15, U1.7 (SYNC)
TXD: J11.3, U10.2 (T1OUT)
TXDOUT: U4.10 (TXD), U10.5 (T1IN)
VCC: C9.1, C10.1, C11.1, C12.1, C13.1, C14.1, C15.1, C16.1, C17.1, C18.1, C19.1, C20.1, C21.1, C22.1, C23.1, C24.1, C25.1, C26.1, C27.1, C28.1, C29.1, C30.1, C31.1, D2.2 (A), J6.4, J8.1, J9.1, J12.4, J17.2, J17.39, J18.2, J18.39, J19.1, J20.1, J21.2, J21.19, R1.2, R2.2, R3.2, R4.2, R5.2, R6.1, R7.2, R8.2, R9.2, R10.2, R11.2, R12.2, R13.2, R14.2, R15.2, R16.2, R17.2, R18.2, R19.2, R20.2, R21.2, R22.2, R24.1, R26.1, R28.2, R29.2, R30.2, R31.2, R32.2, R33.2, R34.2, R35.2, SW69.1 (A), TP1.1 (1_1), U1.8 (VDD), U1.38 (SOB), U2.20 (VDD), U2.24 (CS1), U3.33 (VCC), U4.2 (CS0), U4.15 (VCC), U5.1 (~MR), U5.3 (D0), U5.4 (D1), U5.5 (D2), U5.6 (D3), U5.7 (CEP), U5.9 (~PE), U5.10 (CET), U5.16 (VCC), U6.10 (VCC), U6.30 (AVCC), U7.28 (VCC), U8.27 (~WE), U8.28 (VCC), U9.25 (VCC), U10.9 (VCC), U11.14 (VCC), U12.14 (VCC), U13.14 (VCC), U14.14 (VCC), U15.32 (VCC), U16.14 (VCC), U17.14 (VCC), U18.28 (VCC), U19.16 (VCC), U20.16 (VCC), U21.20 (VCC), U22.20 (VCC), X1.14 (Vcc)
WB: J21.10, U7.27 (~WE), U13.3, U13.6, U14.11, U15.29 (~WE), U18.27 (~WE)

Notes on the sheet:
ROM
RAM
IO4 / STORAGE
RAM / ROM
POWER
IO7 | SOUND
IO5 | SERIAL
IO8 | VIDEO
ROM DECODING
IO DECODING
IO 6 | GPIO
CART / EXP PORT
IO3 | RTC
CPU / CLOCK
IO 1&2 | EXTENDED RAM
KEYBOARD MATRIX

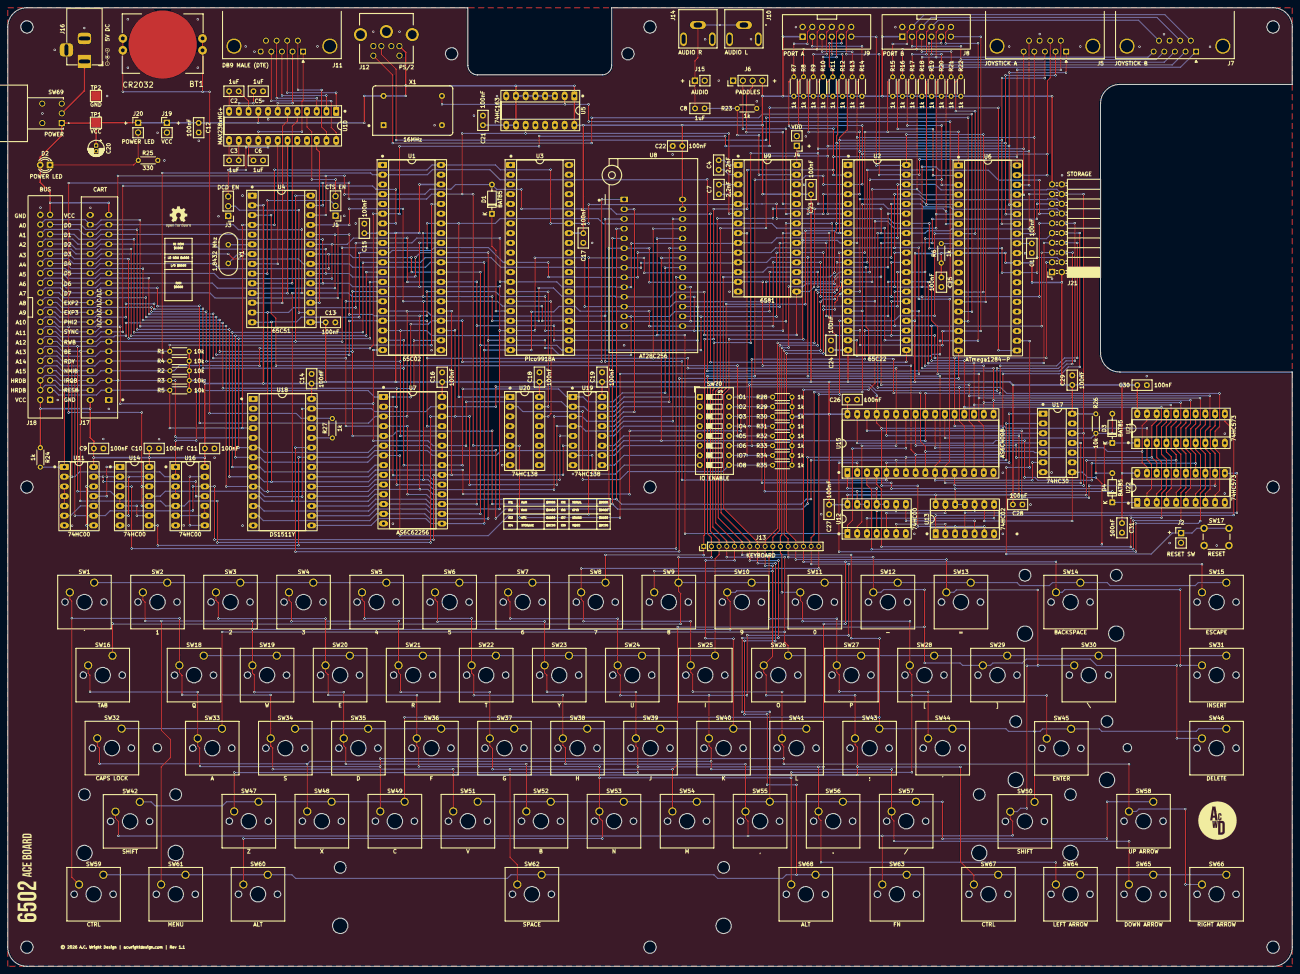
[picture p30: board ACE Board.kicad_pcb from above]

Board: 2 copper layers, 335.0 x 250.0 mm, 200 parts (0 on the bottom side), 150 nets.

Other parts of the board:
CENTERPOS: Polarity_Center_Positive_6mm_SilkScreen
H1, H2, H2#2, H2#3, H2#4, H2#5, H2#6, H3#2, H4: MountingHole; MountingHole_3.2mm_M3
H3, H3#3: MountingHole; MountingHole_2.2mm_M2

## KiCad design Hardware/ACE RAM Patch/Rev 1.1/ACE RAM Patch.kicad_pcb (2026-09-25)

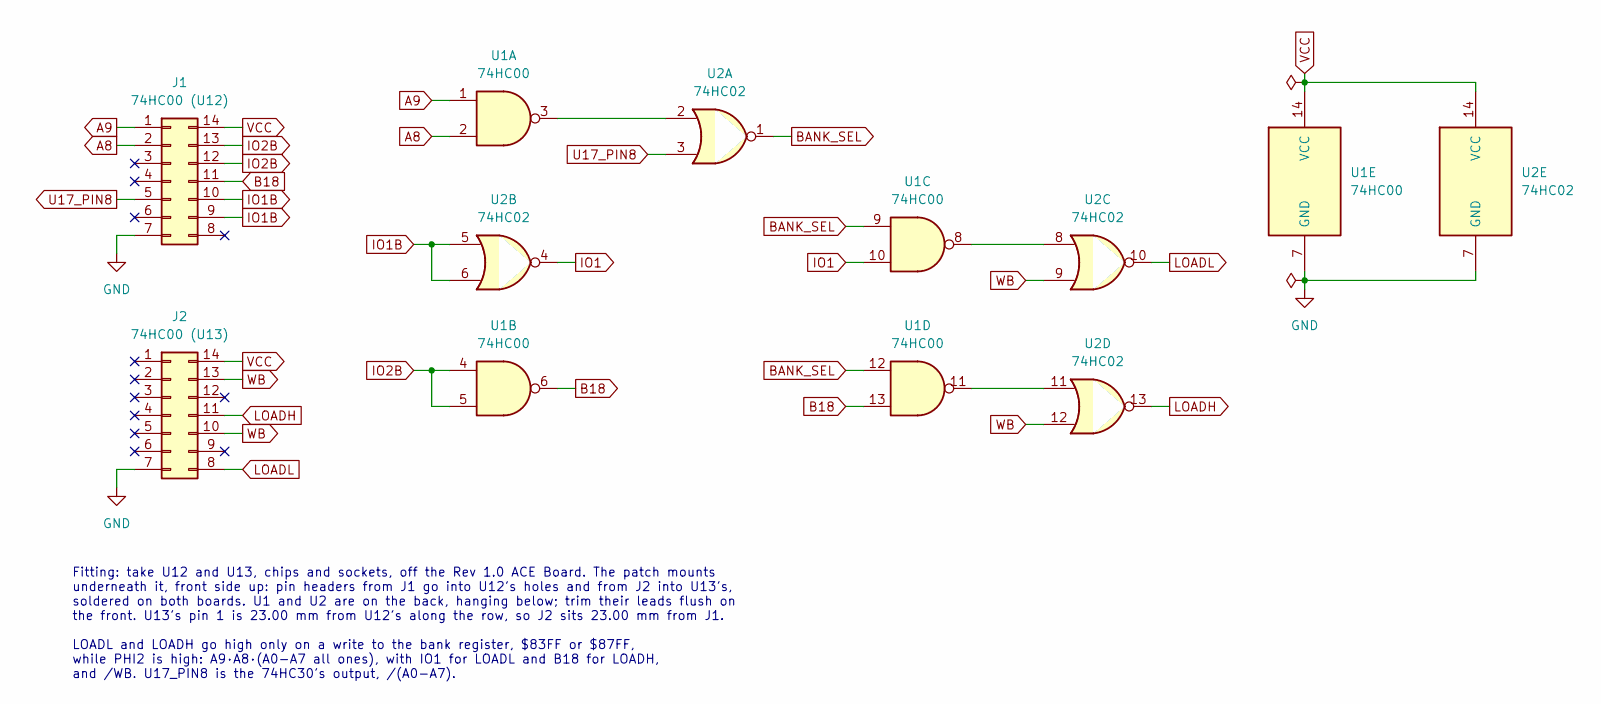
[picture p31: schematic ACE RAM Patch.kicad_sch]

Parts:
J1: 74HC00 (U12); DIP-14_W7.62mm_LongPads
J2: 74HC00 (U13); DIP-14_W7.62mm_LongPads
U1: 74HC00; DIP-14_W7.62mm_LongPads
U2: 74HC02; DIP-14_W7.62mm_LongPads

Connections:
A8: J1.2, U1.2
A9: J1.1, U1.1
B18: J1.11, U1.6, U1.13
BANK_SEL: U1.9, U1.12, U2.1
GND: J1.7, J2.7, U1.7 (GND), U2.7 (GND)
IO1: U1.10, U2.4
IO1B: J1.9, J1.10, U2.5, U2.6
IO2B: J1.12, J1.13, U1.4, U1.5
LOADH: J2.11, U2.13
LOADL: J2.8, U2.10
unnamed: U1.3, U2.2
unnamed: U1.8, U2.8
unnamed: U1.11, U2.11
U17_PIN8: J1.5, U2.3
VCC: J1.14, J2.14, U1.14 (VCC), U2.14 (VCC)
WB: J2.10, J2.13, U2.9, U2.12

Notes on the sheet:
Fitting: take U12 and U13, chips and sockets, off the Rev 1.0 ACE Board. The patch mounts underneath it, front side up: pin headers from J1 go into U12's holes and from J2 into U13's, soldered on both boards. U1 and U2 are on the back, hanging below; trim their leads flush on the front. U13's pin 1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

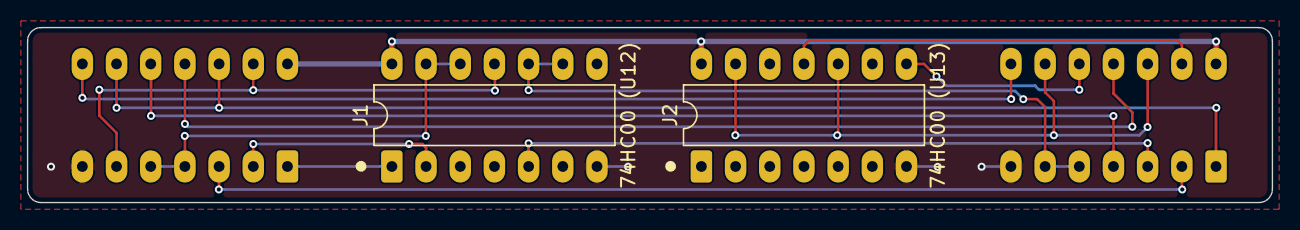
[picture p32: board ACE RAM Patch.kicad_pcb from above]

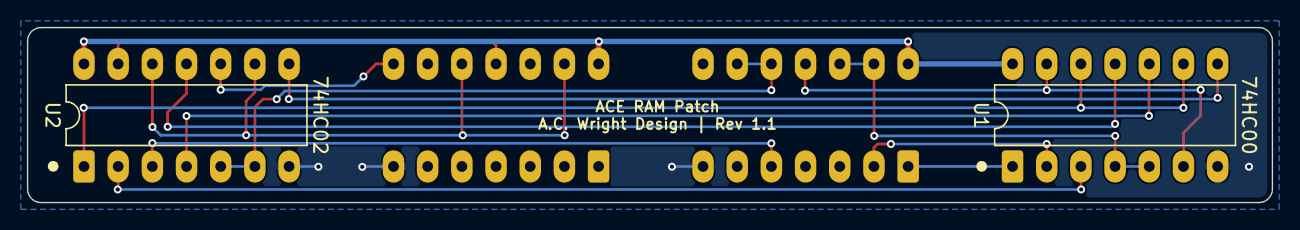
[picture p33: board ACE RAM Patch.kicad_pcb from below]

Board: 2 copper layers, 92.5 x 13.0 mm, 4 parts (2 on the bottom side), 16 nets.

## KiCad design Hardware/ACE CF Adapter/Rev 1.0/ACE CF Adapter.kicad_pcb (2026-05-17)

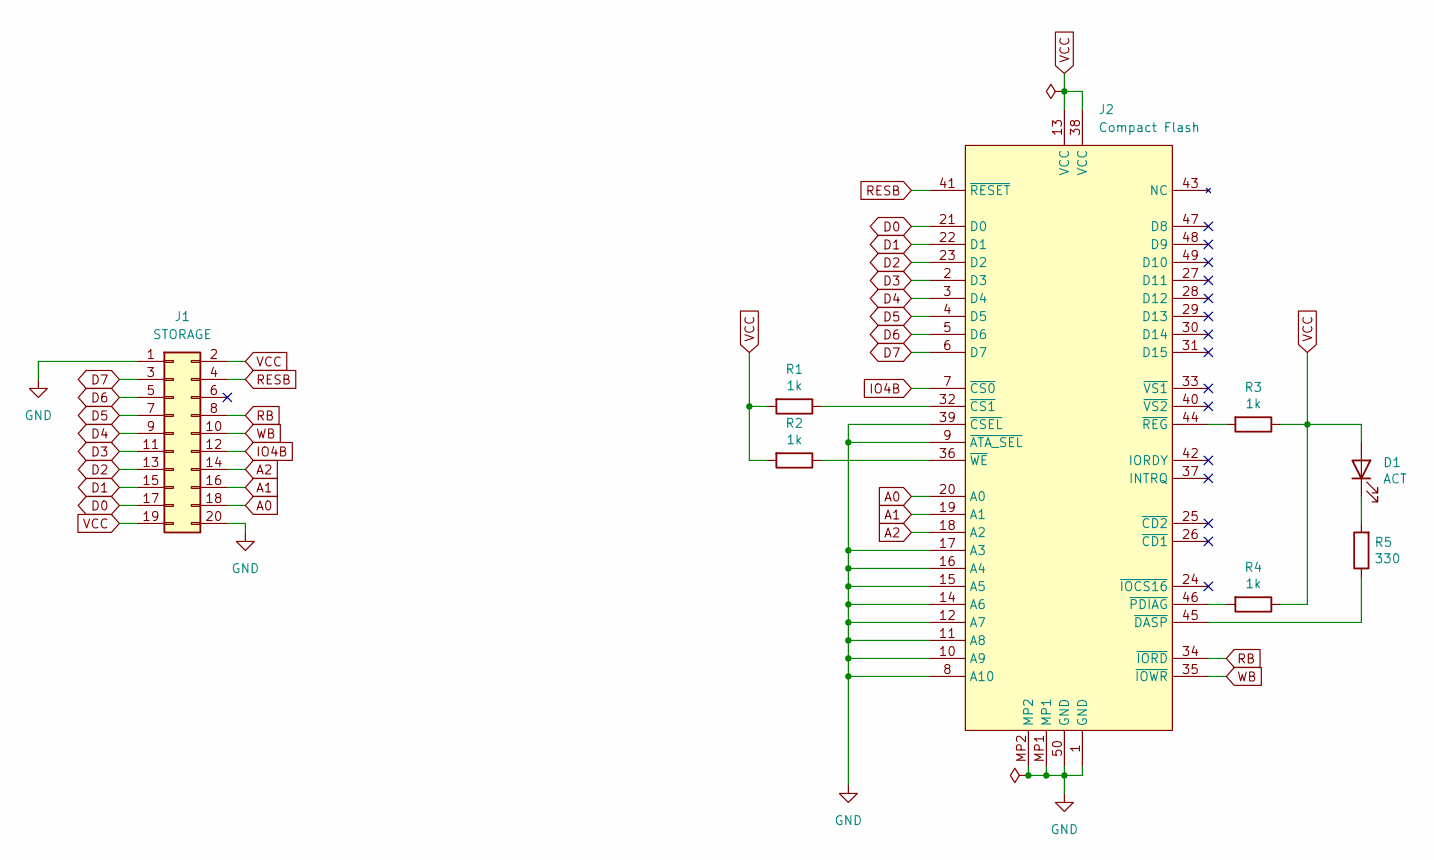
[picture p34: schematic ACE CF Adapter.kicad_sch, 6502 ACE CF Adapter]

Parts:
D1: ACT; LED_D3.0mm
J1: STORAGE; PinHeader_2x10_P2.54mm_Horizontal
J2: Compact Flash; 101DTAABR01; Digikey 4827-101D-TAAB-R01-ND
R1, R2, R3, R4: 1k; R_Axial_DIN0204_L3.6mm_D1.6mm_P5.08mm_Horizontal
R5: 330; R_Axial_DIN0204_L3.6mm_D1.6mm_P5.08mm_Horizontal

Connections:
A0: J1.18, J2.20 (A0)
A1: J1.16, J2.19 (A1)
A2: J1.14, J2.18 (A2)
D0: J1.17, J2.21 (D0)
D1: J1.15, J2.22 (D1)
D2: J1.13, J2.23 (D2)
D3: J1.11, J2.2 (D3)
D4: J1.9, J2.3 (D4)
D5: J1.7, J2.4 (D5)
D6: J1.5, J2.5 (D6)
D7: J1.3, J2.6 (D7)
GND: J1.1, J1.20, J2.1 (GND), J2.8 (A10), J2.9 (~ATA_SEL), J2.10 (A9), J2.11 (A8), J2.12 (A7), J2.14 (A6), J2.15 (A5), J2.16 (A4), J2.17 (A3), J2.39 (~CSEL), J2.50 (GND), J2.MP1, J2.MP2
IO4B: J1.12, J2.7 (~CS0)
unnamed: D1.1 (K), R5.2
unnamed: J2.32 (~CS1), R1.1
unnamed: J2.45 (~DASP), R5.1
unnamed: J2.46 (~PDIAG), R4.2
unnamed: J2.44 (~REG), R3.2
unnamed: J2.36 (~WE), R2.1
RB: J1.8, J2.34 (~IORD)
RESB: J1.4, J2.41 (~RESET)
VCC: D1.2 (A), J1.2, J1.19, J2.13 (VCC), J2.38 (VCC), R1.2, R2.2, R3.1, R4.1
WB: J1.10, J2.35 (~IOWR)

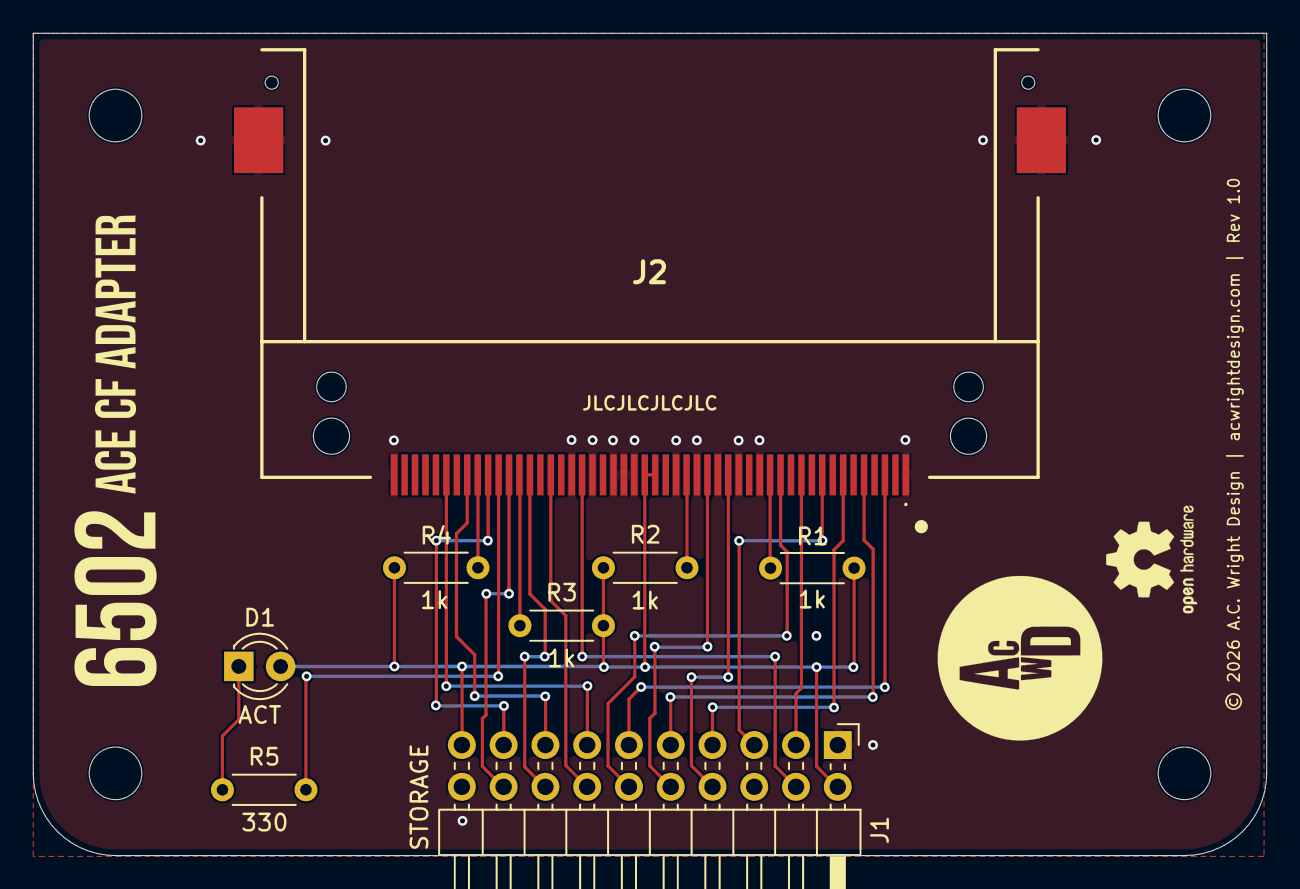
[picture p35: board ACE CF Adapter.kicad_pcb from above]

Board: 2 copper layers, 75.0 x 50.0 mm, 8 parts (0 on the bottom side), 23 nets.

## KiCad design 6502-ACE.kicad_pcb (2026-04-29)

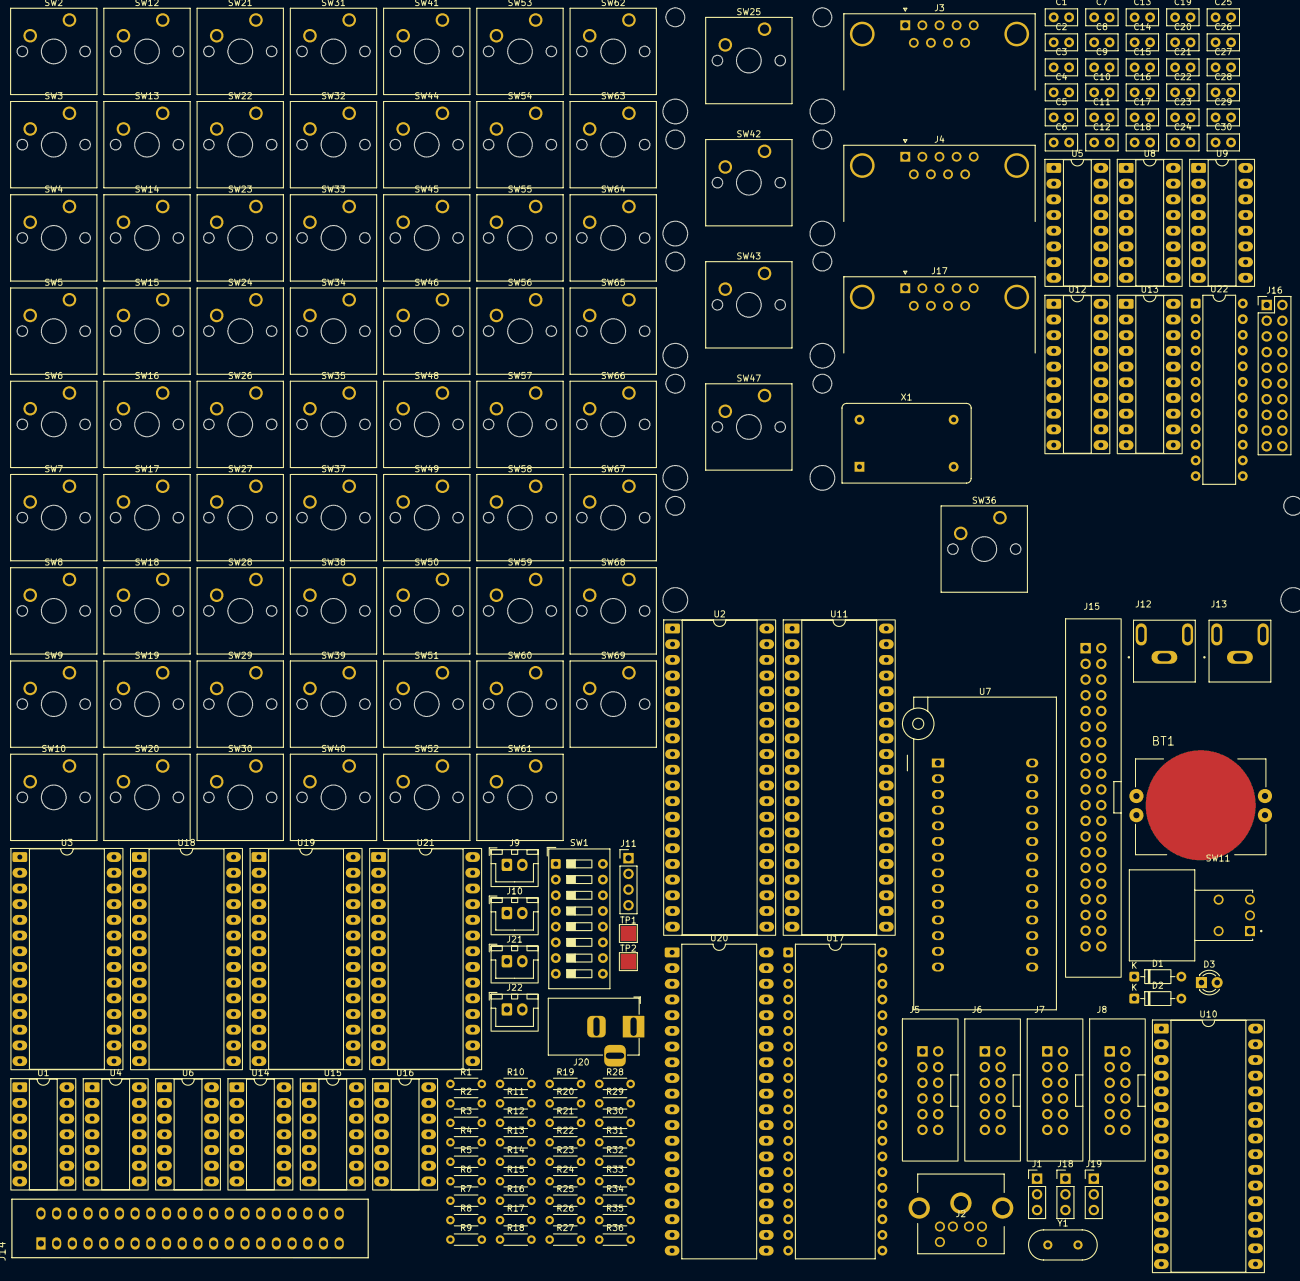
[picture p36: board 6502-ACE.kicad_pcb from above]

Board: 2 copper layers, 187 parts (0 on the bottom side), 152 nets, no tracks yet.

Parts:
BT1: BAT-HLD-001-THM; BAT_BAT-HLD-001-THM
C1, C9, C10, C11, C12, C13, C14, C15, C16, C17, C18, C19, C20, C21, C22, C23, C24, C25, C26, C27, C28, C29, C30: 100nF; C_Disc_D5.0mm_W2.5mm_P2.50mm
C2, C5, C6, C7, C8: 1uF; C_Disc_D5.0mm_W2.5mm_P2.50mm
C3, C4: 2.2nF; C_Disc_D5.0mm_W2.5mm_P2.50mm
D1, D2: BAT85; D_DO-35_SOD27_P7.62mm_Horizontal
D3: POWER LED; LED_D3.0mm
J1: PHI2 Select; PinHeader_1x03_P2.54mm_Vertical
J2: PS/2; KMDGX-6S-BS
J3: JOYSTICK A; DSUB-9_Pins_Horizontal_P2.77x2.84mm_EdgePinOffset7.70mm_Hou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
J4: JOYSTICK B; DSUB-9_Pins_Horizontal_P2.77x2.84mm_EdgePinOffset7.70mm_Hou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
J5, J6: PORT B; 6502 GPIO Connector
J7, J8: PORT A; 6502 GPIO Connector
J9: RESET SW; JST_XH_B2B-XH-A_1x02_P2.50mm_Vertical
J10: AUDIO; JST_XH_B2B-XH-A_1x02_P2.50mm_Vertical
J11: PADDLES; PinHeader_1x04_P2.54mm_Vertical
J12: AUDIO L; SWITCHCRAFT_PJRAN1X1U0XX
J13: AUDIO R; SWITCHCRAFT_PJRAN1X1U0XX
J14: CART; RHDR40W82P485X254_2X20_5740X93
J15: BUS; 6502 Bus Connector
J16: STORAGE; PinHeader_2x10_P2.54mm_Vertical
J17: DB9 MALE (DTE); DSUB-9_Pins_Horizontal_P2.77x2.84mm_EdgePinOffset7.70mm_Hou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
J18: CTS EN; PinHeader_1x03_P2.54mm_Vertical
J19: DCD EN; PinHeader_1x03_P2.54mm_Vertical
J20: 5V DC; BarrelJack_Horizontal
J21: VCC; JST_XH_B2B-XH-A_1x02_P2.50mm_Vertical
J22: POWER LED; JST_XH_B2B-XH-A_1x02_P2.50mm_Vertical
R1, R2, R3, R5, R7, R9, R11, R32, R34, R35: 1k; R_Axial_DIN0204_L3.6mm_D1.6mm_P5.08mm_Horizontal
R4, R6, R8, R10, R12, R13, R14, R15, R16, R17, R18, R19, R20, R21, R22, R23, R24, R25, R26, R27, R28, R29, R30, R31, R33: 1K; R_Axial_DIN0204_L3.6mm_D1.6mm_P5.08mm_Horizontal
R36: 330; R_Axial_DIN0204_L3.6mm_D1.6mm_P5.08mm_Horizontal
SW1: IO ENABLE; SW_DIP_SPSTx08_Slide_9.78x22.5mm_W7.62mm_P2.54mm
SW2: `; SW_Cherry_MX_1.00u_PCB
SW3: 8; SW_Cherry_MX_1.00u_PCB
SW4: Q; SW_Cherry_MX_1.00u_PCB
SW5: O; SW_Cherry_MX_1.00u_PCB
SW6: S; SW_Cherry_MX_1.00u_PCB
SW7: ;; SW_Cherry_MX_1.00u_PCB
SW8: V; SW_Cherry_MX_1.00u_PCB
SW9: CTRL; SW_Cherry_MX_1.25u_PCB
SW10: R CTRL; SW_Cherry_MX_1.25u_PCB
SW11: POWER; SW_400MSP1R6BLKM6QE
SW12: 1; SW_Cherry_MX_1.00u_PCB
SW13: 9; SW_Cherry_MX_1.00u_PCB
SW14: W; SW_Cherry_MX_1.00u_PCB
SW15: P; SW_Cherry_MX_1.00u_PCB
SW16: D; SW_Cherry_MX_1.00u_PCB
SW17: '; SW_Cherry_MX_1.00u_PCB
SW18: B; SW_Cherry_MX_1.00u_PCB
SW19: MENU; SW_Cherry_MX_1.00u_PCB
SW20: 2; SW_Cherry_MX_1.00u_PCB
SW21: 0; SW_Cherry_MX_1.00u_PCB
SW22: E; SW_Cherry_MX_1.00u_PCB
SW23: [; SW_Cherry_MX_1.00u_PCB
SW24: F; SW_Cherry_MX_1.00u_PCB
SW25: ENTER; SW_Cherry_MX_2.25u_PCB
SW26: N; SW_Cherry_MX_1.00u_PCB
SW27: ALT; SW_Cherry_MX_1.25u_PCB
SW28: R ALT; SW_Cherry_MX_1.25u_PCB
SW29: 3; SW_Cherry_MX_1.00u_PCB
SW30: -; SW_Cherry_MX_1.00u_PCB
SW31: R; SW_Cherry_MX_1.00u_PCB
SW32: ]; SW_Cherry_MX_1.00u_PCB
SW33: G; SW_Cherry_MX_1.00u_PCB
SW34: DELETE; SW_Cherry_MX_1.00u_PCB
SW35: M; SW_Cherry_MX_1.00u_PCB
SW36: SPACE; SW_Cherry_MX_6.25u_PCB
SW37: 4; SW_Cherry_MX_1.00u_PCB
SW38: =; SW_Cherry_MX_1.00u_PCB
SW39: T; SW_Cherry_MX_1.00u_PCB
SW40: \; SW_Cherry_MX_1.50u_PCB
SW41: H; SW_Cherry_MX_1.00u_PCB
SW42: SHIFT; SW_Cherry_MX_2.25u_PCB
SW43: R SHIFT; SW_Cherry_MX_2.25u_PCB
SW44: ,; SW_Cherry_MX_1.00u_PCB
SW45: FN; SW_Cherry_MX_1.25u_PCB
SW46: 5; SW_Cherry_MX_1.00u_PCB
SW47: BACKSPACE; SW_Cherry_MX_2.00u_PCB
SW48: Y; SW_Cherry_MX_1.00u_PCB
SW49: INSERT; SW_Cherry_MX_1.00u_PCB
SW50: J; SW_Cherry_MX_1.00u_PCB
SW51: Z; SW_Cherry_MX_1.00u_PCB
SW52: .; SW_Cherry_MX_1.00u_PCB
SW53: LEFT ARROW; SW_Cherry_MX_1.00u_PCB
SW54: 6; SW_Cherry_MX_1.00u_PCB
SW55: ESCAPE; SW_Cherry_MX_1.00u_PCB
SW56: U; SW_Cherry_MX_1.00u_PCB
SW57: CAPS LOCK; SW_Cherry_MX_1.75u_PCB
SW58: K; SW_Cherry_MX_1.00u_PCB
SW59: X; SW_Cherry_MX_1.00u_PCB
SW60: /; SW_Cherry_MX_1.00u_PCB
SW61: DOWN ARROW; SW_Cherry_MX_1.00u_PCB
SW62: 7; SW_Cherry_MX_1.00u_PCB
SW63: TAB; SW_Cherry_MX_1.50u_PCB
SW64: I; SW_Cherry_MX_1.00u_PCB
SW65: A; SW_Cherry_MX_1.00u_PCB
SW66: L; SW_Cherry_MX_1.00u_PCB
SW67: C; SW_Cherry_MX_1.00u_PCB
SW68: UP ARROW; SW_Cherry_MX_1.00u_PCB
SW69: RIGHT ARROW; SW_Cherry_MX_1.00u_PCB
TP1: GND; TestPoint_Pad_2.5x2.5mm
TP2: VCC; TestPoint_Pad_2.5x2.5mm
U1, U4, U6, U14, U16: 74HC00; DIP-14_W7.62mm_Socket_LongPads
U2: 65C02; DIP-40_W15.24mm_Socket_LongPads
U3: AS6C62256; DIP-28_W15.24mm_Socket_LongPads
U5, U8: 74HC138; DIP-16_W7.62mm_Socket_LongPads
U7: AT28C256; DIP_Socket-28_W11.9mm_W12.7mm_W15.24mm_W17.78mm_W18.5mm_3M_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
U9: 74HC163; DIP-16_W7.62mm_Socket_LongPads
U10: AS6C4008; DIP-32_W15.24mm_Socket_LongPads
U11: 65C22; DIP-40_W15.24mm_Socket_LongPads
U12, U13: 74HC573; DIP-20_W7.62mm_Socket_LongPads
U15: 74HC30; DIP-14_W7.62mm_Socket_LongPads
U17: ATmega1284-P; DIP-40_W15.24mm
U18: DS1511Y; DIP-28_W15.24mm_Socket_LongPads
U19: 6581; DIP-28_W15.24mm_Socket_LongPads
U20: Pico9918A; DIP-40_W15.24mm_LongPads
U21: 65C51; DIP-28_W15.24mm_Socket_LongPads
U22: MAX238xNG+; DIP-24_W7.62mm
X1: OCXO-14; Oscillator_DIP-14
Y1: 1.8432 Mhz; Crystal_HC49-U_Vertical

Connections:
/$8C00: SW1.4, U5.12 (~Y3)
/$9C00: SW1.8, U5.7 (~Y7)
/$8000: SW1.1, U5.15 (~Y0)
/$8400: SW1.2, U5.14 (~Y1)
/$8800: SW1.3, U5.13 (~Y2)
/$9000: SW1.5, U5.11 (~Y4)
/$9400: SW1.6, U5.10 (~Y5)
/$9800: SW1.7, U5.9 (~Y6)
A0: J14.38, J15.38, J16.18, U2.9 (A0), U3.10 (A0), U7.10 (A0), U10.12 (A0), U11.38 (RS0), U15.12, U18.10 (A0), U19.9 (A0), U20.13 (MODE0), U21.13 (RS0)
A1: J14.36, J15.36, J16.16, U2.10 (A1), U3.9 (A1), U7.9 (A1), U10.11 (A1), U11.37 (RS1), U15.11, U18.9 (A1), U19.10 (A1), U20.11 (MODE1), U21.14 (RS1)
A2: J14.34, J15.34, J16.14, U2.11 (A2), U3.8 (A2), U7.8 (A2), U10.10 (A2), U11.36 (RS2), U15.6, U18.8 (A2), U19.11 (A2)
A3: J14.32, J15.32, U2.12 (A3), U3.7 (A3), U7.7 (A3), U10.9 (A3), U11.35 (RS3), U15.5, U18.7 (A3), U19.12 (A3)
A4: J14.30, J15.30, U2.13 (A4), U3.6 (A4), U7.6 (A4), U10.8 (A4), U15.4, U18.6 (A4), U19.13 (A4)
A5: J14.28, J15.28, U2.14 (A5), U3.5 (A5), U7.5 (A5), U10.7 (A5), U15.3
A6: J14.26, J15.26, U2.15 (A6), U3.4 (A6), U7.4 (A6), U10.6 (A6), U15.2
A7: J14.24, J15.24, U2.16 (A7), U3.3 (A7), U7.3 (A7), U10.5 (A7), U15.1
A8: J14.22, J15.22, U2.17 (A8), U3.25 (A8), U7.25 (A8), U10.27 (A8), U14.2
A9: J14.20, J15.20, U2.18 (A9), U3.24 (A9), U7.24 (A9), U10.26 (A9), U14.1
A10: J14.18, J15.18, U2.19 (A10), U3.21 (A10), U5.1 (A0), U7.21 (A10)
A11: J14.16, J15.16, U2.20 (A11), U3.23 (A11), U5.2 (A1), U7.23 (A11)
A12: J14.14, J15.14, U2.22 (A12), U3.2 (A12), U5.3 (A2), U7.2 (A12)
A13: J14.12, J15.12, U1.5, U2.23 (A13), U3.26 (A13), U5.4 (~E0), U7.26 (A13)
A14: J14.10, J15.10, U1.1, U1.2, U2.24 (A14), U3.1 (A14), U5.5 (~E1), U6.2, U7.1 (A14)
A15: J14.8, J15.8, U1.12, U2.25 (A15), U3.20 (~CE), U5.6 (E2), U6.9
B10: U10.23 (A10), U12.19 (Q0), U13.19 (Q0)
B11: U10.25 (A11), U12.18 (Q1), U13.18 (Q1)
B12: U10.4 (A12), U12.17 (Q2), U13.17 (Q2)
B13: U10.28 (A13), U12.16 (Q3), U13.16 (Q3)
B14: U10.3 (A14), U12.15 (Q4), U13.15 (Q4)
B15: U10.31 (A15), U12.14 (Q5), U13.14 (Q5)
B16: U10.2 (A16), U12.13 (Q6), U13.13 (Q6)
B17: U10.30 (A17), U12.12 (Q7), U13.12 (Q7)
B18: U10.1 (A18), U14.11, U16.5
BE: J14.11, J15.11, R3.1, U2.36 (BE)
CA1: J7.11, J8.11, U11.40 (CA1), U17.14 (PD0)
CA2: J7.12, J8.12, U11.39 (CA2), U17.15 (PD1)
CB1: J5.11, J6.11, U11.18 (CB1), U17.18 (PD4)
CB2: J5.12, J6.12, U11.19 (CB2), U17.19 (PD5)
CSRB: U8.14 (~Y1), U20.15 (~CSR)
CSWB: U8.15 (~Y0), U20.14 (~CSW)
CTS: J17.8, U22.3 (R2IN)
CTSIN: J18.3, U22.4 (R2OUT)
D0: J14.37, J15.37, J16.17, U2.33 (D0), U3.11 (DQ0), U7.11 (I/O0), U10.13 (DQ0), U11.33 (D0), U12.9 (D7), U13.9 (D7), U18.11 (D0), U19.15 (D0), U20.17 (CD7), U21.18 (D0)
D1: J14.35, J15.35, J16.15, U2.32 (D1), U3.12 (DQ1), U7.12 (I/O1), U10.14 (DQ1), U11.32 (D1), U12.8 (D6), U13.8 (D6), U18.12 (D1), U19.16 (D1), U20.18 (CD6), U21.19 (D1)
D2: J14.33, J15.33, J16.13, U2.31 (D2), U3.13 (DQ2), U7.13 (I/O2), U10.15 (DQ2), U11.31 (D2), U12.7 (D5), U13.7 (D5), U18.13 (D2), U19.17 (D2), U20.19 (CD5), U21.20 (D2)
D3: J14.31, J15.31, J16.11, U2.30 (D3), U3.15 (DQ3), U7.15 (I/O3), U10.17 (DQ3), U11.30 (D3), U12.6 (D4), U13.6 (D4), U18.15 (D3), U19.18 (D3), U20.20 (CD4), U21.21 (D3)
D4: J14.29, J15.29, J16.9, U2.29 (D4), U3.16 (DQ4), U7.16 (I/O4), U10.18 (DQ4), U11.29 (D4), U12.5 (D3), U13.5 (D3), U18.16 (D4), U19.19 (D4), U20.21 (CD3), U21.22 (D4)
D5: J14.27, J15.27, J16.7, U2.28 (D5), U3.17 (DQ5), U7.17 (I/O5), U10.19 (DQ5), U11.28 (D5), U12.4 (D2), U13.4 (D2), U18.17 (D5), U19.20 (D5), U20.22 (CD2), U21.23 (D5)
D6: J14.25, J15.25, J16.5, U2.27 (D6), U3.18 (DQ6), U7.18 (I/O6), U10.20 (DQ6), U11.27 (D6), U12.3 (D1), U13.3 (D1), U18.18 (D6), U19.21 (D6), U20.23 (CD1), U21.24 (D6)
D7: J14.23, J15.23, J16.3, U2.26 (D7), U3.19 (DQ7), U7.19 (I/O7), U10.21 (DQ7), U11.26 (D7), U12.2 (D0), U13.2 (D0), U18.19 (D7), U19.22 (D7), U20.24 (CD0), U21.25 (D7)
DCD: J17.1, U22.16 (R2IN)
DCDIN: J19.3, U22.17 (R2OUT)
DSR: J17.6, U22.23 (R1IN)
DSRIN: U21.17 (DSRB), U22.22 (R1OUT)
DTR: J17.4, U22.24 (T1OUT)
DTROUT: U21.11 (DTRB), U22.19 (T1IN)
EXP2: J14.21, J15.21
EXP3: J14.19, J15.19
GND: C1.1, C7.2, C8.2, C9.2, C10.2, C11.2, C12.2, C13.2, C14.2, C15.2, C16.2, C17.2, C18.2, C19.2, C20.2, C21.2, C22.2, C23.2, C24.2, C25.2, C26.2, C27.2, C28.2, C29.2, C30.2, J2.3, J3.8, J3.SH (PAD), J4.8, J4.SH (PAD), J5.2, J6.2, J7.2, J8.2, J9.2, J10.2, J11.1, J12.2 (Ext), J13.2 (Ext), J14.1, J14.40, J15.1, J15.40, J16.1, J16.20, J17.5, J17.SH (PAD), J18.1, J19.1, J20.2, J20.3, J21.2, R34.2, R36.2, TP1.1 (1_1), U1.7 (GND), U2.21 (VSS), U3.14 (GND), U4.7 (GND), U5.8 (GND), U6.7 (GND), U7.14 (GND), U8.3 (A2), U8.4 (~E0), U8.5 (~E1), U8.8 (GND), U9.8 (GND), U10.16 (GND), U11.1 (VSS), U12.10 (GND), U13.10 (GND), U14.7 (GND), U15.7 (GND), U16.7 (GND), U17.11 (GND), U17.31 (GND), U18.14 (GND), U19.14 (GND), U20.12 (VSS), U21.1 (GND), U22.8 (GND), X1.7 (GND)
HRDB: J14.4, J14.6, J15.4, J15.6, R1.2, U6.1
IO1B: D1.1 (K), R4.1, SW1.16, U12.1 (OE), U14.9, U14.10
IO2B: D2.1 (K), R6.1, SW1.15, U13.1 (OE), U14.12, U14.13
IO3B: R8.1, SW1.14, U18.20 (~CE)
IO4B: J16.12, R10.1, SW1.13
IO5B: R12.1, SW1.12, U21.3 (CS1B)
IO6B: R13.1, SW1.11, U11.23 (CS2B)
IO7B: R14.1, SW1.10, U19.8 (~CS)
IO8B: R15.1, SW1.9, U8.2 (A1)
IRQB: J14.5, J15.5, R7.1, U2.4 (IRQB), U11.21 (IRQB), U17.28 (PC6), U18.5 (IRQB), U20.16 (~INT), U21.26 (IRQB)
LOADH: U13.11 (Load), U16.11
LOADL: U12.11 (Load), U16.8
NMIB: J14.7, J15.7, R5.1, U2.6 (NMIB), U17.29 (PC7)
unnamed: R35.2, U18.26 (VBAUX)
unnamed: D1.2 (A), D2.2 (A), R32.2, U10.22 (~CE)
unnamed: D3.1 (K), J22.2, R36.1
unnamed: J9.1, U17.22 (PC0)
unnamed: C2.2, J10.1, J12.1 (In), J13.1 (In)
unnamed: J11.2, U19.23 (POTY)
unnamed: J11.3, U19.24 (POTX)
unnamed: J18.2, U21.9 (CTSB)
unnamed: J19.2, U21.16 (DCDB)
unnamed: J20.1, SW11.2 (B)
unnamed: U1.3, U1.4
unnamed: U1.6, U1.9, U1.10
unnamed: U1.11, U6.13
unnamed: U1.8, U1.13
unnamed: U4.1, U4.2, U6.11
unnamed: U4.6, U4.13
unnamed: U6.3, U6.4, U6.5
unnamed: U6.6, U6.10
unnamed: U6.8, U6.12
unnamed: R11.1, U7.27 (~WE)
unnamed: U14.3, U14.4
unnamed: U14.5, U15.8
unnamed: U14.6, U16.1, U16.4
unnamed: U14.8, U16.2
unnamed: U16.3, U16.9
unnamed: U16.6, U16.12
unnamed: C1.2, U17.32 (AREF)
unnamed: R33.2, U17.9 (~RESET)
unnamed: R35.1, U18.24 (KSB)
unnamed: C3.2, U19.1 (CAP1A)
unnamed: C3.1, U19.2 (CAP1B)
unnamed: C4.2, U19.3 (CAP2A)
unnamed: C4.1, U19.4 (CAP2B)
unnamed: C2.1, R34.1, U19.27 (OUT)
unnamed: U21.6 (XTALI), Y1.1
unnamed: U21.7 (XTALO), Y1.2
unnamed: C5.1, U22.10 (C1+)
unnamed: C5.2, U22.12 (C1-)
unnamed: C6.1, U22.13 (C2+)
unnamed: C6.2, U22.14 (C2-)
unnamed: C7.1, U22.11 (VS+)
unnamed: C8.1, U22.15 (VS-)
PA0: J3.6, J7.4, J8.4, R16.1, SW2.1, SW12.1, SW20.1, SW29.1, SW37.1, SW46.1, SW54.1, SW62.1, U11.2 (PA0), U17.40 (PA0)
PA1: J3.7, J7.6, J8.6, R18.1, SW3.1, SW13.1, SW21.1, SW30.1, SW38.1, SW47.1, SW55.1, SW63.1, U11.3 (PA1), U17.39 (PA1)
PA2: J3.9, J7.8, J8.8, R20.1, SW4.1, SW14.1, SW22.1, SW31.1, SW39.1, SW48.1, SW56.1, SW64.1, U11.4 (PA2), U17.38 (PA2)
PA3: J3.5, J7.10, J8.10, R22.1, SW5.1, SW15.1, SW23.1, SW32.1, SW40.1, SW49.1, SW57.1, SW65.1, U11.5 (PA3), U17.37 (PA3)
PA4: J3.1, J7.9, J8.9, R24.1, SW6.1, SW16.1, SW24.1, SW33.1, SW41.1, SW50.1, SW58.1, SW66.1, U11.6 (PA4), U17.36 (PA4)
PA5: J3.2, J7.7, J8.7, R26.1, SW7.1, SW17.1, SW25.1, SW34.1, SW42.1, SW43.1, SW51.1, SW59.1, SW67.1, U11.7 (PA5), U17.35 (PA5)
PA6: J3.3, J7.5, J8.5, R28.1, SW8.1, SW18.1, SW26.1, SW35.1, SW44.1, SW52.1, SW60.1, SW68.1, U11.8 (PA6), U17.34 (PA6)
PA7: J3.4, J7.3, J8.3, R30.1, SW9.1, SW10.1, SW19.1, SW27.1, SW28.1, SW36.1, SW45.1, SW53.1, SW61.1, SW69.1, U11.9 (PA7), U17.33 (PA7)
PB0: J4.6, J5.4, J6.4, R17.1, SW2.2, SW3.2, SW4.2, SW5.2, SW6.2, SW7.2, SW8.2, SW9.2, SW10.2, U11.10 (PB0), U17.1 (PB0)
PB1: J4.7, J5.6, J6.6, R19.1, SW12.2, SW13.2, SW14.2, SW15.2, SW16.2, SW17.2, SW18.2, SW19.2, U11.11 (PB1), U17.2 (PB1)
PB2: J4.9, J5.8, J6.8, R21.1, SW20.2, SW21.2, SW22.2, SW23.2, SW24.2, SW25.2, SW26.2, SW27.2, SW28.2, U11.12 (PB2), U17.3 (PB2)
PB3: J4.5, J5.10, J6.10, R23.1, SW29.2, SW30.2, SW31.2, SW32.2, SW33.2, SW34.2, SW35.2, SW36.2, U11.13 (PB3), U17.4 (PB3)
PB4: J4.1, J5.9, J6.9, R25.1, SW37.2, SW38.2, SW39.2, SW40.2, SW41.2, SW42.2, SW43.2, SW44.2, SW45.2, U11.14 (PB4), U17.5 (PB4)
PB5: J4.2, J5.7, J6.7, R27.1, SW46.2, SW47.2, SW48.2, SW49.2, SW50.2, SW51.2, SW52.2, SW53.2, U11.15 (PB5), U17.6 (PB5)
PB6: J4.3, J5.5, J6.5, R29.1, SW54.2, SW55.2, SW56.2, SW57.2, SW58.2, SW59.2, SW60.2, SW61.2, U11.16 (PB6), U17.7 (PB6)
PB7: J4.4, J5.3, J6.3, R31.1, SW62.2, SW63.2, SW64.2, SW65.2, SW66.2, SW67.2, SW68.2, SW69.2, U11.17 (PB7), U17.8 (PB7)
PHI2: J1.2, J14.17, J15.17, U2.37 (PHI2), U4.10, U4.12, U8.6 (E2), U11.25 (PHI2), U21.27 (PHI2)
PHI2_1MHZ: J1.1, U9.11 (Q3), U19.6 (PHI2)
PHI2_2MHZ: J1.3, U9.12 (Q2)
PHI2_16MHZ: U9.2 (CP), U17.13 (XTAL1), X1.8 (OUT)
PS2CLK: J2.5, U17.16 (PD2)
PS2DATA: J2.1, U17.17 (PD3)
RB: J16.8, U3.22 (~OE), U4.8, U7.22 (~OE), U10.24 (~OE), U18.22 (~OE)
RDY: J14.9, J15.9, R9.1, U2.2 (RDY)
REB: U4.3, U7.20 (~CE)
RESB: J14.3, J15.3, J16.4, U2.40 (RESB), U11.34 (RESB), U17.21 (PD7), U18.4 (RSTB), U19.5 (~RESET), U20.34 (~RESET/SYNC), U21.4 (RESB)
RTS: J17.7, U22.1 (T2OUT)
RTSOUT: U21.8 (RTSB), U22.18 (T2IN)
RWB: J14.13, J15.13, J16.6, U2.34 (RWB), U4.4, U4.5, U4.9, U8.1 (A0), U11.22 (RWB), U19.7 (R/~W), U21.28 (RWB)
RXD: J17.2, U22.7 (R1IN)
RXDIN: U21.12 (RXD), U22.6 (R1OUT)
SOB: R2.1, U2.38 (SOB)
SQW: U17.20 (PD6), U18.23 (SQW)
SYNC: J14.15, J15.15, U2.7 (SYNC)
TXD: J17.3, U22.2 (T1OUT)
TXDOUT: U21.10 (TXD), U22.5 (T1IN)
VCC: C9.1, C10.1, C11.1, C12.1, C13.1, C14.1, C15.1, C16.1, C17.1, C18.1, C19.1, C20.1, C21.1, C22.1, C23.1, C24.1, C25.1, C26.1, C27.1, C28.1, C29.1, C30.1, D3.2 (A), J2.4, J5.1, J6.1, J7.1, J8.1, J11.4, J14.2, J14.39, J15.2, J15.39, J16.2, J16.19, J21.1, J22.1, R1.1, R2.2, R3.2, R4.2, R5.2, R6.2, R7.2, R8.2, R9.2, R10.2, R11.2, R12.2, R13.2, R14.2, R15.2, R16.2, R17.2, R18.2, R19.2, R20.2, R21.2, R22.2, R23.2, R24.2, R25.2, R26.2, R27.2, R28.2, R29.2, R30.2, R31.2, R32.1, R33.1, SW11.1 (A), TP2.1 (1_1), U1.14 (VCC), U2.8 (VDD), U3.28 (VCC), U4.14 (VCC), U5.16 (VCC), U6.14 (VCC), U7.28 (VCC), U8.16 (VCC), U9.1 (~MR), U9.3 (D0), U9.4 (D1), U9.5 (D2), U9.6 (D3), U9.7 (CEP), U9.9 (~PE), U9.10 (CET), U9.16 (VCC), U10.32 (VCC), U11.20 (VDD), U11.24 (CS1), U12.20 (VCC), U13.20 (VCC), U14.14 (VCC), U15.14 (VCC), U16.14 (VCC), U17.10 (VCC), U17.30 (AVCC), U18.28 (VCC), U19.25 (VCC), U20.33 (VCC), U21.2 (CS0), U21.15 (VCC), U22.9 (VCC), X1.14 (Vcc)
WB: J16.10, U3.27 (~WE), U4.11, U10.29 (~WE), U16.10, U16.13, U18.27 (~WE)

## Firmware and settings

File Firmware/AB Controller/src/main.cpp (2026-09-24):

#define CIRCULAR_BUFFER_INT_SAFE

#include <Arduino.h>
#include <CircularBuffer.hpp>

// ============================================================================
// Keyboard Matrix Mapping 
// ============================================================================
// Rows: PA0-PA7 (VIA Port A)
// Columns: PB0-PB7 (VIA Port B)
//
//      PB0    PB1    PB2    PB3    PB4    PB5    PB6    PB7
// PA0:  `      1      2      3      4      5      6      7
// PA1:  8      9      0      -      =      BS     ESC    TAB
// PA2:  q      w      e      r      t      y      u      i
// PA3:  o      p      [      ]      \      INS    CAPS   a
// PA4:  s      d      f      g      h      j      k      l
// PA5:  ;      '      ENTER  DEL    SHIFT  z      x      c
// PA6:  v      b      n      m      ,      .      /      UP
// PA7:  CTRL   GUI    ALT    SPACE  FN     LEFT   DOWN   RIGHT
//
// Notes:
// - BS = Backspace (0x08), ESC = Escape (0x1B), TAB (0x09)
// - INS = Insert (0x1A), DEL = Delete (0x7F), ENTER (0x0D)
// - Arrow keys: UP (0x1E), LEFT (0x1C), DOWN (0x1F), RIGHT (0x1D)
// - Function keys F1-F10 are mapped as FN + number keys 1-0
// ============================================================================

// ATMega1284 PORT A / 6522 VIA PORT A
#define VIA_PA0 24
#define VIA_PA1 25
#define VIA_PA2 26
#define VIA_PA3 27
#define VIA_PA4 28
#define VIA_PA5 29
#define VIA_PA6 30
#define VIA_PA7 31

// ATMega1284 PORT B / 6522 VIA PORT B
#define VIA_PB0 0
#define VIA_PB1 1
#define VIA_PB2 2
#define VIA_PB3 3
#define VIA_PB4 4
#define VIA_PB5 5
#define VIA_PB6 6
#define VIA_PB7 7

#define VIA_CA1 8
#define VIA_CA2 9
#define PS2CLK  10
#define PS2DATA 11
#define VIA_CB1 12
#define VIA_CB2 13

// 6502 system control (MightyCore "standard" pinout)
#define RESET_BTN 16   // PC0 - reset button (N.O., active low, internal pullup)
#define RESB      23   // PC7 - 6502 RESB, open-drain (active low; see assertRESB)
#define RTC_SQW   14   // PD6 - square-wave input from DS1511Y RTC
#define NMIB      15   // PD7 - 6502 NMIB output (active low)

// Power-on reset / reset button timing
#define POR_HOLD_MS       250  // Hold 6502 in reset at power-on for stable supply/clock
#define RESET_DEBOUNCE_MS 20   // Reset button debounce interval

// ----------------------------------------------------------------------------
// RTC SQW -> 6502 NMI jiffy clock (OPTIONAL, DISABLED BY DEFAULT)
// ----------------------------------------------------------------------------
// SQW-driven NMI behavior is off unless you explicitly opt in by uncommenting
// the line below and rebuilding the firmware. While disabled, NMIB (PD7) is
// left as a high-impedance input and the line is held high by the physical
// pullup resistor on the PCB, so the 6502 never sees an NMI from this board.
//
// #define ENABLE_SQW

// Boot grace period before the RTC SQW jiffy interrupt is armed. The DS1511Y
// powers up with SQW in an undefined, battery-backed state that can default to
// a 32.768 kHz output (an NMI every ~30 us). If those NMIs hit the 6502 during
// the BIOS boot window (before NMI_PTR is initialized) the system hangs. We
// hold off arming PCINT3 until the 6502 has had time to boot and the BIOS has
// configured SQW, then enable it.
#define SQW_BOOT_GRACE_MS 500

// Jiffy clock: number of RTC SQW pulses per 6502 NMI tick
#define JIFFY_DIVIDER 1

#define BUFFER_SIZE 16

CircularBuffer<uint8_t, BUFFER_SIZE> ps2Buffer;  // Buffer for PS/2 keyboard data
CircularBuffer<uint8_t, BUFFER_SIZE> matrixBuffer;  // Buffer for matrix keyboard data

// PS/2 keyboard state
bool ps2Enabled = false;
bool shiftPressed = false;
bool ctrlPressed = false;
bool breakCodeNext = false;
bool extendedCodeNext = false;

// Matrix keyboard state
bool matrixEnabled = false;
bool matrixShiftPressed = false;
bool matrixCtrlPressed = false;

// Matrix key debouncing
uint8_t matrixKeyState[8][8] = {0};  // Current state of each key
uint8_t matrixKeyLast[8][8] = {0};   // Last state of each key
unsigned long matrixLastScan = 0;
uint8_t matrixScanRow = 0;   // Next row to scan; an interrupted sweep resumes here
#define MATRIX_SCAN_INTERVAL 10  // Scan every 10ms
#define MATRIX_DEBOUNCE_COUNT 2  // Key must be stable for 2 scans

// ============================================================================
// Joystick State
// ============================================================================
// The two sticks share the sixteen VIA port lines with the key matrix:
// JOYSTICK A on PA0-PA7 (the matrix rows) and JOYSTICK B on PB0-PB7 (the
// columns). Every signal is active low -- the switches close to ground -- so an
// untouched stick leaves its lines pulled high.
//
// Nothing about the sticks is sent to the 6502 from here. The 6502 reads them
// itself: Kernal KBDisable takes both encoders offline, this ATmega goes
// high-impedance, and the 6502 reads the raw ports with the sticks the only
// things pulling on them. That is the same arrangement a C64 has, it needs no
// wire protocol, and it is the only way both sticks can be read reliably --
// anything this encoder drives onto a port is fighting the switches wired to
// those same eight lines.
//
// What the firmware does need is to know which lines a stick is holding down.
// A held signal pins its line low for as long as it is held, and every key
// along that row or column then reads as pressed. These masks keep the sticks
// out of the matrix scan.
uint8_t joyRowMask = 0;   // PA lines JOYSTICK A is holding low -> unscannable rows
uint8_t joyColMask = 0;   // PB lines JOYSTICK B is holding low -> unscannable columns

#ifdef ENABLE_SQW
// Jiffy clock (RTC SQW) state
volatile uint16_t jiffyCount = 0;
bool sqwIntEnabled = false;            // Has PCINT3 (SQW) been armed yet?
unsigned long resbReleasedAt = 0;     // millis() when RESB was last released
#endif

void onInterrupt();
void handleReset();
void enablePS2();
void disablePS2();
void enableMatrix();
void disableMatrix();
void ps2ToAscii(uint8_t scancode);
bool scanMatrix();
uint8_t mapMatrixToAscii(uint8_t row, uint8_t col);
void serviceEncoderEnables();
bool settleBetweenCharacters();
bool matrixRowConflict();
bool writePortA(uint8_t value);
bool writePortB(uint8_t value);
void sampleJoystickMasks();

// ============================================================================
// VIA Port Access
// ============================================================================
// On the MightyCore "standard" pinout VIA_PA0-PA7 are D24-D31, which is exactly
// ATmega PORTA bits 0-7, and VIA_PB0-PB7 are D0-D7, which is exactly PORTB bits
// 0-7. Nothing else on this board lives on either register, so the whole port
// can be manipulated in a single instruction.
//
// That matters in two places. The encoder must let go of a port within 100 us
// of being asked, because that is how the 6502 reads the joysticks at all and
// Kernal KBDisable waits exactly that long before reading. So the release path
// has to be effectively instantaneous, and the scan loop has to be able to
// check for a release request without paying ~4 us per Arduino call.
// Everything that is not on that path keeps using pinMode/digitalRead.
//
// If the VIA_Px pin defines above ever change, these must change with them.

// CA2 (PD1) and CB2 (PD5) are the 6502 asking for a port back, active high.
#define CA2_RELEASE_REQUESTED() (PIND & _BV(PD1))
#define CB2_RELEASE_REQUESTED() (PIND & _BV(PD5))

// True when the 6502 has asked an encoder that is currently enabled -- and so
// currently driving a port -- to release it.
static inline bool releaseRequested() {
  return (matrixEnabled && CB2_RELEASE_REQUESTED()) ||
         (ps2Enabled && CA2_RELEASE_REQUESTED());
}

// ============================================================================
// Keyboard Matrix to ASCII Mapping Table
// ============================================================================
// Maps each matrix position [row][col] to its base ASCII code (no modifiers)
// Special values: 0xFF = no key, 0xFE = modifier key (handled separately)
const uint8_t matrixMap[8][8] PROGMEM = {
  // PA0/Row 0: PB0    PB1    PB2    PB3    PB4    PB5    PB6    PB7
  {             0x60,  0x31,  0x32,  0x33,  0x34,  0x35,  0x36,  0x37 },  // ` 1 2 3 4 5 6 7
  // PA1/Row 1
  {             0x38,  0x39,  0x30,  0x2D,  0x3D,  0x08,  0x1B,  0x09 },  // 8 9 0 - = BS ESC TAB
  // PA2/Row 2
  {             0x51,  0x57,  0x45,  0x52,  0x54,  0x59,  0x55,  0x49 },  // Q W E R T Y U I
  // PA3/Row 3
  {             0x4F,  0x50,  0x5B,  0x5D,  0x5C,  0x1A,  0xFF,  0x41 },  // O P [ ] \ INS (ign) A
  // PA4/Row 4
  {             0x53,  0x44,  0x46,  0x47,  0x48,  0x4A,  0x4B,  0x4C },  // S D F G H J K L
  // PA5/Row 5
  {             0x3B,  0x27,  0x0D,  0x7F,  0xFE,  0x5A,  0x58,  0x43 },  // ; ' ENTER DEL SHIFT Z X C
  // PA6/Row 6
  {             0x56,  0x42,  0x4E,  0x4D,  0x2C,  0x2E,  0x2F,  0x1E },  // V B N M , . / UP
  // PA7/Row 7
  {             0xFE,  0xFF,  0xFF,  0x20,  0xFF,  0x1C,  0x1F,  0x1D }   // CTRL (ign) (ign) SPACE (ign) LEFT DOWN RIGHT
};

// ============================================================================
// Jiffy Clock (RTC SQW -> 6502 NMI)
// ============================================================================
// The DS1511Y RTC drives a square wave into PD6 (RTC_SQW). Every JIFFY_DIVIDER
// rising edges we pulse NMIB (PD7) low to tick the 6502's jiffy clock. The NMI
// is generated directly in the ISR so its timing is independent of loop() load.
//
// NMIB is shared with the CART and BUS connectors, so PD7 drives it open-drain,
// like RESB: the PORTD latch for PD7 stays low (setup() leaves it there), and a
// pulse only switches the pin between output (low) and input (released, with
// the PCB's pull-up raising the line). PD7 never drives NMIB high, so a card can
// still raise its own NMI between pulses.
#ifdef ENABLE_SQW
ISR(PCINT3_vect) {
  static uint8_t lastSQW = 1;
  uint8_t cur = (PIND & _BV(PD6)) ? 1 : 0;

  if (cur && !lastSQW) {  // Rising edge of SQW
    if (++jiffyCount >= JIFFY_DIVIDER) {
      jiffyCount = 0;
      DDRD |= _BV(PD7);     // NMIB low (assert: output, latch already low)
      delayMicroseconds(5);
      DDRD &= ~_BV(PD7);    // NMIB released (input; the PCB pull-up raises it)
    }
  }
  lastSQW = cur;
}
#endif

// RESB is shared: the DS1511Y's open-drain RST output and the CART and BUS
// connectors can pull it low too. So PC7 only ever pulls it low, and never
// drives it high, or the ATmega would hold the 6502 out of a reset something
// else asked for.
//
// Assert: clear the output latch (which also turns the pull-up off), then
// make the pin an output, so it goes straight to low without a high glitch.
void assertRESB() {
  digitalWrite(RESB, LOW);
  pinMode(RESB, OUTPUT);
}

// Release: an input with the internal pull-up on. The pull-up (20-50k) raises
// RESB on a board without an external resistor; on a board with the 10k
// pull-up the two share the job. Either way an open-drain device can still
// pull the line low.
void releaseRESB() {
  pinMode(RESB, INPUT_PULLUP);
}

// Poll the reset button and drive RESB on the 6502. The button is N.O. and
// active low; while it is held (debounced) the 6502 is kept in reset.
void handleReset() {
  static bool resetActive = false;
  static int lastReading = HIGH;
  static unsigned long lastChange = 0;

  int reading = digitalRead(RESET_BTN);
  unsigned long now = millis();

  if (reading != lastReading) {
    lastReading = reading;
    lastChange = now;
  }

  if (now - lastChange >= RESET_DEBOUNCE_MS) {
    bool pressed = (reading == LOW);
    if (pressed && !resetActive) {
      resetActive = true;
      assertRESB();
#ifdef ENABLE_SQW
      // Disarm the SQW jiffy interrupt while the 6502 is held in reset so the
      // boot window after release is protected the same way as power-on.
      PCICR &= ~_BV(PCIE3);
      sqwIntEnabled = false;
#endif
    } else if (!pressed && resetActive) {
      resetActive = false;
      releaseRESB();
#ifdef ENABLE_SQW
      resbReleasedAt = millis(); // Restart the boot grace period
#endif
    }
  }
}

void setup() {
  // ---- 6502 system control ----
  // Assert reset immediately so the 6502 stays held while we initialize.
  assertRESB();
  pinMode(RESET_BTN, INPUT_PULLUP);

  // NMIB is released: a high-impedance input with its latch low, and the PCB
  // pull-up holds the line high. With SQW disabled it stays that way, so the
  // 6502 never receives an NMI from this board. With SQW enabled, the jiffy ISR
  // pulses it low by switching the pin to an output and back.
  pinMode(NMIB, INPUT);

#ifdef ENABLE_SQW
  // RTC square-wave input (DS1511Y SQW). Pullup in case the output is open-drain.
  pinMode(RTC_SQW, INPUT_PULLUP);
#endif

  pinMode(VIA_CA1, OUTPUT);
  pinMode(VIA_CA2, INPUT_PULLUP);
  pinMode(VIA_CB1, OUTPUT);
  pinMode(VIA_CB2, INPUT_PULLUP);
  pinMode(PS2CLK, INPUT_PULLUP);
  pinMode(PS2DATA, INPUT_PULLUP);

  digitalWrite(VIA_CA1, HIGH);
  digitalWrite(VIA_CB1, HIGH);
  
  attachInterrupt(digitalPinToInterrupt(PS2CLK), onInterrupt, FALLING);

#ifdef ENABLE_SQW
  // Configure the pin-change interrupt on PD6 (PCINT30) for the RTC SQW jiffy
  // clock, but do NOT arm it yet. Arming is deferred until SQW_BOOT_GRACE_MS
  // after RESB is released (see loop()) so a power-up 32.768 kHz SQW burst
  // cannot storm the 6502 with NMIs during the BIOS boot window.
  PCMSK3 |= _BV(PCINT30);
  PCIFR  |= _BV(PCIF3);   // Clear any pending flag
#endif

  // Power-on reset: keep the 6502 held in reset briefly so its supply and the
  // 16 MHz clock are stable, then release.
  delay(POR_HOLD_MS);
  releaseRESB();
#ifdef ENABLE_SQW
  resbReleasedAt = millis();
#endif
}

void loop() {
  // Handle the reset button (asserts RESB on the 6502 while held)
  handleReset();

#ifdef ENABLE_SQW
  // Arm the RTC SQW jiffy interrupt once the 6502 has had time to boot. This
  // protects the BIOS boot window from a power-up 32.768 kHz SQW NMI storm.
  if (!sqwIntEnabled && (millis() - resbReleasedAt >= SQW_BOOT_GRACE_MS)) {
    jiffyCount = 0;
    PCIFR |= _BV(PCIF3);   // Clear any flag accumulated while disarmed
    PCICR |= _BV(PCIE3);   // Enable PCINT[31:24]
    sqwIntEnabled = true;
  }
#endif

  // Bring both encoders into whatever state CA2/CB2 are asking for
  serviceEncoderEnables();

  // Scan matrix keyboard if enabled. A scan that reports back false was
  // abandoned because the 6502 asked for a port, so service that immediately
  // and start a fresh pass rather than running the output blocks first.
  if (matrixEnabled && !scanMatrix()) {
    serviceEncoderEnables();
    return;
  }

  // Handle PS/2 keyboard output on Port A. The character is only consumed once
  // it has actually been strobed, so one abandoned mid-write cannot be lost.
  if (ps2Enabled && !ps2Buffer.isEmpty()) {
    if (!writePortA(ps2Buffer.first())) {
      serviceEncoderEnables();
      return;
    }
    ps2Buffer.shift();
    if (!settleBetweenCharacters()) {
      serviceEncoderEnables();
      return;
    }
  }

  // Handle matrix keyboard output on Port B
  if (matrixEnabled && !matrixBuffer.isEmpty() && !matrixRowConflict()) {
    if (!writePortB(matrixBuffer.first())) {
      serviceEncoderEnables();
      return;
    }
    matrixBuffer.shift();
    if (!settleBetweenCharacters()) {
      serviceEncoderEnables();
      return;
    }
  }
}

// Poll CA2/CB2 and bring each encoder into the state the 6502 is asking for.
// Called at the top of loop() and again the moment any longer-running section
// notices a release request, so a port is never held past its budget just
// because the firmware was busy elsewhere.
void serviceEncoderEnables() {
  // Check PS/2 enable/disable (CA2)
  int ps2EnableState = digitalRead(VIA_CA2);
  if (ps2EnableState == LOW && !ps2Enabled) {
    enablePS2();
  } else if (ps2EnableState == HIGH && ps2Enabled) {
    disablePS2();
  }

  // Check matrix enable/disable (CB2)
  int matrixEnableState = digitalRead(VIA_CB2);
  if (matrixEnableState == LOW && !matrixEnabled) {
    enableMatrix();
  } else if (matrixEnableState == HIGH && matrixEnabled) {
    disableMatrix();
  }
}

// The settle gap the 6502 needs between strobes. Spent in short slices with a
// release check between each, rather than blocking for the whole 100 us, so a
// request arriving just after a strobe is still answered on time. Returns false
// if one arrived, in which case the caller must stop what it is doing.
bool settleBetweenCharacters() {
  for (uint8_t i = 0; i < 10; i++) {
    if (releaseRequested()) {
      return false;
    }
    delayMicroseconds(10);
  }
  return true;
}

// When two keys on the same row are held simultaneously, their switches bridge
// Port B columns through the shared row wire.  This corrupts anything driven on
// Port B because the ATmega's output drivers fight each other through that
// path.  Output is deferred until no row has multiple pressed keys.
bool matrixRowConflict() {
  for (uint8_t row = 0; row < 8; row++) {
    uint8_t count = 0;
    for (uint8_t col = 0; col < 8; col++) {
      if (matrixKeyState[row][col] >= MATRIX_DEBOUNCE_COUNT) {
        if (++count >= 2) {
          return true;
        }
      }
    }
  }
  return false;
}

// Drive a byte onto Port A and strobe CA1. Matrix scanning parks the row lines
// as inputs, so the direction has to be re-asserted on every write.
//
// Returns false if the 6502 asked for the port before the strobe went out, in
// which case nothing was signalled and the caller must keep the byte queued.
// This matters more than it looks: BASIC evaluating JOY() disables the encoders
// every time, so a release landing in the middle of a character write is a
// routine event rather than a rarity. Strobing a port that is about to be
// released would leave the 6502's ISR reading joystick lines and buffering them
// as a keystroke.
bool writePortA(uint8_t value) {
  // Nothing has been committed to the wire yet, so bail before touching the
  // port at all if the 6502 has already asked for it
  if (releaseRequested()) {
    return false;
  }

  // Value before direction: while the port is still an input this only sets
  // pullups, so the byte is never half-driven on its way out
  PORTA = value;
  DDRA = 0xFF;

  if (releaseRequested()) {
    return false;
  }

  digitalWrite(VIA_CA1, LOW); // Signal that data is ready
  delayMicroseconds(5);
  digitalWrite(VIA_CA1, HIGH);
  return true;
}

// Drive a byte onto Port B and strobe CB1. Port A (the row lines) is parked
// high-impedance first, so a single pressed key cannot short a driven column
// back into a driven row through its switch. Returns false without strobing if
// the 6502 asked for the port first -- see writePortA.
bool writePortB(uint8_t value) {
  if (releaseRequested()) {
    return false;
  }

  // Park the row lines as pulled-up inputs first
  DDRA = 0x00;
  PORTA = 0xFF;

  // Value before direction -- see writePortA
  PORTB = value;
  DDRB = 0xFF;

  if (releaseRequested()) {
    return false;
  }

  digitalWrite(VIA_CB1, LOW); // Signal that data is ready
  delayMicroseconds(5);
  digitalWrite(VIA_CB1, HIGH);
  return true;
}

void enablePS2() {
  ps2Enabled = true;

  // Set Port A as output for PS/2 data. PORTA already reads 0xFF from the
  // released state, so the lines idle high rather than briefly presenting
  // whatever was last driven.
  DDRA = 0xFF;
}

void disablePS2() {
  ps2Enabled = false;

  // Release Port A unconditionally: CA2 going high is the 6502 asking for the
  // port, and it is not conditional on what the matrix is doing. scanMatrix()
  // drives the row lines itself and parks them between passes, so there is
  // nothing here worth preserving for it -- whereas the old `if (!matrixEnabled)`
  // guard meant that with the matrix enabled this path never let go of Port A
  // at all.
  //
  // Parked with the internal pullups on, not bare, because this is exactly the
  // state the 6502 reads the joysticks in. Only the ACE Board carries the 1k
  // port pullups itself; on COB and VCS they arrive with a helper board, so a
  // port with nothing fitted would otherwise float and read as noise instead of
  // as an untouched stick. ~30k is far too weak to fight a joystick switch, or
  // a cartridge driving its own matrix rows.
  //
  // Straight at the registers: this is the tail of the release path the 6502
  // waits on, and eight pinMode() calls would add ~36 us to it for no reason.
  DDRA = 0x00;
  PORTA = 0xFF;
}

void enableMatrix() {
  matrixEnabled = true;

  // Port B carries column reading and data output; idle driving high
  PORTB = 0xFF;
  DDRB = 0xFF;

  // Port A is left as pulled-up inputs rather than driven. scanMatrix() takes
  // it a row at a time and writePortB() parks it, so nothing here needs it as
  // an output -- and driving it would put either all rows high against a
  // joystick holding one low, or all rows low against the columns.
  if (!ps2Enabled) {
    DDRA = 0x00;
    PORTA = 0xFF;
  }

  // Start a fresh sweep rather than resuming one abandoned before the matrix
  // was last disabled
  matrixScanRow = 0;
}

void disableMatrix() {
  matrixEnabled = false;

  // Release Port B, parked with the internal pullups on so the 6502 reads an
  // untouched stick as all-ones even on a board with no external pullups
  // fitted, and straight at the registers so the release is immediate (see
  // disablePS2 for both).
  DDRB = 0x00;
  PORTB = 0xFF;

  // Release Port A too if PS/2 is not using it
  if (!ps2Enabled) {
    DDRA = 0x00;
    PORTA = 0xFF;
  }
}

// ============================================================================
// Matrix Keyboard Scanning
// ============================================================================
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

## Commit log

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2026-05-28 Silkscreen fix
    [ACE Board.kicad_pcb]
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2026-07-31 Fix the firmware licence link, and the CF adapter's capacity
    The licence link pointed at Firmware/ACE Controller, which does not exist -- the
    folder is AB Controller, and it had no LICENSE either. Adds MIT there and corrects
    the link. The CF adapter was described as holding up to 1MB, which is one disk
    bank; the filesystem addresses 256 of them, so 256MB is the usable capacity.
    Refreshes the software table: WEBULATOR is archived, and the examples, listings,
    assets and tooling repositories were missing.
2026-08-01 Release the shared VIA ports so the 6502 can read the joysticks
    The AB Controller now hands PORT A and PORT B back to the CPU when CA2/CB2
    go high, so the 6502 reads the two Atari sticks straight off the raw ports
    the keyboard encoder shares with them — J6 JOYSTICK A on PORT A (JOY(2))
    and J8 JOYSTICK B on PORT B (JOY(1)).
    Also adds 6502 reset control on PC7 (holds RESB for ~250 ms at power-on,
    debounces the reset button on PC0) and an optional DS1511Y jiffy clock that
    pulses NMIB, compiled out unless ENABLE_SQW is defined.
    [fuses.cfg]
2026-08-04 Renumber the connectors and switches to match the schematic
    The README's reference designators drift from the board at J14 and again at
    SW14, so anyone cross-referencing this file against the schematic or the
    silkscreen is sent to the wrong part. Both the Rev 1.0 and Rev 1.1 schematics
    agree with each other and disagree with the README.
    Connectors: the README's J14-J22 values are the schematic's J15-J22 plus J14.
    KEYBOARD is J14, not J22, and — the one worth knowing — the 5V barrel jack is
    J17, not J16, which is AUDIO.
    Switches: the schematic numbers RESET as SW17, a push button inside the
    keyboard's own numbering just above Esc, which shifts every designator from
    SW15 up by one. The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
2026-09-18 Say where CTS EN and DCD EN belong, and what they do
    Both default to ground, which is how the board was built, and nothing recorded
    it. Ground means the line is permanently asserted, so the ACIA can always send
    and always receive.
    Measured on a real R6551 in 2026: CTS high stops the transmitter and DCD high
    stops the receiver, losing the arriving byte. Jumpered to the cable and plugged
    into something that does not assert them, the board shows no banner and no echo
    at all, and looks broken when it is only waiting.
2026-09-24 List the Rev 1.1 changes for the shared IRQB, RESB and NMIB lines
    A pico9918 drives /INT push-pull through a 74AHC126 enabled by RST, so on
    IRQB it fights the VIA, the ACIA and the clock. With a pico9918 PRO fitted,
    IRQB sat at 3.8 V while the VIA was asserting, above the 65C02's input-high
    threshold, and keyboard and serial input were both dead. A BAT85 on U3 pin
    16, cathode toward the card, fixed it on Rev 1.0; Rev 1.1 gets that diode.
    RESB gets a 10 k pull-up, and the AB Controller will drive PC7 open-drain
    so the DS1511Y and the CART and BUS connectors can reset the machine. NMIB
    needs a firmware change only, before ENABLE_SQW is ever turned on.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
2026-09-24 Release RESB with the ATmega's pull-up on, so the order does not matter
    The Rev 1.0 on the bench gets the 10 k pull-up as a bodge. With PC7
    released as INPUT_PULLUP, the open-drain firmware also works on a board
    without that resistor, so the bodge and the firmware can go in in either
    order. The 10 k still covers the time the ATmega is in reset or being
    programmed.
2026-09-24 Make the RESB pull-up optional on Rev 1.0, and drop the programming case
    The ATmega is never programmed in circuit on this board, so the 10 k is
    not there to cover that. With PC7 released as INPUT_PULLUP the internal
    pull-up raises RESB, and the DS1511Y or a card can still pull it low. The
    10 k is a stiffer pull-up, recommended on Rev 1.1 and optional on Rev 1.0.
2026-09-24 Drive RESB open-drain from the AB Controller
    RESB is shared with the DS1511Y's open-drain RST output and with the CART
    and BUS connectors, but PC7 drove it push-pull: an output written low to
    hold the 6502 in reset and written high to release it. While the ATmega
    held the line high, nothing else could reset the machine.
    assertRESB and releaseRESB now handle every write to PC7. Asserting clears
    the output latch and then makes the pin an output, so it goes straight to
    low. Releasing makes it an input with the internal pull-up on, which raises
    RESB by itself on a Rev 1.0 board with no external pull-up. Rev 1.1 adds a
    10 k pull-up on the board.
    Tested on the ACE Rev 1.0 with a pico9918 PRO on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
    [main.cpp]
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2026-09-24 TODO: the flashing and reset records for the README
    The PRO can be flashed in its socket with the ACE off, the stock firmware
    backup and restore commands, and the boot header after the reset button.
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2026-09-24 Fix the bank register decode, and run the ACE at 1 MHz only
    The bank latches loaded on 259 addresses each, not just $83FF and $87FF:
    U12B NANDed two active-low terms, which ORs them, so a write anywhere in
    $8300-$83FF or to $80FF-$82FF (and the same at $8400) changed the bank.
    Rev 1.0, Rev 1.1 as drawn and the first RAM Patch all had it.
    - Rev 1.1: a spare NOR (U23C) takes U12B's place.
    - ACE RAM Patch Rev 1.1: plugs into U12's and U13's sockets, since A8, A9
    and U17's output never reach U13's, and replaces both 74HC00s.
    - Rev 1.1 runs at 1 MHz only. J1 is gone and U5's Q3 clocks the CPU, VIA,
    ACIA and SID. At 2 MHz the SID, always on the 1 MHz tap, answered only
    every other cycle, an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
    [ACE Board.kicad_sch, ACE RAM Patch.kicad_pcb, ACE RAM Patch.kicad_sch]
2026-09-25 ACE Board Rev 1.1: the bank latch on two chips, re-annotated, PCB done
    - The latch logic uses eight gates on U12 (74HC00) and U13 (74HC02), the same
    gates as the ACE RAM Patch Rev 1.1. The IO1 inverter is a NOR now, which
    frees a whole 74HC00: Rev 1.0's second 74HC00 is gone.
    - Re-annotated: J2-J22 are J1-J21, D1-D3 are D2-D4, R5-R34 are R6-R35,
    C20-C30 are C21-C31, the bulk capacitor is C20, the /INT diode D1, the
    RESB pull-up R5, and the 74HC02 U13.
    - The PCB is updated from the schematic with every placed part where it
    was: no DRC errors, nothing unconnected, no schematic parity issues.
    Production files, the 3D model and the renders are regenerated.
    - Tests/check-schematics.mj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
    [ACE Board.kicad_pcb, ACE Board.kicad_sch, ACE Board.step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]
2026-09-25 ACE RAM Patch Rev 1.1: lay it out to mount under the ACE
    U12 and U13 come off the Rev 1.0 board, chips and sockets, and the patch is
    soldered underneath on pin headers, front side up. U1, J1, J2 and U2 sit in
    one row, 92.6 x 13.1 mm: J1 and J2 on the front, into U12's and U13's holes,
    and U1 and U2 on the back, hanging below. J2 is 23.00 mm from J1, and all 28
    header pins land on U12's and U13's pads on the Rev 1.0 board to 0.0000 mm.
    No DRC errors, nothing unconnected, no schematic parity issues, and power
    flags clear the schematic's ERC. Production files are generated as Rev 1.1,
    and their gerbers and drill files match the board shape for shape.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
    [ACE RAM Patch.kicad_pcb, ACE RAM Patch.kicad_sch, ACE RAM Patch.step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]
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2026-10-27 Retire TODO.md: what is still live moves into the README
    Every Rev 1.1 item in TODO.md was done and already in the README's
    revision list. What it still held now has a home in the README:
    - the video card's setup: 6502-PICOVDP on a PICO9918 PRO v2.0, BIOS 2.x,
    the MDE1 pin and the first-boot checks
    - building a Rev 1.0: the pull-ups, RESB, the /INT diode, J1, the RAM
    Patch and a centre-positive supply
    - the rule for cards on CART and BUS: pull the shared lines low only
    - the RAM Patch Rev 1.1's status and its bench test
    - known limits: the SID missed once at 1 MHz, the cycle-counted CF probe,
    and the untested ENABLE_SQW build
    The reasoning behind the 1 MHz decision and the shared-lin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
2026-10-27 ACE Board Rev 1.1: reverse-polarity protection on the barrel jack
    D5, a 1N5819 (DO-41), in series between the barrel jack (J16) and the
    power switch (SW69), anode at the jack: the same part and place as on the
    KIM Board. Rev 1.1 has not been produced, so the fix goes into it.
    The netlist differs from before only there: J16 pin 1 -> D5 -> SW69 pin 2.
    ERC and DRC are clean, nothing is unconnected, and check-schematics.mjs
    passes. The production files, schematic PDF, renders and STEP model are
    regenerated. The remaining silkscreen clearance warnings, which predate
    this change, are excluded in the project.
    The diode drops about 0.3-0.4 V, so VCC sits near 4.6 V; measure it under
    full load on t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
2026-11-03 Docs: build notes for the ACE Board Rev 1.0
    A printable guide to the work a Rev 1.0 needs beyond its bill of materials:
    the pull-ups, the ACIA, J1, the supply capacitor, the RESB firmware and
    pull-up, the /INT diode's socket stack and fitting the ACE RAM Patch Rev 1.1,
    then the meter checks and the first power-on.
    The list comes from comparing the Rev 1.0 and Rev 1.1 netlists, which found
    three things "Building a Rev 1.0" was missing: R25 is 10k, U4 is an R6551AP,
    and the 10uF supply capacitor. The README gains all three, and a link to the
    guide. The patch's fit and steps come from the PCB files and aren't yet
    confirmed on a real board, and the guide says so.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
2026-11-03 ACE RAM Patch Rev 1.1: verified on hardware, with a test for it
    Tests/check-ram.mjs is the hardware counterpart of check-schematics.mjs.
    Over the serial port, it restarts the machine and reads HW_PRESENT after
    each boot, then runs Tests/check-ram.asm: each latch loads only on its own
    address, and every bank of both windows holds its own patterns.
    Tests/check-ram-fault.cjs shows the test can fail, on the emulator.
    An ACE Board Rev 1.0 with the patch passed with every card fitted:
    HW_PRESENT $FF on 10 restarts, 0 failures in 3 runs. The README's Status
    line now says so.
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2026-11-04 ACE CF Adapter Rev 1.1: annotated, with an LCSC source for the CF socket
    Rev 1.0 was never annotated, so J21 and J3 came from another project. They are
    now J1 and J2.
    The socket gains LCSC C2962036, a HOAUC HYCW01-CF50-395B, in stock when this
    was written. Its datasheet matches the footprint Rev 1.0 uses, so the copper
    doesn't change. It hasn't been fitted to a board yet, and the README says so.
    Drawn, not ordered. Parity and DRC report nothing, and the top panel carries
    over.
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2026-11-04 ACE RAM Patch Rev 1.0: order Y94, and proven wrong
    The zip and PCB match JLCPCB's order. Testing showed the decode is wrong, and Rev 1.1,
    tested 2026-11-03, replaces it. REVISIONS gains the Tested column.
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2026-11-04 Board images: every revision rendered the same way
    Front and back, at 2400 x 1600, on white and with no background, in the black solder
    mask and white silkscreen the boards are made with. They replace images that came from
    two methods, in nine different sizes.
2026-11-05 BOM: one set of part numbers across AC6502
    Writes the shared parts catalogue into every schematic and PCB. Each part now
    has the same Digikey, Mouser, Jameco, LCSC and Other fields. Junk fields imported
    with library parts are gone, and so is MPN, because the Fabrication Toolkit
    falls back to it and put it in bom.csv's LCSC column.
    bom.csv is now an accurate BOM. Only card edges, solder jumpers and test points
    are excluded. A blank LCSC cell means JLCPCB doesn't place the part.
    Where the silk doesn't print it, Value says what to fit: BAT85, R6551AP, 33pF and
    so on. A do-not-fit resistor says so. Made boards whose silk prints an old value
    keep it, and the known issues in BOM.md will cover th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
2026-11-05 BOM.md: every part, by revision, with known issues and cart files
    BOM.md has a parts list for every revision, with Digi-Key, Mouser and other
    sources, how to tell which revision you have, and the known issues that change
    what to buy or fit. BOM/ holds a Digi-Key and a Mouser file for each revision.
    Revisions with soldered parts also have through-hole files that leave them out.
    The README's old BOM tables disagreed with the schematics, so they now link here.
    Revision histories and build notes stay in the README.
    Where the build notes say to fit something else, the lists now order that: 10k
    pull-ups on ACE Board 1.0, CPU Card 1.0, DEV Board 1.0 and Main Board 1.0 and 1.1,
    and no RESB pull-up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
2026-11-05 Everything derived from the boards, brought up to date
    Board images are re-rendered for every revision whose silk or fitted parts
    changed, so they show SERIAL (DTE) and the rest. The revision histories now say
    what changed on the silk, and wording that pointed at the old BOM tables is gone.
    3D model paths that led nowhere are fixed: old KiCad variables, a folder that no
    longer exists, and models KiCad 10 only ships as STEP. Those boards' STEP files
    and images now include all their parts.
    positions.csv no longer lists parts that aren't fitted. Made and ordered boards'
    fabrication exports are unchanged, and so are DRC and schematic parity.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
2026-11-05 BOM: 40- and 32-pin sockets get their part numbers; keyswitch model is blue
    BOM.md and carts: socket rows had no part numbers, because the generator
    looked up the wrong catalogue id.
    CherryMX model: stem is blue, matching MX2A-E1NA in the BOM. Images and
    STEP of the boards using it re-exported.
2026-11-05 Barrel jack: Same Sky PJ-102AH replaces the obsolete DCJ200-10-A-K1-K
    The manufacturer's footprint, rotated 180 degrees, has the same pad
    positions and body as BarrelJack_Horizontal. Only part fields, BOM.md and
    cart files change: Gerbers and drill files are identical. Not yet fitted
    to a board.
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2026-11-05 Library parts named for what they are, not a part number
    Footprints, symbols and 3D models in "6502 Parts" are named for their
    function and shape (RJ45 Jack LED, CR2032 Holder, 6502 Card Slot, Power
    Switch, SID, ACIA 6551, PIA 6521), so a replacement part with the same
    footprint needs no rename. Every repo carries the same copy of each part,
    re-saved by KiCad 10, and each symbol library holds every symbol its
    schematics use. VCS's 65C02 and 65C22 had wrong pin types; ACE's are now
    in all five. Unused DS01C-254-L-08BE and Mini-Black removed.
    Every revision's Gerbers and drill files export the same before and after.
    DRC is unchanged; ERC loses six missing-symbol warnings. Production files
    for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
2026-11-06 README: shared lines
    A Shared lines section, the same in all five KiCad repos: one 10k pull-up
    on each of RESB, IRQB, NMIB, RDY and BE, on the board with the CPU, and none
    on any other board, so two never sit in parallel. A board's own reset
    circuit pulls RESB low but never carries the pull-up.
2026-11-06 Schematics: bus connectors drawn one way; README: extra pins and HRDB
    Every 6502 bus, cart and card connector on every schematic, made revisions
    included, is drawn one way: a short wire and a global label on each used
    pin, a no-connect flag on each unused one, GND and VCC as global labels,
    and label shapes fixed per signal as the CPU sees it. Bus lines, bus
    entries and local labels for the bus are gone, which clears every "local
    and global labels have same name" ERC warning. Labels match the silk.
    Where bus pins 4 and 6 carry EXP1 and EXP0, or a cartridge grounds them, a
    note on the schematic says what HRDB (High ROM disable bar) does with them.
    The README's new Extra pins section explains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
2026-11-07 ACE Board 1.0: label shapes follow the signal
    Each global label's shape now shows which way the signal flows at the pin
    it is drawn on: output where it is driven, input where it arrives,
    bidirectional where both. The bus connectors take the board's view: a
    signal the ACE drives (addresses, RWB, SYNC, PHI2, RESB) flows into them,
    and one a card drives (IRQB, NMIB, RDY, BE, HRDB) flows out.
    The connector redraw had given every label one shape per signal name,
    which turned the address, RWB and PHI2 labels at chip inputs into outputs.
    This restores the original drawing's directions and corrects two of its
    slips: the RAM's data pins were outputs, and the VIA's CA1 (an input only)
    was bidirection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
2026-11-07 ACE Board 1.0: the ROM's data labels are outputs
    U8 is the AT28C256 ROM, and its /WE is tied to VCC, so its data pins only
    drive the bus. The original drawing had them as outputs, which was right;
    d9205f3 made them bidirectional, mistaking U8 for the RAM, and its message
    wrongly called the original a slip. The RAM is U7, and its data labels are
    bidirectional as they were.
    No connection changed: the netlist is identical and ERC is clean.
2026-11-07 Schematics: label shapes follow the signal
    Every global label's shape now shows which way the signal flows at the
    pin it is drawn on: output where it is driven, input where it arrives,
    bidirectional where both, passive for VCC and GND. A bus connector takes
    the board's view: on a board that drives the bus (a CPU board, a
    backplane) the addresses, RWB, SYNC, PHI2 and RESB flow into it and the
    interrupt and control lines come out; on a card a signal flows into the
    edge only if the card drives it (a clock, a reset, an interrupt through
    its diode and jumper) and out of it otherwise.
    The connector redraw had given each label one shape per signal name, so
    address, RWB and PHI2 labels at chip inpu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
2026-11-07 Schematics: drawn as KiCad draws by default
    - Every GND symbol shows its name, 3.81 mm below it, as KiCad places a new
    one: 128 hid it and most sat at 5.08 mm, an older default. Three moved
    aside by hand stay; one on the DEV Board sits left to clear a label.
    - A global label at 270 degrees is right-justified, as KiCad writes it, so
    the cart GND labels no longer lie over their own tie wire (ROM Cart,
    Flash Cart, Keypad Card).
    - CPU Card 1.0, 1.1 and Main Board 1.0: "Jumper ... for original 6502" is
    text on the sheet, spelled right, not a field on the jumper; the field
    is gone from the schematic and the PCB footprint. The schematic-to-PCB
    check is unchanged and every Gerber layer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
2026-11-07 README, BOM, REVISIONS: which revision to make, and the off-board headers
    Every revision now carries one of three labels, with a one-line reason:
    Tested, Proven design (not built at this revision, but its circuit is a
    tested revision's) or Untested. REVISIONS.md shows it in place of the old
    Tested column, BOM.md beside each revision, and a new README section,
    "Which revision to make", gives each board's newest revision and its label.
    All three are generated from one data file, so they can't disagree.
    A new README section, "Off-board headers", says what the small headers such
    as RESET SW, CLOCK ENBL SW, POWER LED and VCC are for: building a board into
    a case, with the case's parts wired to t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
2026-11-07 Tools/cad/: generate a machine's plate, mounting drawing and STL
    make.py writes CAD/Bases/Plate.svg, the mounting drawing and Plate.stl
    from CAD/Assembly.json, and --check, run by derived-check.py, fails when
    any is out of date. setup.sh makes the build123d venv the STL needs. This
    repository has no assembly file yet (CAD.md C7).
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2026-11-08 Tools/cad/: openings for ribbon-cable box headers; no loose acrylic
    Every box header for a ribbon cable (bus or GPIO) gets a 1.5 mm opening, as
    its plug comes up through the top (owner). A piece of a top that would hold
    no mounting hole is dropped into the opening round it, with a note.
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2026-11-09 Tools/cardedge/: cart holes at 5.0 and 13.0 mm; refilled pours are Proven
    The owner's ruling (KICAD.md K28): a cart's M3 holes go 5.0 mm from the top
    edge and the sides, its M2 holes 13.0 mm from the sides, each pair centred.
    They were 4.849 and 4.95 mm from the sides, a slip in Fusion 360. Proven
    design now covers pours refilled with DRC and the netlist check passing, as
    moving a card's outline refills its pours.
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2026-11-09 Board images: bare FR4 in its own colour, so a card's bare tab shows
    render.py drew the core with no colour, so KiCad showed bare board almost
    as dark as the black mask, and the cards' new mask-free tabs couldn't be
    seen. The core is now FR4 natural, which shows wherever there's no mask: a
    card's tab, and the thin ring where the mask stops short of a pad. Every
    image is rendered again; the masked areas are unchanged.
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2026-11-09 flow.py: a jumper to a rail sets a level; it drives nothing
    The card-edge PHI2 label on the Video Card pointed the wrong way, and
    derived-check passed it. flow.py took any jumper to VCC or GND for a
    source: JP2, which can tie U4's enable to VCC, sits behind JP1 on the
    PHI2 net, so the card seemed to drive PHI2 out to the bus. A jumper to a
    rail is now a pull-up or -down, as a resistor is, whether it ships open or
    bridged; a switch to a rail (a reset button) still drives. The rule in
    KICAD.md K25 is unchanged.
    That flipped both PHI2 labels on every card with a PHI2-enable jumper
    pair, made revisions included: COB RTC Card, VERA Helper and VGA Card
    1.0 and 1.1, VGA Card Pro 1.0, Video Card 1.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
2026-11-11 ACE Board 1.1: Rev 1.0's designators back
    A part keeps its designator from one revision to the next (owner, 2026-11-11). Rev 1.1
    was re-annotated from 1 on 2026-09-24; every part is now numbered as on Rev 1.0, matched
    by symbol UUID (108 references in the schematic and the PCB). Parts new in Rev 1.1 take
    numbers Rev 1.0 never used: D4 (BAT85, was D1), D5 (1N5819), R37 (RESB pull-up, was R5)
    and C31 (bulk capacitor, was C20). The 74HC02 keeps U13, the Rev 1.0 74HC00 it replaced.
    R1 and J5, removed, stay unused.
    The netlist is unchanged apart from names: the same 214 nets join the same pins. The 13
    auto-named nets (Net-(D1-K) and the like) are renamed in the PCB to match. The tracks
    are untou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
2026-11-11 ACE Board 1.1: PHI2 SELECT back as J1, and the ACIA's crystal jumpers
    J1, PHI2 SELECT, is restored from Rev 1.0 (owner, 2026-11-11): pin 1 is U5's 1 MHz
    output, pin 2 is PHI2 for the 65C02, VIA, ACIA, SID and both slots, pin 3 U5's 2 MHz
    output. 1 MHz is the standard; 2 MHz is the builder's risk. Unlike Rev 1.0, the SID
    follows J1, so at 2 MHz it no longer misses every other access. check-schematics.mjs
    now checks the clock at both J1 settings; a 2 MHz check of Rev 1.0 fails as it should.
    The ACIA gets the COB Serial Card's optional crystal parts: R38 (1M) across XTLI-XTLO
    through solder jumper JP1, and C32 (22 pF, SR151A220JAR) from XTLI to ground through
    JP2, both open for the R6551AP. Cl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
2026-11-11 ACE Board 1.1: J1's 1MHz and 2MHz labels, and its own text, as on Rev 1.0
    The '1MHz' and '2MHz' silkscreen labels were in the file but off to the side; they now
    sit at Rev 1.0's (218.5, 118.5) and (218.5, 128.5), the same text, size and justify.
    J1's reference and value text take Rev 1.0's placement too, which clears the overlap
    between '1MHz' and the reference. The silkscreen around J1 now renders the same as Rev
    1.0's. DRC: no errors, no unconnected items, parity clean; the 15 silk-overlap warnings
    are the ones the board already had.
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

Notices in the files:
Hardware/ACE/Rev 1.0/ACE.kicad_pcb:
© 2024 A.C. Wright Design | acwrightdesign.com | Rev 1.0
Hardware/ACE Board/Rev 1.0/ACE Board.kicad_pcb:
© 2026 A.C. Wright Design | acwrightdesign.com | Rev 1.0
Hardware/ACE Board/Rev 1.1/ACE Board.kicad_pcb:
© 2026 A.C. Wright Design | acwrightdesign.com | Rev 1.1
